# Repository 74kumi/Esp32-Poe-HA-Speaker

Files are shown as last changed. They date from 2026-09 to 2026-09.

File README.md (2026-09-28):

# ESP32 PoE Home Assistant Speaker

A PoE-powered network ceiling-speaker controller built around an **ESP32-S3**, **W5500 Ethernet**, **PCM5122 DAC**, and **TPA3116D2 amplifier**.

The long-term goal is a retrofit-friendly Home Assistant / voice-assistant speaker platform: reuse ordinary ceiling speakers, add network audio and control at the speaker, and optionally add a modular microphone-array ring hidden behind the existing grille.

## Project disclaimer

I'm not a hardware engineer — I'm an IT administrator who enjoys electronics, Home Assistant, and building things. I have a working understanding of many of the concepts involved, but this project has also been developed heavily with AI-assisted design, CAD scripting, and review.

I would genuinely welcome review or collaboration from experienced hardware engineers, especially as the project moves toward its first physical prototype.

This hardware is currently untested. It has not yet been fabricated, assembled, or electrically validated, and I cannot claim that the current design will work as intended. Please treat it as an engineering prototype, not a finished or proven product.

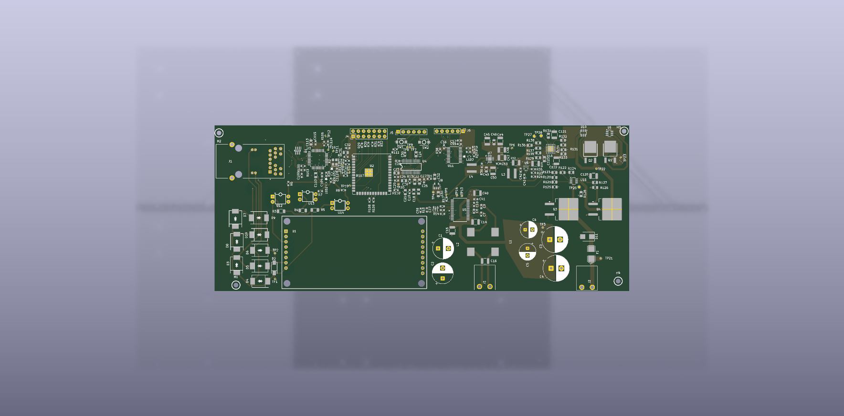
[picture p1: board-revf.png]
Final RevF manufacturing-release board preview


> **RevF manufacturing release:** this is the finalized manufacturing handoff for the RevE PCB design. The electrical CAD revision remains RevE for traceability; RevF identifies the released manufacturing package.
>
> The design has not yet been physically fabricated or electrically validated. PCBWay should confirm the final 4-layer stack-up and 100 Ω Ethernet impedance before production.

## Project status

| Area | Status |
| --- | --- |
| Main-board schematic / PCB | Rev E finalized design |
| KiCad source | Rev E source available directly in this repository |
| Saved ERC / DRC | Clean under the current saved rule profile |
| Ethernet layout | Finalized: 0.2764 mm / 0.20 mm target geometry |
| Power / protection | Finalized manufacturing package |
| Audio / amplifier | Circuit and thermal validation still required |
| Firmware | Bring-up firmware not yet complete |
| Home Assistant integration | Planned, not yet validated |
| Microphone array | Modular ring concept defined; PCB not yet designed |
| Physical prototype | Not built yet; fabrication package prepared |

A clean ERC/DRC result is a regression check, not proof that the circuit is electrically correct or fabrication-ready.

## Current hardware

The main board is intended to provide:

- ESP32-S3 controller
- wired Ethernet using W5500
- PoE-powered operation with bench-power support for development
- PCM5122 playback DAC
- TPA3116D2 speaker amplifier
- target of approximately **30 W into 4 ohms**, subject to real prototype validation
- programming / debug access
- expansion interfaces, including the reserved J4 microphone-ring connector

### Current Rev E board preview

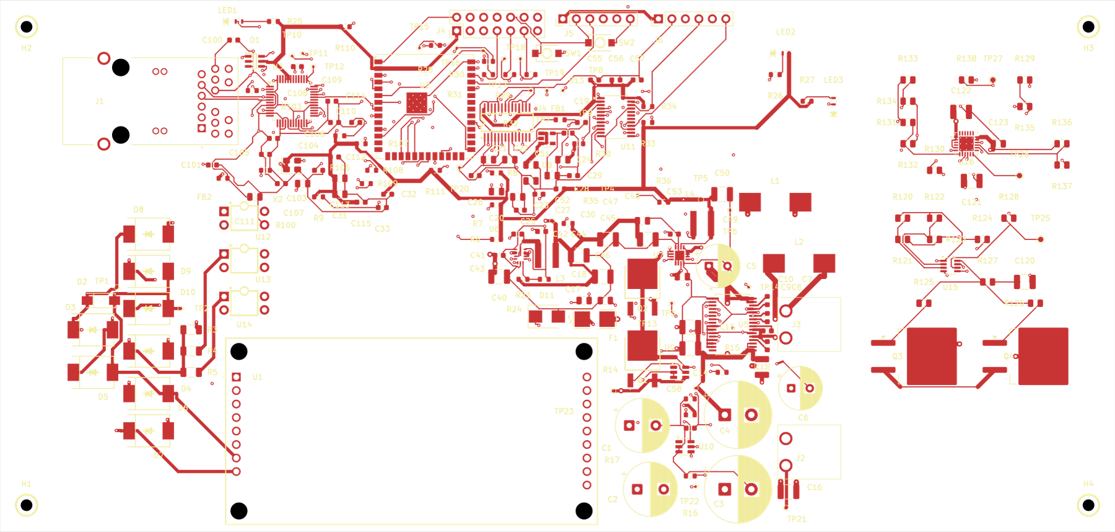
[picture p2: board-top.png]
Current Rev E board preview


The image above reflects the current Rev E board source more closely than the historical 3D render at the top of this README. The KiCad files remain the authoritative design reference.

### Open the Rev E design

The active source is tracked directly in Git:

- [Rev E KiCad project](hardware/PoE-Speaker/RevE/KiCad-RevE/PoE-Speaker-RevE.kicad_pro)
- [Rev E PCB](hardware/PoE-Speaker/RevE/KiCad-RevE/PoE-Speaker-RevE.kicad_pcb)
- [Rev E schematic](hardware/PoE-Speaker/RevE/KiCad-RevE/PoE-Speaker-RevE.kicad_sch)
- [Rev E engineering notes](hardware/PoE-Speaker/RevE/engineering/)
- [RevF manufacturing package](hardware/PoE-Speaker/RevF/Manufacturing/README-PCBWay.md)
- [RevF board preview](board-revf.png)
- [Historical design checkpoints](hardware/checkpoints/)

Open the project in **KiCad 10**. Keep the adjacent project-local footprint library, symbol library, tables, and design rules together.

## Modular microphone rings

A separate family of microphone-array rings is planned for retrofit installations. The idea is to select a ring diameter that fits behind an existing ceiling-speaker grille rather than designing a unique microphone system for every speaker model.

The first reference target is a nominal **8-inch ceiling speaker with an approximately 9-inch / 229 mm grille**. Ring Rev A is intended to target eight microphones and reserve space for visible listening / privacy status lighting behind the grille.

- [Microphone-ring concept](hardware/microphone-rings/README.md)
- [Listening / status-light plan](hardware/microphone-rings/LED-STATUS-LIGHT-PLAN.md)
- [Main-board J4 connector definition](hardware/PoE-Speaker/RevE/engineering/CONNECTOR-GUIDE.md)

Optional ring features are intended to use the existing J4 expansion interface rather than forcing repeated main-board redesigns.

## Engineering status and roadmap

The current release state is **RevF manufacturing package prepared**. PCBWay stack-up/impedance confirmation and normal prototype validation remain before production approval.

Highest-priority work includes:

1. Ethernet MDI differential-pair routing, reference continuity, termination / ESD geometry, and stackup assumptions.
2. PoE / bench input protection, startup, inrush, fault behavior, fuse coordination, and current-carrying paths.
3. PCM5122 / TPA3116D2 implementation, regulator behavior, grounding, output filtering, and thermal assumptions.
4. Footprint, courtyard, connector, heatsink, clearance, and assembly-process review.
5. Reproducible manufacturing outputs and a controlled prototype bring-up plan.

Project documents:

- [Roadmap](ROADMAP.md)
- [Engineering review guide](ENGINEERING-REVIEW.md)
- [Order / release review](ORDER-RELEASE-REVIEW.md)
- [Prototype validation plan](PROTOTYPE-VALIDATION.md)
- [Contribution guidance](CONTRIBUTING.md)
- [GitHub issues](https://github.com/74kumi/Esp32-Poe-HA-Speaker/issues)

## Repository layout

```text
.
├── docs/
│   ├── HISTORY.md
│   └── images/
│       └── early-board-render.png
├── hardware/
│   ├── PoE-Speaker/
│   │   └── RevE/
│   │       ├── KiCad-RevE/        # current editable board source
│   │       └── engineering/       # design reviews, calculations and scripts
│   ├── microphone-rings/          # future mic-array / status-light work
│   └── checkpoints/               # historical board revisions
├── ENGINEERING-REVIEW.md
├── ORDER-RELEASE-REVIEW.md
├── PROTOTYPE-VALIDATION.md
├── ROADMAP.md
└── board-top.png
```

## Contributing / reviewing

Engineering review is welcome, especially around Ethernet signal integrity, protection / fault behavior, power conversion, amplifier implementation, thermal design, footprints, and manufacturability.

When reporting a hardware finding, please include the affected revision, component / pin / net, location where practical, expected behavior, observed concern, and supporting datasheet section or calculation. Clearly distinguish confirmed defects from questions or suggested improvements.

See [CONTRIBUTING.md](CONTRIBUTING.md) for the current review priorities and main-board change policy.

This project has used AI-assisted CAD scripting and review workflows. AI output is not treated as engineering validation; independent review and physical prototype measurements are still required.

## License

Original hardware design materials are available for personal, educational, research, and other noncommercial use under the terms in [LICENSE](LICENSE).

Commercial manufacture, sale, OEM use, paid integration, or other commercial exploitation requires a separate written commercial license from the copyright holder.

Software, firmware, scripts, and third-party material may be subject to separate terms. Vendor references, library content, trademarks, and datasheets retain their respective owners' rights and notices.

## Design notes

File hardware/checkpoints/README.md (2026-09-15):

# Historical hardware checkpoints

This directory preserves earlier source snapshots for traceability while the active design continues under `hardware/PoE-Speaker/`.

These folders are **historical references**, not the canonical source to edit for new work and not manufacturing-release packages.

The imported checkpoint set includes earlier board stages such as the first-board draft, Rev C integrated draft, Rev D eFuse draft, and a frozen Rev E review snapshot.

The active Rev E source lives at:

`hardware/PoE-Speaker/RevE/`

The frozen Rev E checkpoint may initially match the active source byte-for-byte. Once active development continues, the two trees are expected to diverge; the checkpoint should remain unchanged so it can serve as a historical reference.

When starting new engineering work, use the active source and current root-level roadmap / review documents rather than these snapshots unless you are intentionally comparing revisions.

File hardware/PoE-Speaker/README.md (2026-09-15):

# Active PoE Speaker hardware source

This directory contains the **current active main-board design** for the ESP32 PoE Home Assistant Speaker project.

## Current revision

The canonical editable source is:

`RevE/KiCad-RevE/PoE-Speaker-RevE.kicad_pro`

Open it in **KiCad 10** and keep the project-local libraries, tables, design rules, and supporting files together.

The adjacent `RevE/engineering/` directory contains design-review notes, calculations, scripts, fabrication-process notes, connector documentation, and saved reports used during the Rev E engineering review.

## Source policy

- Active editable KiCad source belongs here.
- Historical board snapshots belong under `../checkpoints/`.
- Manufacturing-release outputs should be generated from a specific reviewed/tagged source revision and clearly identified as release artifacts rather than active design source.
- KiCad session/local-state files and editor backups should not be committed.

The current board remains an engineering prototype. A clean ERC/DRC result does not establish electrical performance, safety, signal integrity, thermal performance, or manufacturing readiness.

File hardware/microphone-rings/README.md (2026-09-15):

# Modular microphone-ring concept

## Purpose

The PoE speaker project is intended to support a family of microphone-array rings that can be adapted to many existing ceiling speakers without requiring a speaker-specific electronics design.

The concept is simple: remove the ceiling-speaker grille, choose the largest microphone ring that fits cleanly behind or within the grille, mount it around the speaker opening, route a small cable to the rear electronics, connect it to the main PoE speaker board, and reinstall the grille.

The microphone ring should be visually hidden once the grille is installed. The speaker itself remains the acoustic output device; the ring adds distributed microphones around the perimeter for room/voice capture.

This document describes the concept only. Ring PCB layouts, microphone selection, mounting methods, acoustic performance, firmware, and production dimensions are not yet validated.

## First reference speaker / Ring Rev A target

The first mechanical prototype will use a common **8-inch ceiling speaker with an approximately 9-inch (229 mm) overall grille diameter** as the reference test subject.

This reference is intentionally described by geometry rather than vendor/model. It provides a concrete starting point for the first ring while keeping the long-term goal of compatibility with many speaker families.

Initial Rev A assumptions:

| Parameter | Initial target / note |
| --- | --- |
| Nominal speaker size | 8 in |
| Measured overall grille diameter | ~9 in / 229 mm |
| Ring location | Behind the perforated grille, near the outer perimeter |
| Microphone orientation | Acoustic ports facing toward the room through the grille |
| Center opening | Keep the woofer/tweeter acoustic path substantially unobstructed |
| Microphone count | 8 target |
| Main-board interface | J4 |
| Cable routing | From ring toward rear electronics using an existing path where possible |

The **9-inch grille diameter is not the PCB diameter**. Before laying out the Rev A PCB, the grille must be removed and the actual usable inside diameter, frame lip, woofer surround clearance, grille-retention features, and available component depth measured. The PCB outside diameter should include installation clearance rather than attempting to fill the entire grille.

A practical first estimate is to target a microphone circle close to the largest clear diameter available behind the grille while keeping a narrow PCB annulus. Final OD/ID values should be based on direct measurements of the reference speaker, not the nominal 8-inch driver size.

## Design philosophy

The main PoE speaker board should remain common across installations. Speaker compatibility is handled mechanically by selecting a ring of the appropriate diameter.

Instead of making a different complete electronics system for every ceiling-speaker model, the project should eventually provide several ring diameters using the same electrical interface and microphone topology.

A useful installation should require as little modification to the existing speaker as practical:

1. Remove the speaker grille.
2. Measure the usable clear diameter behind the grille.
3. Select the largest ring variant that fits without interfering with the woofer, tweeter, grille attachment, mounting hardware, or speaker suspension.
4. Mount the ring to the grille/frame or to a small adapter using a reversible method where practical.
5. Route the ring cable toward the rear of the speaker. An existing opening is preferred. A new cable pass-through may be added only when doing so does not damage the driver, wiring, enclosure, fire rating, listing, or structural integrity of the speaker assembly.
6. Mount the PoE speaker electronics in an appropriate protected location behind/near the speaker.
7. Connect the microphone ring to the main board and reinstall the grille.

The result should look like an ordinary ceiling speaker from the room.

## Ring family

Ring sizes should be defined by geometry rather than by a specific speaker brand or model.

Each ring variant should eventually document at least:

| Parameter | Meaning |
| --- | --- |
| PCB outside diameter | Largest physical diameter of the ring PCB |
| Clear inside diameter | Opening available for the speaker cone/tweeter/acoustic path |
| Microphone-circle diameter | Diameter through the microphone acoustic ports |
| Microphone count | Intended number of microphones on the ring |
| Mounting envelope | Space needed for clips, adhesive mounts, screws, or an adapter |
| Maximum component height | Clearance required behind the grille |
| Cable exit | Location and direction of the ring cable/connector |
| Intended grille range | Approximate speaker/grille dimensions that can accept the ring |

Exact standard sizes are intentionally TBD. The first useful set should be chosen after measuring several common ceiling speakers rather than guessing from nominal woofer size alone.

A future naming scheme could use the microphone-circle or PCB outside diameter in millimeters so the name describes geometry rather than a vendor model.

## Electrical interface

The current Rev E main board reserves connector **J4** for the future microphone ring.

J4 exposes:

- 3.3 V power and grounds
- one shared `PDM_CLK`
- four PDM data signals: `PDM_DATA0_CONN` through `PDM_DATA3_CONN`
- `I2C_SDA` and `I2C_SCL`
- one spare ring GPIO

The project target is an eight-microphone ring. A likely implementation is to arrange compatible PDM microphones around the perimeter and use the four PDM data lanes for paired microphones, but the exact microphone parts, pairing method, clock rate, loading, cable constraints, connector implementation, and firmware capture scheme still require engineering validation.

The ring should not require a different main-board connector for each diameter. Electrically compatible ring sizes should be interchangeable.

## Mechanical goals

The microphone ring should:

- fit behind a perforated ceiling-speaker grille and remain visually unobtrusive;
- keep the center substantially open so it does not block the woofer or coaxial tweeter;
- avoid contact with the moving cone, surround, tweeter assembly, grille, or mounting dogs/clamps;
- tolerate speaker vibration without rattling;
- provide strain relief for its cable;
- support simple mounting methods such as clips, small standoffs, removable adhesive fixtures, or model-specific 3D-printed adapters;
- minimize required permanent modification to an existing speaker;
- allow multiple PCB diameters while keeping the same electrical design where practical.

A circular PCB is the default concept, but segmented or multi-piece rings may be considered if full circular PCBs become unnecessarily expensive at larger diameters.

## Acoustic goals and risks

The ring is intentionally close to a loudspeaker, which creates significant acoustic challenges. Mechanical fit alone is not sufficient.

Future prototypes need to evaluate:

- microphone self-noise and sensitivity through the installed grille;
- consistency between microphone positions;
- vibration mechanically coupled from the speaker/frame into the microphones;
- airflow and pressure effects near the woofer;
- acoustic shadowing caused by the speaker frame or grille structure;
- microphone saturation while the local speaker is playing;
- echo cancellation / speaker-reference requirements for simultaneous playback and voice capture;
- beamforming performance at different ring diameters;
- whether microphone spacing creates useful or harmful spatial aliasing over the intended voice band.

Ring diameter should therefore be treated as an acoustic parameter as well as a mechanical one.

## Installation and safety constraints

The goal is broad retrofit compatibility, not permission to modify every speaker indiscriminately.

Do not drill or modify a speaker assembly when doing so would compromise a listed backcan, fire/plenum rating, transformer enclosure, mains/high-voltage wiring, structural mounting, warranty, or other required safety feature. When an existing cable path is available, use it.

The microphone ring and main electronics also need an installation method that cannot fall into the occupied space if a grille or adhesive mount fails.

## Proposed development sequence

1. Fully measure the 8-inch / ~9-inch-grille reference speaker: usable grille ID, frame lip, clear ring area, depth, grille-retention features, obstructions, and cable-routing options.
2. Use those measurements to define Ring Rev A OD, ID, microphone-circle diameter, board width, component-height limit, mounting points, and cable exit.
3. Select and electrically validate the PDM microphone topology against J4.
4. Build Ring Rev A and prove microphone capture before producing every mechanical size.
5. Evaluate mounting approaches behind the reference grille.
6. Test microphone response with the local speaker silent and playing.
7. Evaluate beamforming / direction finding / voice capture and echo-cancellation requirements.
8. Measure several other common ceiling speakers and choose additional ring diameters that cover meaningfully different geometries.
9. Once the electrical design is stable, replicate the same circuit topology into those additional ring diameters.

## Relationship to the main board

The microphone ring is a separate future PCB from the Rev E PoE speaker main board. Development of the ring should not block first-prototype validation of Ethernet, power, DAC, and amplifier functions on the main board.

The current J4 interface is a design provision, not proof that an eight-microphone capture system is complete or validated.

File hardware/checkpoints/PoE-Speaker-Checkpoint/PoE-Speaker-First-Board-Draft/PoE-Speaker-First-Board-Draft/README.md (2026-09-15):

# PoE speaker — Revision B development

Open `PoE-Speaker-RevB.kicad_pro` in KiCad 10. This revision is **not ready for fabrication**. The original migration is preserved separately in `../KiCad-Recovered`.

## Changes implemented

- ESP32-S3-WROOM-1U-N16R8 and W5500 replace the original ESP32/RMII architecture. Four PDM data lines reserve support for eight microphones on a future separate ring. GPIO35–37 remain unused because the module uses octal PSRAM.
- J1 cable-side PoE pickup uses pins 13–16. PHY-side center taps 12 and 6 now belong to the W5500 interface. Pins 1 and 7 are unused.
- W5500 analog supply filtering, termination, reference resistor, reset delay, SPI damping and 25 MHz oscillator are included.
- C1–C6 now use physical radial capacitor footprints and specified Panasonic FR parts. L1–L4 use rated inductors and footprints constructed from manufacturer land patterns.
- TP10 and TP11 now expose SPI clock and MOSI.
- Local symbol and footprint libraries travel with the project. Thirteen editable schematic pages and 179 footprints are generated.

## Validation and limits

`reports/net-validation.json` compares the KiCad-exported schematic netlist and saved PCB pad assignments to the explicit revised model. This checks file generation and pin mapping; it does not prove that the circuit works. `reports/schematic-svg` contains KiCad-rendered sheets.

The board has a proposed 160 × 100 mm outline around the existing mounting holes. All 179 parts have been placed without expanded body-box overlaps. A local routing pass has produced actual editable copper; see `reports/first-board-draft.json` and `reports/board-drc.json` for the current counts and remaining findings. This is a **first layout draft**, not a production routing solution. Existing recovery copper was not copied because it does not implement the revised circuit.

The initial router uses 0.2 mm traces and 0.15 mm fine-pitch escapes. Those widths are **not a validated power-distribution design**. High-current paths, ground planes, Ethernet differential-pair geometry, isolation and heat flow still require dedicated routing work. Do not order this draft.

Most recovered components still use generic pin-block symbols with passive electrical pin types. ERC is therefore incomplete as a circuit check. Power-source pin modeling remains outstanding; do not suppress those errors as a substitute for reviewing the power circuit.

## Work remaining before release

1. Complete power and protection audit: PoE bridge reverse-voltage margin, Ag5800 series outputs, ORing, regulator compensation/layout, amplifier PBTL configuration and thermal limits.
2. Review remaining source component pin types, actual part numbers, voltage ratings and footprint pin mappings. Replace generic schematic graphics with conventional symbols where practical.
3. Refine placement for switching loops, isolation and audio performance. Verify mechanical clearances, mounting hardware and connector access.
4. Replace provisional power and Ethernet routes with qualified geometry; add appropriate planes/thermal vias and isolation clearances, choose a fabrication stackup and verify Ethernet impedance.
5. Resolve electrical and board checks without hiding findings. Produce fabrication and assembly outputs only after those checks pass.
6. Implement and bench-test firmware for simultaneous four-line PDM capture, DAC playback, SPI Ethernet and PoE power limiting. Speaker selection and microphone-ring geometry remain future inputs.

## Reproducibility

Run `engineering/design_revision.py`, then `engineering/build_revision.py` with KiCad's Python from the project root. Export a KiCad XML netlist to `reports/schematic-netlist.xml`, then run `engineering/validate_revision.py`. `engineering/place_draft.py` creates the placement and Specctra input; `engineering/finish_draft.py` imports the locally generated routing session. **The builder discards later placement and routing when rerun. Preserve the routed board before rebuilding.**

## Reference documents

- [ESP32-S3 module datasheet](https://www.espressif.com/sites/default/files/documentation/esp32-s3-wroom-1_wroom-1u_datasheet_en.pdf)
- [ESP32-S3 peripheral capability definitions](https://raw.githubusercontent.com/espressif/esp-idf/master/components/soc/esp32s3/include/soc/soc_caps.h)
- [W5500 datasheet](https://docs.wiznet.io/img/products/w5500/W5500_ds_v110e.pdf) and [reference circuit](https://docs.wiznet.io/img/products/w5500/w5500_sch_v110_use_mag_.pdf)
- [Bel 2250506 connector drawing](https://www.belfuse.com/media/drawings/products/magjack%20ICMs/dr-mag-2250506.pdf)
- [Bourns SRP1038A](https://www.bourns.com/docs/product-datasheets/srp1038a.pdf): 13.6 mm overall land span, 5.4 mm inner gap, 3.5 mm land height.
- [Coilcraft XAL50xx](https://www.coilcraft.com/getmedia/49bc46c8-4b2c-45b9-9b6c-2eaa235ea698/xal50xx.pdf): 3.31 mm pad-center pitch, 1.18 × 4.70 mm lands.
- [Abracon ASE oscillator](https://abracon.com/Oscillators/ASEseries.pdf)
- Panasonic [EEUFR1E102](https://industrial.panasonic.com/ww/products/pt/aluminum-cap-lead/models/EEUFR1E102), [EEUFR1V102](https://industrial.panasonic.com/ww/products/pt/aluminum-cap-lead/models/EEUFR1V102), [EEUFR1H101](https://industrial.panasonic.com/ww/products/pt/aluminum-cap-lead/models/EEUFR1H101).

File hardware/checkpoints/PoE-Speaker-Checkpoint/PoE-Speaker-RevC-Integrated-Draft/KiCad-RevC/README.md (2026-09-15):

# Revision C — integrated prototype development

Open PoE-Speaker-RevC.kicad_pro in KiCad 10. This is an editable engineering draft, not a board approved for manufacture or power-up. Revision B is preserved separately.

Implemented: bench-input LTC4365HTS8 disconnect, two PSMN4R8-100BSE pass MOSFETs, UV/OV dividers, controlled-startup candidate network, bidirectional input TVS selection, fault test point, and amplifier shutdown pulldown. The protection schematic is integrated into the project and its connections are routed. The provisional outline is expanded to 210 x 100 mm; mounting and enclosure fit are not final.

Added a partial secondary-side In1.Cu ground plane from x=140 to 279 mm, leaving the Ethernet area outside this plane. Widened 14 new power-route segments to 0.8 mm where DRC permitted. Improved reference placement and turned schematic net labels outward for readability. Source symbols remain boxed pin representations.

Verification: 194 footprints, 575 connected pins match the design model, zero unconnected items, no reported shorts or PoE isolation-rule findings. The preliminary 3 mm rule is not an insulation certification. See reports/revision-status.json and board-drc.json for exact counts. ERC retains four undriven power-input findings and many source pin types remain unreviewed.

Release blockers:

- Short-circuit current limiting, fuse coordination, and repetitive-fault heating are unresolved. The startup ramp is not a fault current limiter.
- Confirm gate-drive capability, MOSFET hot SOA, actual startup loads, amplifier-disable sequencing, and bench/PoE backfeed using the complete circuit.
- Finalize resistor/capacitor/TVS order codes, tolerances, voltage ratings, and transient envelope. Several new passive MPNs remain TBD.
- Six U15 pad-spacing findings reflect 0.15 mm footprint gaps against the 0.20 mm project constraint; qualify the fabrication process/land pattern. Do not simply suppress them.
- Resolve 57 narrow-track findings and 12 ESP32 footprint drill findings. Widths and via current capacity are not thermally qualified.
- Finish Ethernet impedance/return paths, switching-loop layout, ground/thermal copper, silkscreen, mechanical fit and remaining source circuit review.

No manufacturing Gerbers are included. The PNG is a routing preview with F.Cu, In2.Cu and B.Cu; the inner ground plane is intentionally not shown in that view.

Preservation: build_protection_revision.py regenerates the initial placement and will overwrite this layout if rerun. Copy/archive this project before regeneration. Subsequent routing, fill, width and label changes are in the saved PCB and separate engineering scripts.

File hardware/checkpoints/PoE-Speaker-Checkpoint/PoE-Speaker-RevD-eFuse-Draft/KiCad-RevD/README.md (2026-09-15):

# Revision D — shared current protection draft

Open PoE-Speaker-RevD.kicad_pro in KiCad 10. This editable development board is not approved for fabrication or power-up. Revisions B and C remain preserved.

Added TPS26630RGER after the bench/PoE ideal-diode junction, feeding all original 24V_AMP loads. The circuit targets a nominal 2.98 A current limit, latch-off behavior, controlled startup and power-good amplifier shutdown interlock. TP26 is the shutdown/reset point; TP27 exposes the fault output. See engineering/EFUSE-REVIEW.md for calculations and limitations. Eight microphones remain assigned to a future separate ring board.

The 210 x 100 mm provisional outline is unchanged from C. Retained routes were reused except the two nets split by this change. The secondary In1.Cu ground plane now extends under Ethernet while excluding the lower-left primary/module region. See reports/secondary-ground.png. The routing preview omits that plane so signal routing is visible.

Validation: all 616 connected model pins match both the schematic netlist and PCB pad nets. Specific checks confirm the eFuse supply split and amplifier interlock. Exact physical and electrical findings are below; an empty ratsnest does not establish electrical correctness. Most imported symbols still use boxed pin representations, and source electrical pin types need further review.

Release blockers: resolve remaining DRC and ERC findings; qualify high-current widths/vias and thermal copper; finish Ethernet impedance and return paths, switching loops, input transient/fuse coordination, hot-start and overload behavior, and exact passive order codes. U15 now uses the manufacturer-recommended 1.22 x 0.40 mm lands at 0.65 mm pitch. All narrow-track escapes have been repaired without relaxing rules. The 21 thermal vias are covered by a scoped 0.20 mm drill-process rule; see engineering/FABRICATION-PROCESS.md. DRC is clean under that documented profile, but assembly via treatment and final stackup require confirmation. The enclosure, mounting and final speaker are not fixed. No manufacturing release is included.

Do not rerun build_efuse_revision.py on this routed folder without first archiving it: generation recreates placement and removes later routing work.

## Saved validation counts

- revision: D shared eFuse development draft
- components: 209
- board_mm: [210, 100]
- track_segments: 2101
- vias: 264
- ground_zones: 1
- unconnected_items: 0
- drc: {}
- erc_findings: 5
- poe_isolation_findings: 0
- fabrication_ready: False

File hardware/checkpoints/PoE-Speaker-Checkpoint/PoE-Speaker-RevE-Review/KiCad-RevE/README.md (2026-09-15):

# Revision E — prototype review checkpoint

Open PoE-Speaker-RevE.kicad_pro in KiCad 10. This is the latest editable board. Earlier revisions remain preserved. NOT APPROVED FOR ORDERING OR POWER-UP.

Saved changes: C11 GVDD bypass is now local on B.Cu at (204.9,111.5), preserving the R15 PLIMIT branch; underside assembly clearance remains part of mechanical review. U7 FSW now connects to 3V3 per TI guidance; all previously missing passive/header order codes have documented candidates; C120/C121 use stable 100nF 100V C0G 1210 parts and C122 uses a 1uF 100V 1210 part. C17/C18 are a matched 2.2uF 25V pair. U5 is TPA3116D2DADR, U9/U10 are LM5050MK-2/NOPB, and Ag5800 is confirmed as the complete U1 code. Corrected 34 footprint assembly attributes and widened 51 power segments to 0.8mm where existing clearance permits.

Validation: zero DRC findings, zero unconnected items, zero ERC findings under the saved rule profile. All 616 connected model pins match schematic and PCB. U6/U7 electrical pin types are reviewed; the root sheet declares power sources after passive elements. These annotations do not prove circuit performance, and other imported pin types remain incomplete. See reports/power-source-review.json. Missing courtyard and some metadata checks remain disabled in the inherited profile; clean DRC does not substitute for physical review.

Remaining work before a prototype order:

1. Reroute the remaining narrow loaded power paths, review via current capacity and local switching loops. reports/power-routing-audit.json contains exact positions and UUIDs; separate low-current sense branches from load trunks before modifying them. The two longest 24V_AMP sections (49.385mm and 39.837mm) have now been rerouted at 1.0mm width. A new continuous 1.0mm feed from C5 to the amplifier supply bypasses the congested narrow branch using two 0.5mm drilled vias. The original branch remains in parallel. See engineering/REVE-TRUNK-ROUTING.md; the whole path is not yet current-qualified.
2. Qualify Ethernet differential routing against the explicit JLC04161H-7628 design baseline and verify continuous return paths. See engineering/ETHERNET-STACKUP.md; the calculator-derived Ethernet100 routing preset is saved, but copper still needs rerouting and fabrication confirmation.
3. Review input fuse/transient coordination, capacitor effective capacitance and regulator stability, and amplifier supply tolerance. F1 DC interrupt ratings are now sourced; source/fault and time-current coordination remain open (engineering/FUSE-RATING-REVIEW.md).
4. Fit a top heatsink to the TPA3116D2 DAD package, check the Ag5800 thermal interface, body clearances, mounting support and connector access. H3/H4 now support the extended right edge at x=275; use insulating M2 standoffs. Thirteen assembly components still need verified courtyard/body review.
5. Produce and inspect Gerber, drill, assembly BOM and placement files only after those design checks; obtain fabricator stackup/via-treatment constraints. No manufacturing files or order submission are included in this checkpoint.

After assembly: staged current-limited bring-up, rail/startup/overload measurements, firmware and audio/Ethernet tests. Those are prototype validation activities, not prerequisites that can be completed without hardware. The eight-microphone ring remains a future separate board; this board is not a completed eight-microphone capture system.

Preserve routing: do not run build_revision.py or build_efuse_revision.py over this folder. For schematic-only updates run refresh_prototype_schematic.py, then annotate_prototype_power.py, export netlist/ERC and run validate_prototype.py. Editing model metadata alone does not update the schematic.

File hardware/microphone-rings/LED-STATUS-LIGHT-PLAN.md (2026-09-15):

# Microphone-ring status / listening light plan

## Purpose

Future microphone-array rings should reserve support for visible status lighting behind the ceiling-speaker grille. The primary use is a subtle **listening indicator** so a person in the room can tell when the microphone system is active.

The lighting feature belongs to the microphone-ring assembly, not the main PoE speaker PCB. Different ring diameters should use the same control concept wherever practical.

This is a planning document. LED part selection, LED count, driver choice, brightness, diffuser behavior, current budget, and firmware behavior are not yet validated.

## Main-board design-freeze rule

The Rev E / Rev F main PoE speaker board should not be redesigned for optional ring features unless the existing expansion interface cannot safely support a required function.

For microphone-ring lighting, the existing J4 interface is the intended path. J4 already exposes:

- 3.3 V and grounds;
- `I2C_SDA` and `I2C_SCL`;
- `RING_GPIO_SPARE`;
- the PDM microphone clock/data signals required by the microphone ring.

Optional user-interface features should therefore be implemented on the ring using J4 before considering changes to the main board.

A proposed main-board change for a ring feature should identify:

1. the feature that cannot be implemented through the existing interface;
2. the electrical, safety, bandwidth, power, or reliability reason it cannot be implemented there;
3. the minimum main-board change required; and
4. how the change will be verified.

Convenience alone is not sufficient reason to reopen the main-board design.

## Intended visual states

The exact colors and behavior remain firmware/UI decisions, but the ring should be capable of communicating a small set of obvious states.

| State | Example indication | Intent |
| --- | --- | --- |
| Listening / microphones active | soft blue or white | visible privacy/status indication |
| Muted / privacy mode | red | microphones intentionally disabled |
| Boot / setup / provisioning | amber, purple, or slow pulse | temporary service state |
| Fault / attention required | red or amber pattern | diagnostic indication |
| Normal idle | off by default | avoid unnecessary room light |

The final behavior should favor clear status communication over decorative effects.

## Electrical approach

Do not assume that the ESP32 or J4 spare GPIO will directly drive the LEDs.

The preferred architecture is for the microphone ring to contain its own small LED-control stage, using either:

- an I2C LED driver;
- a small ring-local controller; or
- another low-current control method compatible with the existing J4 signals.

The main board should send state information; the ring should handle LED current and sequencing locally.

The exact implementation must be chosen only after the available **3.3 V current budget at J4** is verified. The current design documentation does not yet establish how much additional LED load J4 can safely supply.

Until that budget is known, Ring Rev A should assume modest indicator lighting rather than a high-current decorative RGB ring. Full-brightness addressable RGB operation must not be assumed safe merely because 3.3 V is present on J4.

If the available J4 power budget is insufficient, first evaluate reducing LED count/current or adding appropriate ring-local power handling before reopening the main-board design.

## Mechanical / optical goals

Status LEDs should be placed so that light is visible through the perforated speaker grille while the PCB itself remains hidden.

Design goals:

- distribute light around the ring rather than create one bright point;
- avoid direct glare when viewed from below;
- avoid light leaking into the speaker cavity in a way that is distracting;
- keep LEDs and optics clear of microphone acoustic ports;
- avoid blocking useful grille perforations in front of microphones;
- support different ring diameters without changing the main-board interface;
- allow brightness to be reduced substantially for dark rooms.

The grille itself may provide useful diffusion, but this must be tested on real speakers because grille hole size, paint, backing cloth, and spacing vary.

## Ring Rev A requirements

The first ring for the nominal 8-inch speaker / ~9-inch grille reference installation should reserve for status lighting from the beginning.

Before PCB layout is frozen, Rev A should define:

- candidate LED locations around the ring;
- routing/footprint space for the chosen driver or local controller;
- LED-control connection to J4 through I2C and/or `RING_GPIO_SPARE`;
- estimated worst-case and normal LED current;
- microphone-to-LED spacing so lighting components do not compromise acoustic-port placement;
- a firmware-safe default state where LEDs are off until intentionally enabled.

The first prototype does not need elaborate animations. Proving a uniform, low-brightness listening indication through the installed grille is sufficient.

## Validation

Prototype testing should record:

1. J4 supply voltage and current with LEDs off and at intended maximum brightness;
2. whether LED operation introduces noise into PDM microphone capture;
3. whether PWM or digital LED traffic couples into audio or microphone signals;
4. light uniformity through the installed grille;
5. visibility in normal room lighting and in a dark room;
6. temperature rise of LED/driver components;
7. whether the listening/mute indication remains understandable from typical room viewing positions.

Any LED implementation that materially degrades microphone performance should be revised even if the visual result is good.

## Relationship to the microphone-ring family

Status lighting is a shared capability of the ring family, not a reason to create electrically incompatible ring sizes. Mechanical dimensions may change with speaker/grille size, but compatible rings should retain the same J4 interface and status-control behavior wherever practical.

The long-term goal is that selecting a different ring diameter changes the mechanics, not the main PoE speaker board.

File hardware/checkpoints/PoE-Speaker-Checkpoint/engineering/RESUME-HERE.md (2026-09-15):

# Resume checkpoint

Latest: KiCad-RevE/PoE-Speaker-RevE.kicad_pro and PoE-Speaker-RevE-Review.zip. Read KiCad-RevE/README.md first. Zero DRC, zero unconnected, zero ERC; 616 connected pins validated. No missing candidate order codes, but procurement and circuit qualification remain incomplete. Revisions B/C/D preserved.

Next: inspect RX ESD/termination branches and reference continuity, then finish TX_P layer/coupling. The RX trunk now has 8.379 mm of parallel routing at the sourced 0.225806 mm width / 0.2032 mm gap and a direct PHY approach; see reports/rx-coupled-trunk.json. The coordinated TX_N fanout and replacement B.Cu analog-supply path now allow all five receive In2 segments onto F.Cu; accepted with clean DRC and connectivity. See reports/ethernet-front-corridor.json. Existing bottom termination/ESD branches remain. Reroute using the sourced Ethernet100 preset (0.225806 mm width / 0.2032 mm gap), F.Cu over In1 GND on JLC04161H-7628; see engineering/ETHERNET-STACKUP.md. The main board now has explicit dielectric/copper settings, but impedance is not qualified. RX termination R104/R105/C102 is now a compact B.Cu cluster near U3, with twelve obsolete spur items removed and a checked local ground via (reports/rx-termination-placement.json). Main pair routing remains unqualified. Prioritize this and the concrete release blockers in engineering/ORDER-RELEASE-REVIEW.md. Mounting and eight rectifier courtyards are updated. After that, review remaining amplifier ground-pin-to-plane paths using reports/amp-ground-plane-paths.json, especially pin 1 and pins 9-11. Pin 13 now has a short 0.35 mm connection to the existing C11 ground via, improving the lower ground group; the pin 1 via trial was rejected and removed. A new via at (209.88,112.453) gives pin 22 local filled-plane access; downstream return impedance and continuous current corridors remain unqualified. Twenty-one direct ground-pin track segments were widened to 0.25-0.4 mm with clean DRC; this includes tiny stubs and does not qualify complete ground returns (reports/amp-ground-pin-widths.json). C14/C15 now have accepted local 0.8/0.4 mm ground vias with 1.1 mm, 0.6 mm wide links; both contact the filled In1 GND zone (reports/c14-c15-ground-vias.json). Use reports/amplifier-ground-access.json; it is a geometry inventory, not return-loop qualification. C5/C6 plated through-hole grounds must be assessed for direct plane access rather than distance to separate vias. Six constrained load-path vias remain. Twelve load-path vias have accepted larger drills/copper pads, including the relocated eFuse output via; see reports/power-via-review.json. Via current ratings still require plating and stackup assumptions. Four remaining load-neck segments are now 0.6 mm; the 0.3 mm wide, 0.5 mm long U16 output pin escape remains to preserve adjacent-pad clearance. See reports/load-neck-width-trial.json and reports/supply-path-audit.json. Continue amplifier review using reports/amplifier-decoupling-audit.json. C11 is accepted on B.Cu at (204.9,111.5), angle 270, with a local GVDD connection and a separate ground via. The R15 PLIMIT branch is preserved. Five obsolete C11 spur items were removed; see engineering/REVE-TRUNK-ROUTING.md. Continue amplifier decoupling and output-current/ground-return qualification. C13 is now local on F.Cu at (213.5,119); C12 is on B.Cu at (207.4,104) with a short connection through the existing supply via. Account for underside assembly and enclosure clearance. All four bootstrap capacitors now have accepted local F.Cu connections. C8 required an In2.Cu output detour with two 0.5mm drilled vias and a short 0.6mm approach that still needs current/thermal qualification; see reports/bootstrap-routing-audit.json and engineering/REVE-TRUNK-ROUTING.md. The main board is clean. Use the named main board, not temporary trial files. Both audited bench load paths now have at least 0.6mm tracks throughout, with no track below 0.5mm; current/via/thermal qualification remains; see reports/supply-path-audit.json. Three more 0.6mm bench approaches are accepted, and the ESP32 3V3 feed is at least 0.6mm throughout. Then complete Ethernet stackup/routing, fuse/transient/stability and thermal/mechanical review. Do not claim manufacturing ready from zero rule-check counts. No Gerbers/order submission yet. Firmware and ring board are not completed.

Schematic update: refresh_prototype_schematic.py followed by annotate_prototype_power.py; regenerate netlist/ERC and validate_prototype.py. Model: engineering/revision-e-design.json. Most useful current scripts contain prototype in their name. Source capacitor PDFs are in engineering/sources/prototype-capacitors. Checkpoint ZIP includes source, model, scripts and reports.

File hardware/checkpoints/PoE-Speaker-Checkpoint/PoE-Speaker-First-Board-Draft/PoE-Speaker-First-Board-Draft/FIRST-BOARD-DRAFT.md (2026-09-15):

# First board draft — review copy

Open `PoE-Speaker-RevB.kicad_pro` in KiCad 10. **Not for fabrication or power-up.**

The 160 × 100 mm draft contains 179 placed footprints, 1814 track segments and 222 vias. KiCad reports 0 unconnected items. The saved schematic and PCB pad assignments match the revised electrical model.

The body-box placement check passes. This is an initial placement and routing study; it does not validate enclosure fit, circuit operation or manufacturability.

## Current checks

| KiCad finding | Count |
|---|---:|
| drill_out_of_range | 12 |
| silk_edge_clearance | 1 |
| silk_over_copper | 84 |
| silk_overlap | 81 |
| track_width | 57 |

## Before a prototype order

- Complete the PoE and bench-input protection changes described in `POWER-REVIEW.md`.
- Redesign high-current routes. Net-specific wider trunks still have narrow escapes and unqualified vias and return paths.
- Add and review ground planes, isolation boundaries and thermal copper. Check buck and amplifier switching loops.
- The explicit 3 mm primary-to-secondary copper review rule now has zero findings. This is a preliminary layout target, not an insulation certification.
- Qualify or replace the U5 pin 27 via-in-pad escape for assembly and current capacity.
- Route Ethernet pairs to the chosen stackup and impedance requirements.
- Complete pin-type/ERC review, silkscreen cleanup and footprint/manufacturing checks. The ESP32 module footprint includes 0.2 mm thermal holes against a current 0.3 mm board constraint; resolve the footprint/process choice.
- Verify all release checks, then generate fabrication outputs. No manufacturing Gerbers are included in this review package.

The microphone ring remains a separate future board. The mainboard reserves its eight-microphone interface.

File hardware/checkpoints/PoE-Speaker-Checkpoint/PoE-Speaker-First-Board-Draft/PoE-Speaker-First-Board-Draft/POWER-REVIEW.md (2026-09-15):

# Power review — 2026-09-11

Status: in progress, not a release approval.

## Layout pass after the first draft

115 power trunk segments longer than 2 mm were widened to preliminary targets of 0.6–1.5 mm according to net function. Ninety-two other attempted changes conflicted with existing copper and were reverted. Short escapes, vias and return paths remain unqualified; this does not establish the current capacity of a complete path. The final standard-clearance check retained zero unconnected items and no shorts/crossings.

An explicit 3 mm primary-to-secondary copper review rule now identifies 16 spacing findings. This target is a conservative layout assumption, not a certified creepage/clearance requirement. The optocoupler placement and routing need particular attention: some primary pins face toward the secondary circuitry, and the router passed secondary tracks near primary through-hole pads. Reorient the optocouplers and reroute their paths while preserving the electrical pin map. Also review the Ag5800 underside barrier against the manufacturer's drawing. The module's dielectric rating alone does not qualify the carrier PCB.

The active KiCad DRC report includes the stricter rule; the earlier ordinary 0.2 mm clearance result is retained separately as `reports/standard-clearance-drc.json`.

## Corrected in the design model

**PoE class detection:** R6, R7 and R8 were connected from the PC817 collectors to GND. The emitters are also grounded, so that arrangement cannot generate the intended high logic level when the optocouplers are off. Resistor pin 2 now connects to 3V3. Detection is active low. Firmware must use that polarity.

**5 V buck:** U6 is LMR33630AQRNXRQ1, RNX VQFN. Pin 3 was marked NC and left open. TI's pin-function table explicitly requires this package's NC pad to connect to SW. Pin 3 now joins BUCK5_SW with pin 12. The bootstrap loop must be kept short in layout. [TI datasheet, section 5](https://www.ti.com/lit/ds/symlink/lmr33630-q1.pdf)

## Connections checked, retained

- Ag5800: output 1 is between POE_12V_MID and GND; output 2 is between 24V_POE and POE_12V_MID. C1 and C2 each span their respective output with positive polarity toward the higher voltage. This is the intended series-output arrangement. [Silvertel datasheet, sections 4 and 5.11](https://productinfo.silvertel.com/products/POE/PD/Ag5800/Ag5800v1-4.pdf)
- LM5050-2: IN and the external MOSFET source are on each incoming supply; OUT and drain are on the shared 24V_AMP rail; OFF is grounded. This is the basic forward ORing arrangement. It is not a complete reverse-input or overvoltage protection circuit. [TI LM5050-2 datasheet](https://www.ti.com/lit/ds/symlink/lm5050-2.pdf)
- The 5 V feedback divider is 100k/24.9k. With a nominal 1 V reference, its calculated output is 5.016 V. This calculation does not include reference/resistor tolerances or load regulation.

## Unresolved release blockers

**Bench-input surge protection:** D11 is SMBJ26A. Its 26 V standoff rating must not be interpreted as a 26 V clamp. The amplifier rail is fed through an ideal-diode controller, which does not regulate overvoltage. The regulator is rated for 36 V operation and 38 V absolute maximum; the amplifier's supply limit must also be respected. Coordinate an actual overvoltage-disconnect/clamping design with the input transient specification. Do not select a lower-standoff TVS blindly: it must also tolerate the normal supply. [Vishay SMBJ data](https://www.vishay.com/docs/88392/smbj.pdf), [TI amplifier data](https://www.ti.com/lit/ds/symlink/tpa3116d2.pdf)

**PoE bridges:** D3–D10 now select B5100C, 100 V, in SMC. Thermal design and TVS coordination remain open.

**Remaining review:** detector LED current/resistor dissipation over the PoE voltage range; TVS coordination at the Ag5800 input; regulator passives and soft start; amplifier PBTL/gain/PLIMIT/startup behavior; fuse coordination and reverse bench-input protection; isolation and thermal layout. The schematic and PCB still contain other unreviewed source components.

## Isolation layout update — 2026-09-12

U12–U14 now place their primary pins to the left and secondary pins to the right. The rerouted board passes the preliminary 3 mm primary-to-secondary copper clearance rule with zero findings, zero unconnected items, and no copper shorts or ordinary clearance findings. This supersedes earlier isolation-layout findings; it does not certify insulation or resolve the outstanding protection and thermal design. U5 pin 27 uses a provisional 0.5 mm diameter / 0.3 mm drill via-in-pad escape; qualify assembly and current capacity or redesign it.

## Bridge selection update — 2026-09-12

D3–D10 changed from 60 V SS56 to Diodes Incorporated B5100C (100 V). Its 5 A rating requires the specified case/lead temperature; it is not a free-air board rating. Maximum forward drop is 0.85 V at 5 A. [Manufacturer datasheet](https://www.diodes.com/datasheet/download/B5100C.pdf).

The SMC drawing was compared with the recovered pads: 2.16 × 3.24 mm pads at 7.38 mm pitch. Terminal width up to 3.18 mm and overall span up to 8.13 mm fit those pads; solder-process tolerances still require review. Custom numbering remains pin 1 anode, pin 2 cathode. Old supplier identifiers were cleared.

This increases normal reverse-voltage headroom; it does not establish surge immunity. Confirm TVS coordination and bridge temperature for the selected PoE load before release. Next small chunk: bench-input overvoltage disconnect.

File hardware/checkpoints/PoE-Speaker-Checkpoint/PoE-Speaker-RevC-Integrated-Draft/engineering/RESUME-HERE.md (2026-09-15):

# Resume checkpoint

Latest deliverable: KiCad-RevC/PoE-Speaker-RevC.kicad_pro and PoE-Speaker-RevC-Integrated-Draft.zip. Bench protection is now integrated and routed; partial secondary plane added; references cleaned; 14 power segments widened. Read KiCad-RevC/README.md for exact blockers. Revision B preserved.

Next work: complete fault-current limiting and startup/gate-drive validation; resolve U15 pad spacing, narrow tracks, module drill constraints, remaining silk and source electrical review. Do not mistake zero unconnected items for fabrication approval. Preserve routed C before running generators.

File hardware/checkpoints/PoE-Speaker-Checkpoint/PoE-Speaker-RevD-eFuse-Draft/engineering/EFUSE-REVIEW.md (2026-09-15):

# Revision D shared supply protection

Development circuit: TPS26630RGER sits between the joined ideal-diode outputs (24V_OR) and every original 24V_AMP load. Bench reverse/overvoltage protection remains upstream. B_GATE and DRV are unused: reverse blocking is assigned to the existing upstream circuits, not to this eFuse alone.

Calculated settings: 18/6.04 = 2.98 A nominal current limit; 1.2*(1+158/10) = 20.16 V UVLO; 1.2*(1+200/10) = 25.2 V OV cutoff; 1.2*(1+174/10) = 22.08 V power-good threshold. These are nominal values, not guaranteed switching points. MODE floats for latch-off. TP26 permits shutdown/reset by grounding SHDN; its internal pullup avoids depending on downstream 3V3 to start.

The PGOOD open-drain output clamps AMP_SDZ. U11 drives it through R135 (1 kohm), with R129 (10 kohm) to ground. At a 3.3 V command, released level is about 3.0 V; a 130 ohm clamp gives about 0.38 V and less than 3.3 mA. This is a static screening calculation; validate actual IO-expander levels, startup and brownout behavior on the assembled circuit.

C121 = 100 nF gives about 500 V/s and 48 ms to 24 V. Estimated downstream capacitance is 2215.22 uF including new C123: about 1.11 A nominal capacitor charging, or 1.71 A using 20% added bulk capacitance, 90 nF ramp capacitance, 2.225 uA and gain 26. DC-bias/tolerance-qualified capacitor selections and other startup loads remain open. Thermal regulation can change the startup waveform. Approximate nominal stored energy is 0.64 J at 24 V; this is not a thermal qualification.

Source: Texas Instruments TPS2663 Rev G, pin table, electrical characteristics, sections 8.3.2 and 8.3.7, Equation 5: https://www.ti.com/lit/ds/symlink/tps2663.pdf

Remaining work: qualify transient overshoot against the amplifier's 26 V operating ceiling, current-limit tolerances, fuse coordination, input wiring inductance, sustained overload heating, return copper, hot restart, and component order codes. A nominal 3 A limit is not an instantaneous 3 A hard-short ceiling. The first PCB must not be released on this calculation alone.

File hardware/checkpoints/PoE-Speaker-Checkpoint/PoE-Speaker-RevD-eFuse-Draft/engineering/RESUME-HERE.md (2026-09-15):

# Resume checkpoint

Latest: KiCad-RevD/PoE-Speaker-RevD.kicad_pro and PoE-Speaker-RevD-eFuse-Draft.zip. Shared eFuse/current-limit circuit and amplifier interlock are integrated. See KiCad-RevD/README.md and reports/revision-status.json for actual routing and rule-check status. B and C remain preserved.

Next: DRC is clean with the scoped thermal-via rule and Ethernet ground extension. Review the five ERC power-source findings, U7 FSW selection, high-current/thermal layout, startup/transients, and 127 missing order codes (reports/procurement-audit.json). Read engineering/EFUSE-REVIEW.md. Do not regenerate over saved routing.

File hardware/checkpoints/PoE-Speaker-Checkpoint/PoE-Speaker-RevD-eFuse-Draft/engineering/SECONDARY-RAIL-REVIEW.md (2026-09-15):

# Secondary rail review checkpoint

U7 is TPS62132RGTR, the fixed 3.3 V member of the TPS6213x family. The model connects FB and DEF to GND, VOS to 3V3, AVIN/PVIN and EN to 5V, all switch pins to L4, and AGND/PGND/EP to GND. These match the intended fixed-output topology. FSW is tied to 5V; the datasheet pin-table note recommends VOUT or PG for low-frequency selection, so this connection remains a follow-up item rather than being silently accepted. L4 is 2.2 uH and C53 is 3.3 nF; verify the full output-capacitance/stability envelope and startup loading before release.

Source: TI TPS6213x Rev F, Table 5 (device comparison), pin functions and application guidance: https://www.ti.com/lit/ds/symlink/tps62130.pdf

Five ERC findings remain: undriven power-input nets BENCH_FUSED, GND, 3V3, ETH_3V3A, and 24V_OR. The source symbols for several regulators and power-path devices use passive pin types. Do not simply place power flags to make this report green: verify those stages and correct symbol types/source annotations first. ERC cannot currently establish that every imported circuit has a valid power source.

Next physical review: buck input-capacitor loops, U7 VOS sensing route, inductor/output-capacitor loop, and the amplifier's power and heat-removal paths. The extended In1.Cu ground plane gives Ethernet additional reference copper, but signal-layer transitions and differential pair impedance/length still require review.

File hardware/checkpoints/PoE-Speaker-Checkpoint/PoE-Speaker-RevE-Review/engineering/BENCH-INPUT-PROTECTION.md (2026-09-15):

# Bench-input overvoltage proposal

Status: selection and static calculation only; not yet added to the schematic or routed board.

The amplifier permits 26 V in normal operation and has a 30 V absolute maximum. The latter is not a design target. [TI amplifier datasheet](https://www.ti.com/lit/ds/symlink/tpa3116d2.pdf).

Candidate: TPS26630 with adjustable overvoltage disconnect. Its OVP threshold is 1.176–1.224 V, input leakage is ±150 nA, and specified turnoff delay can reach 14 us under the datasheet test conditions. [TI eFuse datasheet](https://www.ti.com/lit/ds/symlink/tps2663.pdf).

Proposed divider: 200 kohm from protected input sensing node to OVP, 10 kohm from OVP to ground, both 0.1%. The calculation script enumerates threshold, resistor-tolerance and leakage corners:

- Nominal trip: 25.200 V.
- Static corner range: 24.619–25.783 V.
- Remaining static margin to 26 V: only 0.217 V.
- Working supply assumption: regulated 24 V ±2%. A +5% supply can nuisance-trip.

This is a candidate, not a validated protection solution. Temperature drift, aging and dynamic overshoot are excluded. Do not approve it solely on the static calculation.

Proposed insertion: J2 -> F1 -> input transient clamp -> reverse-polarity stage -> eFuse disconnect -> existing Q2/U10 ORing -> 24V_AMP. Rename the present fused node to BENCH_FUSED; reserve 24V_BENCH_PROTECTED for the disconnect output. D11 belongs upstream of the disconnect; it must not be represented as a 26 V rail clamp. The existing downstream ORing remains necessary until backfeed behavior is independently checked.

Next bounded step: select the reverse-polarity parts, current limit, startup ramp and temperature-stable divider; check the small voltage margin and dynamic response, then create the schematic change. Include the actual downstream bulk capacitance and PoE-powered backfeed condition. No changes to the routed PCB were made in this chunk.

## Temperature review checkpoint

The initial-tolerance calculation above is superseded for selection purposes by the temperature sweep in `bench-ovp-calculation.json`. Assuming independent worst-case TCR signs and resistor temperatures from -40 to 125 C (100 C maximum departure from 25 C):

| Each resistor TCR | Minimum trip | Maximum trip | Static window |
|---|---:|---:|---|
| 10 ppm/C | 24.572 V | 25.832 V | Pass, limited margin |
| 25 ppm/C | 24.502 V | 25.906 V | Pass, limited margin |
| 50 ppm/C | 24.386 V | 26.030 V | Fail |
| 100 ppm/C | 24.155 V | 26.279 V | Fail |

Decision: do not implement this candidate yet. At 25 ppm/C the lower trip is only 22 mV above the assumed supply maximum and the upper trip is only 94 mV below 26 V. Resistor aging and other effects are not included.

The JSON also contains an illustrative ramp calculation. At 10 V/ms, 14 us permits 0.14 V of additional rise if the rail follows the input. That alone exceeds the 94 mV margin. This is a sensitivity example, not a simulated waveform or a guaranteed protection bound; the datasheet delay applies at specified comparator overdrive.

Resume by comparing a more accurate/faster disconnect or a regulated/clamped amplifier supply architecture. Establish acceptable continuous supply range and transient envelope before choosing resistor values. Keep the existing routed draft as a review artifact until the replacement protection circuit is fully specified.

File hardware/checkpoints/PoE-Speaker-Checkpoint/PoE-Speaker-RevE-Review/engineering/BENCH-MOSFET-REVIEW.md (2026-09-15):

# Bench pass-MOSFET screening

Decision: retain PSMN4R8-100BSE as the conditional draft candidate for two new opposing pass FETs. Keep Q1/Q2 in their existing ORing roles. No PCB substitution has been made.

The datasheet identifies a 100 V D2PAK device intended for hot-swap operation. Its tab is drain, pin 1 gate and pin 3 source. Figure 4 was visually inspected; a deliberately conservative 60 V / 1 A point lies below its 25 C mounting-base DC curve. [Nexperia datasheet](https://assets.nexperia.com/documents/data-sheet/PSMN4R8-100BSE.pdf).

Using voltage scaling, (175-100)/(175-25) = 0.5, moves that screening point to 30 V / 1 A at a 100 C mounting base. This is an approximation, particularly in thermally unstable regions, not a characterized hot-SOA guarantee. [Nexperia AN50006](https://assets.nexperia.com/documents/application-note/AN50006.pdf).

The calculated capacitor-only envelope, 24.48 V and 0.886 A for up to 224.4 ms, fits inside that conservative rectangle. Taking a DC point avoids using the 100 ms curve for a longer startup. Treat a single FET as bearing the entire stress; do not assume equal power sharing.

This passes a preliminary selection screen, not the completed circuit. The actual mounting-base temperature must remain below the assumed 100 C. Additional startup loads, gate-drive voltage, gate charge, current-limiting and repeated-fault heating still need checking. The published on-resistance test uses 10 V gate drive; the controller minimum enhancement is lower, so do not claim the headline resistance in this circuit.

Next bounded implementation: create an isolated protection schematic draft with the verified controller pin map, two candidate FETs, ramp network and explicit startup-disable requirement. Preserve the routed mainboard until pin mapping and fault-current handling have been reviewed. The original DMNH6012LK3 graph was also archived; it was not approved as the new linear pass device.

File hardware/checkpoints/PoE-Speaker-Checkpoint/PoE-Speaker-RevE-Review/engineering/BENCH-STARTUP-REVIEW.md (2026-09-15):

# Bench startup checkpoint

Calculated from the actual design model: 2214.22 uF directly on 24V_AMP. A screening +20% capacitance assumption gives 2657.064 uF.

A proposed 100 nF gate-ramp capacitor gives approximately 0.443 A capacitor-only inrush and 120 ms charging at 24 V nominal. Using 30 uA gate drive, -10% ramp capacitance and +20% load capacitance gives 0.886 A and 73.44 ms at 24.48 V. The opposite gate-drive/capacitance corner extends charging to about 224.4 ms. The current-source bounds are specified under the manufacturer's 12 V test conditions; these are screening estimates, not guaranteed startup limits.

Capacitor charging alone dissipates about 0.796 J in the series pass path at the screening maximum, with initial dissipation near 21.7 W in the fast-ramp case. Do not approve a low-RDS(on) switching MOSFET by current rating or avalanche energy alone. Check linear SOA at hot initial temperature over the full ramp trajectory and repetition rate, assigning the full stress to one FET unless sharing is established.

Use the manufacturer's Figure 14 ramp network so its added capacitance does not defeat fast turnoff. [LTC4365 datasheet](https://www.analog.com/media/en/technical-documentation/data-sheets/ltc4365.pdf). The network values and physical layout require validation with the selected MOSFETs.

No MOSFET is approved in this checkpoint. Remaining loads during startup, amplifier disable sequencing, output-short protection and PoE backfeed must be included. The proposed ramp controls capacitor charging; it is not a current limiter during a fault.

Next: select a linear-SOA-qualified FET pair and check these trajectories, or choose an integrated hot-swap/current-limit architecture if the discrete path becomes larger. No schematic or PCB changes were made.

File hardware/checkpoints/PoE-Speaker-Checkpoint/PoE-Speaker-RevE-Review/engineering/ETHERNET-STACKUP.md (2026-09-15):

# Ethernet physical design baseline

2026-09-14: The PCB now contains an explicit JLC04161H-7628 stackup as the design baseline. This is a reversible engineering selection, not a fabrication order or an impedance qualification. The accepted change affects stackup metadata only; tracks, zones, pads and placements are unchanged. Backup: before-explicit-stackup.kicad_pcb.

| Layer | Thickness mm | Dielectric constant |
|---|---:|---:|
| F.Cu | 0.035 | — |
| 7628 prepreg | 0.21040 | 4.4 |
| In1.Cu | 0.0152 | — |
| FR4 core | 1.065 | 4.6 |
| In2.Cu | 0.0152 | — |
| 7628 prepreg | 0.21040 | 4.4 |
| B.Cu | 0.035 | — |

Source: [JLCPCB published stackup](https://jlcpcb.com/impedance), checked 2026-09-14. The listed copper/dielectric dimensions sum to 1.5862 mm; retain the nominal 1.6 mm board specification rather than silently rescaling dielectric heights. Mask is nonuniform: 0.01524 mm above copper and 0.03048 mm above substrate/between traces, Er 3.8. KiCad's single mask thickness stores the above-copper value; it cannot represent that full cross section. The sum including two above-copper mask films is 1.61668 mm. Confirm finished thickness tolerance and copper interpretation with fabrication. No loss tangent or hole plating thickness is assumed.

F.Cu over In1 GND is the intended Ethernet transmission-line geometry. The existing B.Cu and In2 signal segments do not have an equivalent nearby GND plane and must not reuse a top-layer width calculation. No bottom GND plane has been added by this change.

Calculator result verified 2026-09-15: masked noncoplanar differential model, L1 over L2, 100 ohm target and 8 mil gap gives **8.89 mil width** on JLC04161H-7628. Exact conversions are 0.225806 mm width and 0.2032 mm edge gap. The source UI labels this standard stackup as finished thickness 1.59 mm +/-10%. The displayed impedance tolerance of 0.5% is a solver setting, not a manufacturing guarantee. Inputs/results are saved in reports/ethernet-impedance-calculator.json. Source: [fabricator calculator](https://jlcpcb.com/pcb-impedance-calculator).

The main KiCad project now assigns ETH_TX_P/N and ETH_RX_P/N to Ethernet100 with those differential routing defaults. Clearance and via defaults are retained. This changes no existing copper and does not add an enforcing width or pair-gap DRC rule; existing 0.2 mm tracks remain unqualified. Do not apply this noncoplanar result beside close same-layer ground copper without recalculating the coplanar geometry.

Next implementation: rework PHY/jack/ESD/termination placement and actual routes using the saved pair preset, preserving pin polarity. Inspect pair coupling, return corridors and jack isolation keepouts. Add enforcing rules only with the actual routing and explicit pad escape exceptions.

The new ethernet-reference-review.json samples projected ground under track centerlines. Missing samples near pads can be normal antipads; continuous samples do not prove sufficient return width or a usable reference for inner/bottom routes. It is an inspection aid only. WIZnet's [hardware guide](https://docs.wiznet.io/Design-Guide/hardware_design_guide) remains the layout reference.

## 2026-09-15: front-layer RX feasibility probe

Promoted the five existing In2 RX segments to F.Cu at the sourced width in a separate trial. DRC found eight errors, zero unconnected items. Rejected; main copper remains unchanged. Detailed UUIDs/positions are in reports/rx-front-layer-probe.json. The trial is not a coupled pair and is excluded from release archives.

Obstacles are concentrated in the Ethernet circuit: TX_N routing at the jack and toward U3, TX_P routing to R101, R101 pad 1, and ETH_3V3A feeding the transmit termination. A layer-only conversion cannot solve these crossings. Do not repeat this same probe as the next chunk.

Next: coordinate all four MDI routes and R101/R102 supply branches, rather than routing RX in isolation. Preserve jack/PHY pin polarity. Plan the jack fanout first, then main coupled corridors, followed by short ESD/termination taps. R101/R102 placement and analog-supply access must be included in the same trial. RX bottom termination and ESD paths also remain part of final qualification. Keep the main unchanged until the full proposal has clean DRC and pin mapping.

## 2026-09-15: accepted local R101 transmit termination

R101 moved to B.Cu (120.5,64.8), angle 90. Its TX_P branch now uses the existing signal via at (119.497,66.7995) and about 1.59 mm of bottom track instead of about 5.37 mm of front track. ETH_3V3A uses a new 0.6/0.3 mm via at (119.7,63.975), linked to the existing In2 supply track. Via-to-pad bounding-box guard passes at 0.25 mm. DRC zero, unconnected zero; bottom placement visually inspected. Main backup before-r101-local.kicad_pcb; design model synchronized. No footprint library change is needed for a placement-only edit.

Rejected supply via trials at (120.5,62.9) and (121.6,63.975) conflicted with existing ground/RX copper. An additional RX_N top-layer probe still crossed TX_N fanout and ETH_3V3A in three places; that change was removed. See rxn-after-r101-trial-findings.json. This accepted change clears the TX_P termination branch, but does not complete the coordinated MDI reroute. Next address TX_N/R102 and R103 supply corridor together with both pair fanouts.

## 2026-09-15: accepted local R102 termination

Moved R102 to B.Cu (116.3,64.7), angle 270. Its TX_N tap uses a new 0.6/0.3 mm via at (117.1,64.1563) on the existing front signal track and about 0.917 mm of bottom track, replacing about 6.92 mm of front branch. The supply pad connects to the existing analog-supply via (117.5,65.3196). Via-to-component-pad bounding-box guard passes at 0.25 mm. Main PHY-to-jack routes are unchanged. This removes a long termination branch but adds a signal-tap via and does not qualify impedance or pair coupling. DRC and unconnected counts zero; underside placement visually inspected. Model synchronized; backup before-r102-local.kicad_pcb.

Rejected earlier position/orientation introduced nine DRC errors. Testing removal of the four-track R103 supply path produced one disconnected analog-supply island: it is NOT redundant. Restored all four tracks. Next rerouting must provide a replacement supply connection before removing that path. TX_N jack fanout remains another crossing obstacle. No footprint library geometry changed.

## 2026-09-15: accepted Ethernet front routing corridor

Replaced the TX_N jack detour with a shorter F.Cu route at 0.225806 mm width, preserving the R102 tap. Replaced segment length 10.107 mm becomes 8.551 mm. The first proposal crossed J1 unused pad 19; revised geometry goes below that pad and passes DRC. This is not yet a matched transmit pair.

Replaced the required four-track R103 analog-supply path through the receive corridor with 0.3 mm B.Cu routing from R102 power pad (116.3,65.525) via (116.3,74.6) to a new 0.6/0.3 mm supply via at (118.725,74.6), connecting the existing front analog-supply trunk. This longer replacement restores the complete analog supply rather than deleting a required connection. Current/return-loop review remains open. Via-to-component-pad guard passes at 0.25 mm.

With both obstacles cleared, moved all five In2 receive main-route segments to F.Cu at 0.225806 mm width. Both receive nets now use F/B only; bottom ESD/termination branches and their vias remain. Top-layer visual inspection and DRC pass with zero unconnected items. No component or footprint geometry changed, so no model/library placement update is needed. Backup: before-ethernet-front-corridor.kicad_pcb.

Next: improve actual RX coupling and spacing (long parallel sections still have about 0.768 mm center spacing, not the 0.429006 mm target), address RX_P PHY escape detour and termination taps, then TX_P layer/coupling and ESD branch geometry. The former layer-only probe conflicts are resolved by this coordinated change; do not rerun the old probe/acceptance scripts on the new main. Clean DRC does not establish impedance or return continuity.

## 2026-09-15: accepted coupled RX trunk

Rebuilt RX_P jack-to-PHY approach on F.Cu, bypassing its former dip through (117.5,71.6622). The former route to that via remains only as the ESD/termination tap. RX_P and RX_N now run parallel at 0.225806 mm width / 0.2032 mm edge gap for x=110.221 through 118.6 (8.379 mm). Pad escapes, via/tap discontinuities, branch lengths and reference continuity remain unqualified. DRC and connectivity are clean. No component/model placement changed. Backup before-rx-coupled-trunk.kicad_pcb. Next inspect RX branch geometry and return reference, then complete TX_P layer and pair coupling.

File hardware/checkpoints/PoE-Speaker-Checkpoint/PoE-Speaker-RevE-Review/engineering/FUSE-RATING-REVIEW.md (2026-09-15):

# F1 rating evidence and remaining coordination work

Reviewed 2026-09-14. F1 is the imported XC 24T 3.15A250V part. Manufacturer page: https://www.xcfuse.com/smd_fuses/24T_119.html

The manufacturer lists DC breaking capacities for the 250 mA–10 A range: UL 50 A at 125 VDC and 25 A at 250 VDC. It also lists VDE 100 A at 250 VDC through 6.3 A. Thus the earlier statement that F1 has no substantiated DC rating is superseded. Do not extrapolate a higher interrupt rating at 24 V without supporting evidence.

For 3.15 A the page gives nominal melting I²t of 25.78 A²s. Published operating bands allow at least one hour at 125%, 1–120 seconds at 200%, and 10–100 ms at 1000%. The page's approval-symbol legend is inconsistent; do not infer certification status from its circle symbols.

Decision: retain F1 as a candidate. Its voltage/interrupt evidence does not by itself establish coordination with the bench input, MOSFETs, wiring or eFuse. Determine prospective short current and temperature derating, check startup and time-current behavior, and compare fault let-through with the protected hardware. A current-limited bench source may never blow a 3.15 A fuse; staged bring-up must rely on its source limit and active protection rather than expecting fast fuse operation.

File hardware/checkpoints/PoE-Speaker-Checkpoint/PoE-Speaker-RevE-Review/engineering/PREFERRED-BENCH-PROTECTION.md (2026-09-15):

# Preferred bench protection candidate

Status: calculated candidate, not implemented in the schematic or PCB.

Use LTC4365 as the next design candidate with two opposing N-channel MOSFETs for disconnect and reverse-input protection. The device's full-temperature OV threshold is 0.4925–0.5075 V and input leakage is bounded at ±10 nA. Its specified fault delay is at most 2 us at 50 mV comparator overdrive and 12 V; this is not a universal 24 V switching-time guarantee. [Manufacturer datasheet](https://www.analog.com/media/en/technical-documentation/data-sheets/ltc4365.pdf).

Proposed OV divider: 198 kohm top, 4.02 kohm bottom, 0.1% initial tolerance, 10 ppm/C or better. Exact orderable resistor and controller grades remain to be chosen. Under the conservative independent-TCR assumptions in compare_ovp_candidate.py, the trip window is 24.651–25.606 V over -40 to 125 C resistor temperatures. This leaves 171 mV above the assumed 24 V +2% supply and 394 mV below the amplifier's 26 V operating ceiling. Aging and voltage coefficient remain unmodeled.

This is a better static candidate than the earlier TPS26630 divider; it is not proof of surge protection. Preserve Q2/U10 downstream ORing until reverse-current behavior is checked. LTC4365 does not replace current limiting. Select the external FETs against startup SOA, actual bulk capacitance, available fault current, and turnoff energy. Do not treat the 3.15 A fuse as a semiconductor current limiter.

Next implementation chunk: verify the complete reference topology and package pin map, select FETs and current/inrush handling, then build a separate schematic revision. Keep the existing routed PCB intact. The remaining 235 DRC findings and other documented electrical review items are unchanged.

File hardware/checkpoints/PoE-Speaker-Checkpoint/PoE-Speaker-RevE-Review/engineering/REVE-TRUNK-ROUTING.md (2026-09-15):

# Revision E supply-trunk routing follow-up

The two longest 24V_AMP segments, originally 49.385mm and 39.837mm long at 0.2mm width, now use 1.0mm routes. The first moves to y=81.5mm to clear the EFUSE_ILIM via. The second uses local bends around the 3V3 and BUCK5_VCC vias. The minimum-clearance rule remains 0.20mm.

The amplifier's front supply connection below U5 now bends to y=117.1mm at 1.0mm width. The incoming internal diagonal is widened to 1.0mm with a 0.8mm-long, 0.3mm-wide escape at its existing endpoint. The rear upper diagonal is 1.0mm with a 1mm-long 0.3mm escape. Part of the rear capacitor supply route is now 1.0mm and part 0.6mm; the congested section around AMP_FAULTZ and AMP_PLIMIT vias remains 0.2mm and needs further review/rerouting. Do not describe these changes as complete ampacity qualification.

The 10.959mm front trace from C123 toward R136 is a power-good sensing branch and was not widened in this pass. Final via count/current sharing, copper thickness, allowable temperature rise, switching-loop geometry and loaded-path analysis remain open.

Each accepted change passed the project's unchanged DRC profile with zero violations and zero unconnected items. Model/schematic/PCB pin-net mapping also passed for all 616 connected pins. No schematic connectivity was changed. Trial files are excluded from the review ZIP; the saved project is PoE-Speaker-RevE.kicad_pro.

Scripts reroute_amp_trunk.py, reroute_buck_supply.py, reroute_amp_branches.py and reroute_amp_back_supply.py are one-time operations against the preceding board state, not a generator to rerun against the final board. Before-trunk backup is retained under KiCad-RevE/reports.

## Direct amplifier feed

A subsequent pass added a continuous 1.0mm supply path from C5 pad 1 at (203.5,100) to the existing widened amplifier feed at (207,117.1). The route uses F.Cu into (207,107), B.Cu to (207,116.5), then F.Cu into the existing feed. Its two through vias have 1.0mm copper diameter and 0.5mm drills. This bypasses the congested 0.2mm branch around AMP_FAULTZ and AMP_PLIMIT; that original branch is retained in parallel, not reported as removed or widened.

The AMP_SDZ via moved from (207.524,111.6874) to (208.05,111.6874), with its In2.Cu and B.Cu connections adjusted. No signal net assignment changed. The relocated via and new route pass the unchanged clearance rules. DRC has zero violations and zero unconnected items, and all 616 model-to-board connections pass. Current sharing, via plating/temperature rise and local decoupling loops still require review; a geometric bypass alone does not qualify amplifier output power.

The accepted implementation is add_amp_bulk_feed.py, a one-time operation against the before-amp-direct-feed backup. bypass_amp_supply_neck.py and move_amp_control_vias.py are unsuccessful exploratory trials and must not be applied to the saved project. Trial boards are excluded from the review ZIP.

## Bench supply lanes

The long In2.Cu BENCH_FUSED and 24V_BENCH_PROTECTED routes are separated into wider lanes through the less congested right-hand board area. Their long new sections are 1.0mm wide at y=105.6 and y=103.3 respectively; the original narrow routing is retained through the dense amplifier area to the left. This is a partial routing improvement, not an end-to-end current rating.

The 26.243mm protected positive supply run on B.Cu was also widened: most is now 1.0mm, with a short 0.7mm section at x=195.45 passing between a ground via and the 3V3 route. This is the positive protected supply, not a ground-return trace despite the historical script filename widen_bench_return_run.py. No ground-plane or clearance-rule relaxation was made.

Accepted one-time scripts: separate_bench_trunks.py followed by widen_bench_return_run.py. Before-bench-trunks backup is retained in reports. The final board passes DRC with zero violations and unconnected items; all 616 model connections still match. Remaining narrow necks, supply vias, copper thickness and loaded-branch current analysis still require review.

## ORing supply follow-up

Two B.Cu 24V_OR routes were rerouted around the BUCK3V3_SS and AMP_PLIMIT vias. The upper route is predominantly 1.0mm wide, with short 0.3mm endpoint sections retained for signal clearance; the lower route is 1.0mm wide. The geometric audit's total below-0.5mm length for 24V_OR fell from 50.85mm to 30.87mm. No clearance rules were changed. The accepted one-time script is widen_oring_routes.py; the preceding board is preserved as reports/before-oring-routes.kicad_pcb.

Next review should distinguish supply load branches from sensing branches using actual PCB connectivity, rather than continuing to widen all same-net segments indiscriminately. KiCad's connectivity object exposes GetConnectedTracks/GetConnectedPads/GetConnectedItems, which may help build a path-level audit. No such path/current analysis has yet been completed. Via plating, temperature rise and bottlenecks in the remaining power paths are still open.

## Source-to-load audit and 5V correction

The subsequent audit_supply_paths.py now uses KiCad's direct track/pad connectivity to trace ten actual source-to-load paths. Results are in reports/supply-path-audit.json. It maximizes the minimum track width and then minimizes a whole-segment length metric. Pads and vias are not given current ratings, and it does not model parallel current sharing, voltage drop or ground return. This supersedes the earlier note that no path-level audit exists; current/thermal analysis still remains undone.

The verified L3.2-to-U7.11 load path initially contained 35.739mm of tracks narrower than 0.5mm. Its long In2.Cu sections were rerouted around 5V_PG and BUCK3V3_SW vias and widened to 0.8mm. The final approach segments (UUIDs 044de3e7-c3b7-45a4-9740-430398edd39b, a71c8389-bc65-4b39-af65-2e91e130130f and 8406323a-3925-4c5c-ad4a-98a370fb3ed6) were widened to 0.6mm. The 613a3492-9a19-4af0-a3a0-fbece343fb45 pin connection is 0.3mm wide and 0.702mm long. The audited path now has a minimum track width of 0.3mm and only 0.702mm below 0.5mm. DRC and all 616 pin-net checks pass.

The long-route operation is widen_5v_load_path.py; final approach changes are recorded above and in the board. The preceding board is reports/before-5v-load-path.kicad_pcb. Next priority candidates from the audit: F1.2-to-Q3.2, Q4.2-to-Q2.3, eFuse input/output approaches, and L4.2-to-U2.2 (the latter still has a 17.729mm 0.2mm segment near the top edge). Distinguish unavoidable short IC pin escapes from long load-carrying bottlenecks.

## 3V3 header feed

The later reroute_3v3_header_feed.py replaces the six narrow sections on the L4.2-to-U2.2 path near J4 with a continuous 0.8mm route at y=51.7 and around the left end of the header at x=154.5. The neighboring BOOT_GPIO0 trace was moved to y=50.63 with bends retaining its original endpoints. It remains inside the unchanged copper-to-edge clearance rule. No net assignments, connector pinouts or source electrical behavior changed.

The candidate passed DRC with zero findings and zero unconnected items; pin-net validation also passes. The prior board is reports/before-3v3-header-feed.kicad_pcb. Consult the refreshed source-to-load audit for the resulting whole-path bottleneck; width improvements are still not a thermal/current rating.

## eFuse approaches

The eFuse input approach (8160d7ac-d120-490a-b50f-c89914d5ad20) is widened from 0.2mm to 0.6mm. The output route now uses short 0.3mm connections from both OUT pins into a 0.8mm route toward C123 and the existing supply via. The short pin-17 branch joins at x=254.3 to avoid the AMP_SDZ via. This preserves pin spacing clearance while widening the shared current path; package and copper current sharing are not yet thermally qualified.

The accepted output change is widen_efuse_output.py. The pre-change board is reports/before-efuse-approaches.kicad_pcb. Run checkpoint_reve.py after any accepted board edit to regenerate DRC, pin-net checks, power audits, preview, and the verified review/checkpoint archives. It refuses to package a board with DRC findings.

## Latest amplifier and bench improvements

reroute_amp_near_3v3.py replaces the narrow In2.Cu detour near the 3V3 via with a 0.8mm route through x=197.6. The U5 supply approaches a7552990-f27c-4d45-807f-a1e4426dea3a, 265774f1-129e-4ed8-a0aa-32a2c26f2972 and a858f2b0-a324-4e91-86d8-2db20ad48114 are now 0.8mm. The upper power pin bridge 8a2dc632-7769-4734-9b2d-34b75ff1148e and pin-31 approach be6888ca-9eb7-443c-b8d0-eaadce5606e2 are 0.5mm. The short B.Cu neck 44438f23-f561-457f-b997-fb3abbad93c0 is 0.4mm. These changes passed DRC without rule changes.

The F1 output approach c10ca537-3517-4ffc-a2eb-3b6b120c567d and 13.8975mm BENCH_FUSED diagonal 09e5af79-6607-4f10-9e78-aa9b6704e562 are widened to 1.0mm. A subsequent one-time screen_bench_widths.py tested fourteen remaining narrow loaded segments at 0.6mm. Three passed and were accepted: 80049751-3370-469e-a09d-af30adfec276, acc9d389-638c-40f3-aa0f-94b5fbe48b2d and f28f03ed-3f95-4cd8-8dbc-7535d3cf855b. The other eleven trials were rejected for clearance findings. Their original widths remain. Detailed results are reports/bench-width-screen.json; the pre-screen board is preserved locally.

The current F1.2-to-Q3.2 path still has 26.968mm below 0.5mm, and Q4.2-to-Q2.3 has 30.438mm. Both remain limited to 0.2mm at some locations and require rerouting. The 3V3 L4-to-U2 path is now at least 0.6mm throughout. eFuse-to-amplifier paths have only 1.0–1.5mm below 0.5mm in the selected graph paths, but their vias and thermal performance are not qualified.

## Bootstrap placement: open priority

audit_bootstrap_paths.py records both capacitor-to-IC connections for C7–C10. The combined whole-segment screening lengths are C7 58.703mm, C8 52.641mm, C9 67.963mm and C10 29.889mm. These are not exact loop lengths: shared tracks can extend beyond a junction. They nevertheless identify a substantial placement issue. TI's TPA3116D2 layout guidance calls for close local decoupling and small switching loops: https://www.ti.com/lit/ds/symlink/tpa3116d2.pdf . A clean connectivity report does not qualify these loops.

Neither place_c9_bootstrap.py nor place_c9_bootstrap_bottom.py is accepted. The top trial conflicts with SW_NEG and ground tracks. The revised bottom trial places C9 at (212.7,109.7) and reuses the SW_POS via, but its new BSNR via conflicts with the 1.0mm B.Cu SW_POS trunk at x=211.598 and the F.Cu ground link at x=212.81. It also leaves the old SW_POS capacitor spur dangling. Main C9 remains at its original location. Do not copy power-trial.kicad_pcb into the main project. Plan a coordinated local reroute of bootstrap capacitors, switched-output copper and ground connections; preserve current capacity, drill/clearance limits and the return plane.

## Accepted C9 local placement — supersedes original-location note above

The later coordinated trial place_c9_bootstrap_local.py, followed by prune_c9_old_spur.py, is accepted. C9 is now on F.Cu at (214.5,109.7), oriented 90 degrees. Two 0.3mm connections run directly from U5 pins 26/27 to its pads, with bends starting at x=213.3. The combined audited connection length is 5.766mm, down from the previous 67.963mm whole-segment metric. The original long BSNR route and five DRC-identified dangling SW_POS spur items are removed. The two older trial scripts remain rejected.

The crossing F.Cu ground link between pins 25 and 28 is replaced with 0.6mm diameter / 0.3mm drilled ground vias at (212.81,110.675) and (212.785,108.725), connected to the filled ground plane. SW_NEG retains its 1.0mm width and detours via x=216 to clear C9; this adds approximately 2.829mm to the audited C7/C8 output paths, which still need local placement work. J3's reference is moved clear of C9. No clearance or drill constraints were relaxed.

The rendered top copper was visually inspected, DRC has zero findings and zero unconnected items, and all 616 model-to-schematic-to-PCB connections pass. The pre-change board is reports/before-c9-local-placement.kicad_pcb. The model's C9 placement is synchronized. This is a layout improvement, not measured switching performance. Next: coordinated C7, C8 and C10 placement, with HF decoupling and output-loop review.

## Accepted C10 and C7 local placement

C10 is now at (214.5,106.5), oriented 270 degrees on F.Cu. Its 0.3mm connections run to U5 pins 30 and 29 with separate bend positions to maintain clearance. The combined audited connection metric fell from 29.889mm to 6.328mm. One obsolete SW_POS spur was removed. Accepted one-time scripts: place_c10_bootstrap_local.py and prune_c10_old_spur.py. The preceding board is reports/before-c10-local-placement.kicad_pcb.

C7 is now at (214.5,115.0), oriented 90 degrees on F.Cu. Its 0.3mm connections run locally to U5 pins 20 and 21. Four obsolete SW_NEG spur items were removed, including the long top-side run formerly reaching C7. The combined audited connection metric fell from 61.532mm to 5.156mm. Accepted one-time scripts: place_c7_bootstrap_local.py and prune_c7_old_spur.py. The preceding board is reports/before-c7-local-placement.kicad_pcb.

The affected references were repositioned to clear copper apertures and one another. Each candidate was rendered and visually inspected before acceptance. Both accepted boards passed DRC with zero findings and zero unconnected items; all 616 pin-net comparisons pass. C7 and C10 model placements are synchronized, and review/checkpoint archives are refreshed. Scripts operate on their respective earlier baselines and should not be reapplied blindly.

C8 remains at its original location, with a 55.470mm combined whole-segment screening metric. It needs a coordinated placement pass; avoid crowding the already placed capacitor courtyards or the J3 connector. Local HF decoupling, output-current paths, and ground-return review remain necessary after bootstrap placement. No manufacturing release is implied by these geometry checks.

## Accepted C8 local placement — completes the bootstrap placement pass

C8 is now on F.Cu at (214.5,112.2), oriented 180 degrees, between C9 and C7. Its two local connections to U5 pins 24 and 23 reduce the combined audited metric from 55.470mm to 5.751mm. The old BSPL routing and eight DRC-identified obsolete SW_NEG spur items were removed. Accepted one-time scripts are place_c8_bootstrap_local.py and prune_c8_old_spur.py, against the preceding board preserved as reports/before-c8-local-placement.kicad_pcb. The C8 model placement is synchronized.

To clear C8, SW_NEG transitions from F.Cu at (216,110) to In2.Cu and back at (216,113.45), using 1.0mm diameter / 0.5mm drilled through vias. The inner segment remains 1.0mm wide. The short lower F.Cu approach is 0.6mm to clear the C7 bootstrap connection, and the short connection near pin 23 is 0.3mm; current sharing, temperature rise and switching performance still need qualification. The B.Cu SPK_POS route retains 1.0mm width and detours left through (214.7,109.31) and (214.7,111.55) to clear the upper output via without approaching the wrong connector pad. No clearance or drill rules were relaxed.

The top copper rendering was inspected before acceptance. Final DRC reports zero findings and zero unconnected items, and all 616 pin-net checks pass. The four combined bootstrap routing metrics are C7 5.156mm, C8 5.751mm, C9 5.766mm and C10 6.328mm. These are geometric screening values, not measured loop inductance or circuit qualification. Checkpoint archives and resume notes are updated. Next: amplifier high-frequency decoupling placement, output-current and ground-return paths, then the remaining release checks.

## Accepted supply decoupler placement: C13 and C12

C13 moved from (196,91) to (213.5,119), oriented 270 degrees on F.Cu. A 0.8mm connection joins the lower amplifier supply near pin 17. Its ground pad connects to a 0.8mm diameter / 0.4mm drilled ground via at (213.5,121.9). The old crossing ground trace was replaced by local returns at (209.225,119.1) for C11 and (216.3,118.4) for the downstream ground branch, using 0.6mm / 0.3mm vias. Two obsolete supply-spur items were removed. Accepted scripts: place_c13_decoupling.py and prune_c13_old_spur.py. Backup: reports/before-c13-decoupling.kicad_pcb.

C12 moved from (200,107.5) to (207.4,104), oriented 90 degrees on B.Cu. It connects through the existing supply via at (207,107), with a 0.8mm backside connection and a 0.6mm local front connection to the upper supply pins. Its ground return uses a 0.8mm / 0.4mm ground via at (207.4,101). The capacitor pads are clear of the open via holes; the trial's new via in the supply pad was rejected. The AMP_SDZ signal remains on B.Cu, detouring around C12 through x=209.25 without crossing the inner power lanes. One obsolete supply spur was removed. Accepted scripts: place_c12_decoupling.py and prune_c12_old_spur.py. Backup: reports/before-c12-decoupling.kicad_pcb.

Both placements were rendered and visually inspected and passed DRC with zero findings/unconnected items. All 616 pin-net comparisons pass. Model placement and side are synchronized. C12 introduces an underside component at this location; assembly planning and enclosure standoff clearance must account for it. C14/C15 and overall supply/ground loops still require review; no capacitance-under-bias, thermal or EMC qualification is implied. TI guidance used: https://www.ti.com/lit/ds/symlink/tpa3116d2.pdf , sections 8.2.2.4 and 10.1. The purpose is to shorten decoupling connections to supply and ground, not merely clear DRC.

## Output-pin width follow-up

The actual output-current paths are now recorded by audit_output_paths.py in reports/output-path-audit.json and regenerated by checkpoint_reve.py. Three short amplifier pin connections were widened from 0.3554mm to 0.5mm: 6a066147-0a58-4241-b33e-d64c5af9ea57 (pin 21), 114bc68d-c06b-49f8-92b9-769f02e570c5 (pin 23), and ff07bc79-1b99-440c-af24-ed57d7520758 (pin 29). Their lengths are 1.405mm, 1.405mm and 1.208mm. Backup: reports/before-output-pin-widths.kicad_pcb.

All four selected amplifier-to-inductor paths now have minimum track widths of at least 0.5mm; the pin-27 path has a 1.0mm minimum. Both inductor-to-speaker-connector paths have a 1.0mm minimum. No selected path includes a track below 0.5mm. This excludes pads/vias from the width metric and does not establish ampacity, current sharing, temperature rise or output-loop inductance. Other narrower tracks on these nets include bootstrap branches; they should not be widened indiscriminately.

DRC remains at zero findings/unconnected items, all 616 pin-net comparisons pass, and checkpoint archives are verified. Remaining priorities include amplifier local returns and internal GVDD decoupling, the still-narrow bench supply trunks, and stackup/current/thermal qualification.

## Extended bench supply lanes

extend_bench_fused_lane.py replaces the long 0.2mm section and its eastern bend with a 1.0mm In2.Cu lane at y=105.6 from x=199.073 to 215.5. A short 0.2mm entry remains from (199.073,104.835). Backup: reports/before-fused-lane-extension.kicad_pcb.

extend_bench_protected_lane.py replaces the neighboring long 0.2mm route with a 1.0mm In2.Cu lane at y=102.4 from x=197.2 to 215.5, joining the existing lane at y=103.3. The narrow entry bends through (197.2,104.04) to clear the nearby 3V3 via. Backup: reports/before-protected-lane-extension.kicad_pcb.

widen_protected_shutdown_neck.py replaces the 6.8231mm-long 0.2mm B.Cu segment near the bench controller with a 0.6mm route through x=251.2, maintaining clearance from BENCH_SHDN at (252.115,100.975). Backup: reports/before-protected-shutdown-neck.kicad_pcb.

The audited F1.2-to-Q3.2 path now has 10.224mm below 0.5mm, down from 26.968mm. Q4.2-to-Q2.3 now has 6.649mm below 0.5mm, down from 30.438mm. Both still contain 0.2mm sections and are not current-qualified. No clearance constraints were changed. Final DRC is zero findings/unconnected items, all 616 pin-net checks pass, and checkpoint archives are verified. Continue with the remaining short necks identified by supply-path-audit.json and then current/via/return-path qualification.

## Bench entry bottlenecks removed

widen_fused_entry.py replaces the remaining narrow fused entry and obsolete stub with a 0.6mm In2.Cu route through (189.932,107.2), (197.473,107.2) and (199.073,105.6), retaining the original western endpoint (189.756,107.024). The y=107.2 lane clears the protected-supply via that blocked the initial trial. Backup: reports/before-fused-entry.kicad_pcb.

Four protected-supply entry segments are widened to 0.6mm: 331895c1-e12e-4f85-8351-170377cc3197, 73ad2d41-2e02-485d-971e-8b832a88669b, 5ca90b07-e6b7-401f-b20a-8837c8e69503 and 060da957-5bed-452d-b66b-8ee326c8651e. Backup: reports/before-protected-entry-widths.kicad_pcb.

The saved F1.2-to-Q3.2 and Q4.2-to-Q2.3 graph paths now each have minimum track width 0.6mm and zero whole-segment length below 0.5mm. This supersedes the preceding narrow-entry counts. Other same-net sensing branches remain narrow intentionally; the audit does not establish current capacity, via plating requirements or thermal performance. DRC is zero findings/unconnected items and all 616 pin-net comparisons pass. Next: current and return-path qualification, outstanding local decoupling, Ethernet and release checks. Connector roles and exact J4/J5/J6 pin numbers are recorded in engineering/CONNECTOR-GUIDE.md.

## C11 investigation — trials NOT accepted

audit_amplifier_decoupling.py now records six supply-side bypass/PLIMIT paths in reports/amplifier-decoupling-audit.json and is included in checkpoint validation. It uses the existing widest-path, whole-segment screening metric, not an exact loop-length calculation. The saved U5.7-to-C11.1 path reports 18.339mm and two vias; U5.7-to-R15.1 reports 13.743mm and two vias. R15 feeds AMP_PLIMIT, not AMP_GAIN. An early commentary description of it as a gain-setting resistor was incorrect.

No C11 relocation has been accepted. The saved C11 remains at (210,120) on F.Cu. place_c11_gvdd.py and prune_c11_old_spur.py are experimental and must not be applied to the main project or used as a release candidate without completing checks. The current power-trial board has conflicts and is excluded from review archives.

The investigation found several constraints: the F.Cu AMP_SDZ vertical at x=202.3527 blocks a direct route into the space vacated by C12; the inner layer has crossing audio/control routes, and the back layer is crowded with FAULTZ, GAIN and PLIMIT. Removing all GVDD tracks also disconnects R15, so preserve its branch. The latest trial at (203.6,120.5) conflicts with the PLIMIT via at (203.822,119.832) and has label issues. Other nearby positions conflict with the 24V_AMP route at y=117.1 or x=202.3809. Do not repeat blind coordinate trials; first map the local copper and plan a coordinated placement/routing change that preserves R15 and avoids open holes in solder pads. Main-board geometry remains at the last verified bench-entry checkpoint.

## Accepted C11 local GVDD bypass — 2026-09-14

Mapped the actual bottom-layer corridor before placement. C11 moved from top (210,120), 180 degrees, to bottom (204.9,111.5), 270 degrees. Its GVDD pad connects locally to the existing GVDD via at (205.583,110.37); ground bends left around the MUTE via, then reaches a new 0.5 mm diameter / 0.3 mm drill ground via at (205.2,114.1). Retained the full R15 PLIMIT branch. Removed five DRC-identified obsolete C11 spur items. Trial DRC: zero findings and zero unconnected items. Bottom copper/silkscreen render inspected. Main pre-change backup: before-c11-local-gvdd.kicad_pcb. This supersedes earlier rejected C11 trials. Current/return-plane and assembly qualification remain pending; no fabrication release.

## Accepted remaining load-neck widening — 2026-09-14

Four audited load-path segments widened to 0.6 mm: 24V_OR 4ad3da69 and 5075d3e5; 24V_AMP 44438f23; 5V 613a3492 (full UUIDs and original widths in reports/load-neck-width-trial.json). Trial has zero DRC findings and zero unconnected items. The 0.5 mm-long U16 output escape de68fccd remains 0.3 mm: widening to 0.6 mm reduced clearance to AMP_SDZ pin 16 to 0.075 mm, so that change was reverted. No component or netlist changes. These widths do not establish via ampacity, temperature rise, or return-path quality. Backup: before-load-neck-widths.kicad_pcb.

## Accepted power-via enlargement — 2026-09-14

Reviewed 18 audited load-path vias with 0.3 mm drills. Eleven now use larger copper/drill geometry (1.0/0.5 mm or 0.8/0.4 mm); seven retain original geometry because of neighboring copper. Full per-via positions, UUIDs and before/after dimensions: reports/power-via-review.json. Proposed drills were screened against all component pad bounding boxes with 0.35 mm margin to avoid moving holes into solder pads. Final filled-board DRC zero, unconnected zero. Original board preserved in before-load-via-enlargement.kicad_pcb. This is a geometry improvement, not a current rating: plating thickness, thermal behavior and ground-return review remain pending.

## Accepted eFuse output via relocation — 2026-09-14

Via b983fee9 moved from (256.4755,78.2346) to (256.4755,78.1546), enlarged from 0.6/0.3 mm copper/drill to 0.8/0.4 mm. Preserved the original long In2 route to clear EFUSE_FAULT_N; added a 0.08 mm long, 0.6 mm wide connecting segment. F.Cu endpoint follows the shifted via. Checked new hole against all pad bounding boxes with 0.30 mm center margin. Larger displacements approached C123 and were rejected. Final DRC zero and unconnected zero. This brings the preceding power-via review to twelve improvements and six original constrained vias. Backup: before-efuse-via-relocation.kicad_pcb. No via ampacity claim; plating and thermal assumptions remain unresolved.

## Ground-access review checkpoint — 2026-09-14

Added audit_amplifier_ground.py to the checkpoint workflow. Inventory follows ground tracks to vias and explicitly identifies plated through-hole pads; it does not model zone current or return inductance. C11/C12/C13 have nearby track-connected ground vias. C14/C15 merit local ground-access review; nearest reachable vias have straight-line separations around 3.98/5.97 mm, which are screening distances, not routed loop lengths. C5/C6 through-hole pads can access the ground plane directly, so separate-via distance is not evidence of a defect. Only one saved GND zone is present, on In1.Cu. Next inspect C14/C15 and U5 ground-plane continuity before changing routing. No PCB change in this chunk.

## Accepted C14/C15 local ground vias — 2026-09-14

Added 0.8 mm copper / 0.4 mm drill GND vias at (197.425,115.5) and (197.425,111.5), each with a 1.1 mm long, 0.6 mm wide F.Cu link from its capacitor ground pad. Hole-to-pad guard checked. Initial x=197.325 conflicted with the bottom 3V3 trunk and was rejected; x=197.425 passes. Both via centers hit the saved filled In1.Cu GND zone. Final DRC zero, unconnected zero. Existing ground routes retained. See reports/c14-c15-ground-vias.json. Backup before-c14-c15-ground-vias.kicad_pcb. Ground return distribution and amplifier pin/plane access remain for review.

## Accepted amplifier ground-pin track widths — 2026-09-14

Widened 21 directly connected U5 GND segments from 0.2 mm: seventeen to 0.4 mm, three to 0.35 mm, one to 0.25 mm. This count includes tiny imported pin stubs; it does not represent 21 independent return paths. Four full-width candidates conflicted with MUTE/SW_POS/SDZ/GAIN vias and were reduced to preserve clearance. Zero final DRC and unconnected findings. No route or via relocation. Full UUIDs/dimensions in reports/amp-ground-pin-widths.json. Backup before-amp-ground-pin-widths.kicad_pcb. Remaining: ground pin-to-plane access and return continuity, including downstream 0.2 mm tracks.

## Accepted U5 pin 22 ground-plane access — 2026-09-14

Added a 0.6 mm copper / 0.3 mm drill GND via at (209.88,112.453) on the existing ground track. Via center contacts filled In1.Cu GND; pad-hole clearance screened with a 0.25 mm center margin. First trial at (210.822,112.625) conflicted with AMP_SW_POS on B.Cu and was rejected. Accepted position has zero DRC and unconnected findings. No old ground routes removed. Backup before-pin22-ground-via.kicad_pcb. Added audit_amp_ground_plane.py to locate shortest whole-segment copper paths from all ten ground pins to filled-plane-contact vias or plated pads; this does not qualify return impedance or uninterrupted current corridors.

## Accepted lower amplifier ground-group link — 2026-09-14

Added 0.35 mm F.Cu ground tracks from U5 pin 13 (204.19635,113.925) through (205.025,113.925) to the existing C11 GND via at (205.2,114.1). Confirmed that via contacts filled In1.Cu ground. Original ground routes retained. Trial via for pin 1 at (205.203,106.125) conflicted with AMP_MUTE on B.Cu and BENCH_FUSED on In2.Cu and was removed before acceptance. Final DRC zero and unconnected zero. Backup before-pin13-ground-link.kicad_pcb. Pin 1 remains unchanged; next inspect a different local ground access point for pin 1 and pins 9-11.

## Accepted extension mounting support — 2026-09-14

Moved existing right mounting holes H3/H4 from x=225 to x=275 at y=55/145. The mounting centers are now 5 mm from the extended right board edge, matching left-side edge offsets. Retained M2 footprints; use insulating standoffs. No other component pad bounding boxes within 2.5 mm of these centers. DRC zero and no unconnected items. Placement model synchronized; schematic connections unchanged. Backup before-extension-mounts.kicad_pcb. Enclosure, heatsink and module support remain separate mechanical checks.

## Accepted B5100C mechanical courtyards — 2026-09-14

Added 10.1 x 6.8 mm F.CrtYd rectangles to D3-D10 and their local library copies. Basis: saved B5100C package drawing, maximum body width 6.22 mm and overall lead span 8.13 mm; existing pads reach +/-4.77 mm in X. Courtyard allows at least 0.25 mm beyond pad/body extents, rounded outward. No copper or pad changes. Zero final DRC/overlap findings. Board and original library copies backed up. Other imported components without courtyards remain in reports/courtyard-coverage.json.

## Accepted Ethernet receive termination cluster — 2026-09-14

Moved R104/R105/C102 to B.Cu near U3, coordinates in reports/rx-termination-placement.json. New short B.Cu links use existing RX signal vias. Rebuilt the RX termination common node and added a 0.6/0.3 mm ground via at (121.5,74.875), confirmed in filled In1 GND and outside component pads. Removed twelve DRC-identified obsolete RX spur items, including one obsolete signal via. Final DRC zero, unconnected zero; bottom render visually inspected. Original main saved as before-rx-termination-cluster.kicad_pcb. This reduces excess termination routing; main pair coupling, impedance, layer transitions and skew remain open. Trial uses a copy of the main project/rules. Trial files must stay out of release archives.

Post-change Ethernet inventory: RX_P total copper 41.116 to 28.831 mm; RX_N 40.564 to 26.903 mm, including branches. Main PHY-to-jack screening paths unchanged. This is a termination-branch improvement, not completion of pair routing.

## 2026-09-15: sourced Ethernet routing preset

Verified JLCPCB calculator output for JLC04161H-7628, masked noncoplanar L1/L2, 100 ohm, 8 mil gap: 8.89 mil width. Added Ethernet100 class with exact converted width 0.225806 mm and gap 0.2032 mm, assigned to the four MDI nets. Trial DRC zero/unconnected zero. Existing copper unchanged; this prepares actual rerouting and is not impedance qualification. Preserved before-ethernet-pair-preset.kicad_pro. The calculator tolerance setting is not a production guarantee.
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

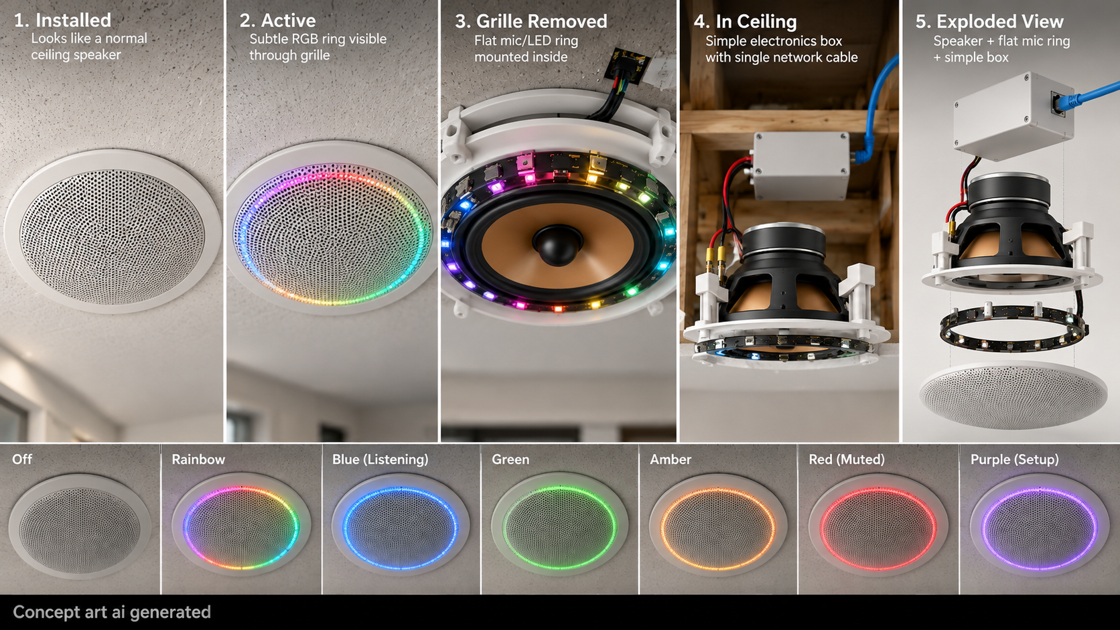
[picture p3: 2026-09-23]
docs/images/ESPCeilingSpeakerConcept.png

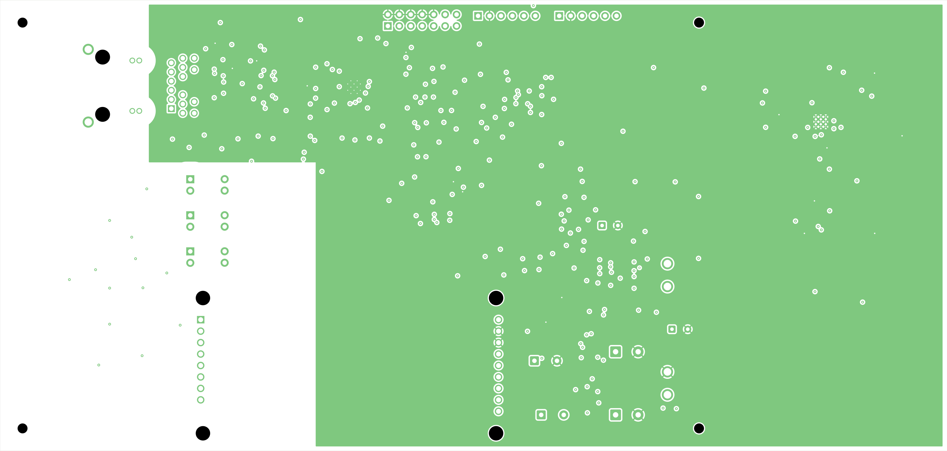
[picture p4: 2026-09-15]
hardware/checkpoints/PoE-Speaker-Checkpoint/PoE-Speaker-RevD-eFuse-Draft/KiCad-RevD/reports/secondary-ground.png

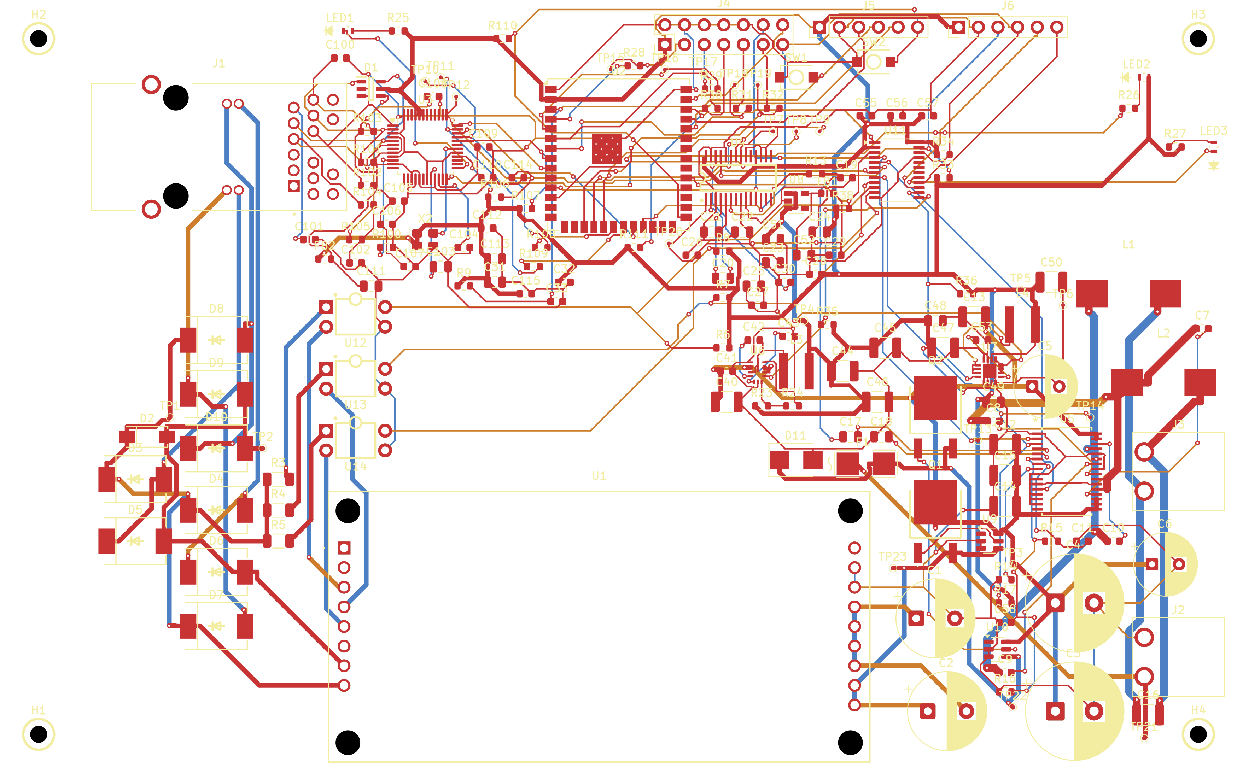
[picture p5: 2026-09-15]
hardware/checkpoints/PoE-Speaker-Checkpoint/PoE-Speaker-First-Board-Draft/PoE-Speaker-First-Board-Draft/reports/first-board-draft.png

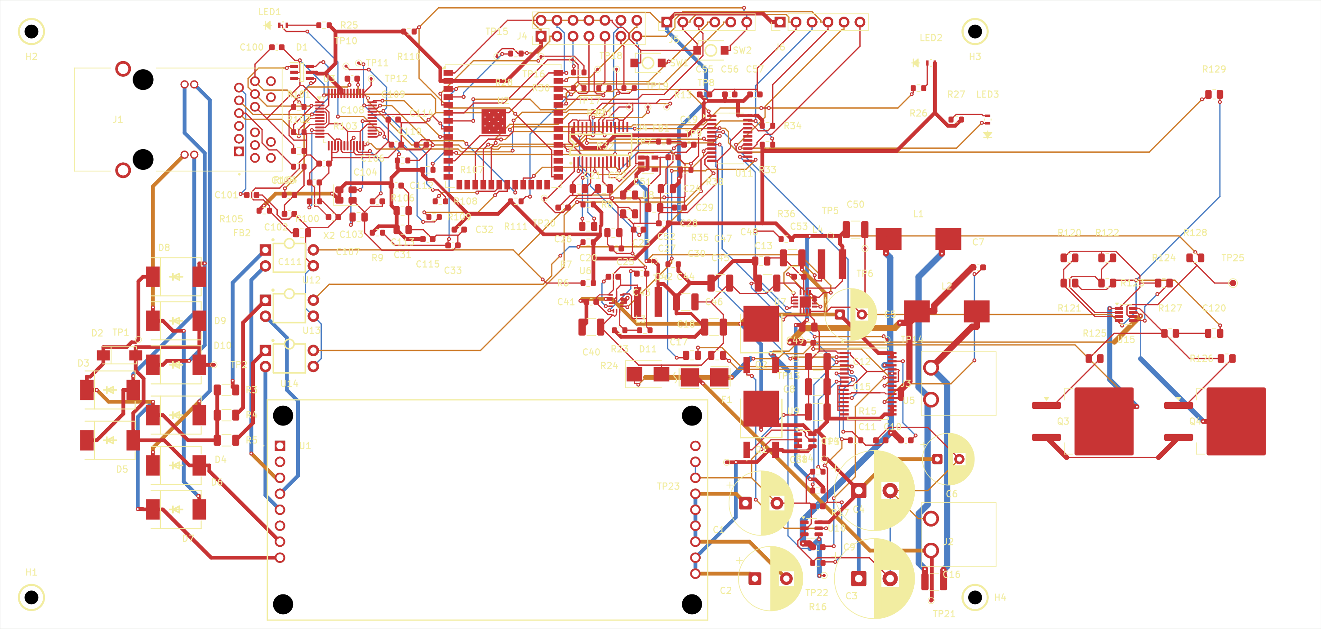
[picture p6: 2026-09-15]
hardware/checkpoints/PoE-Speaker-Checkpoint/PoE-Speaker-RevC-Integrated-Draft/KiCad-RevC/reports/revision-c-board.png

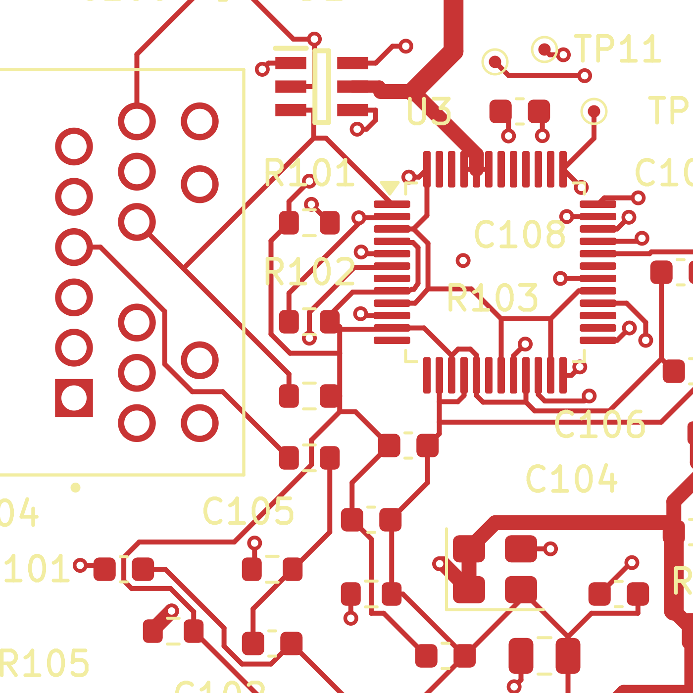
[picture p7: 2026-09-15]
hardware/checkpoints/PoE-Speaker-Checkpoint/PoE-Speaker-RevE-Review/KiCad-RevE/reports/ethernet-detail.png

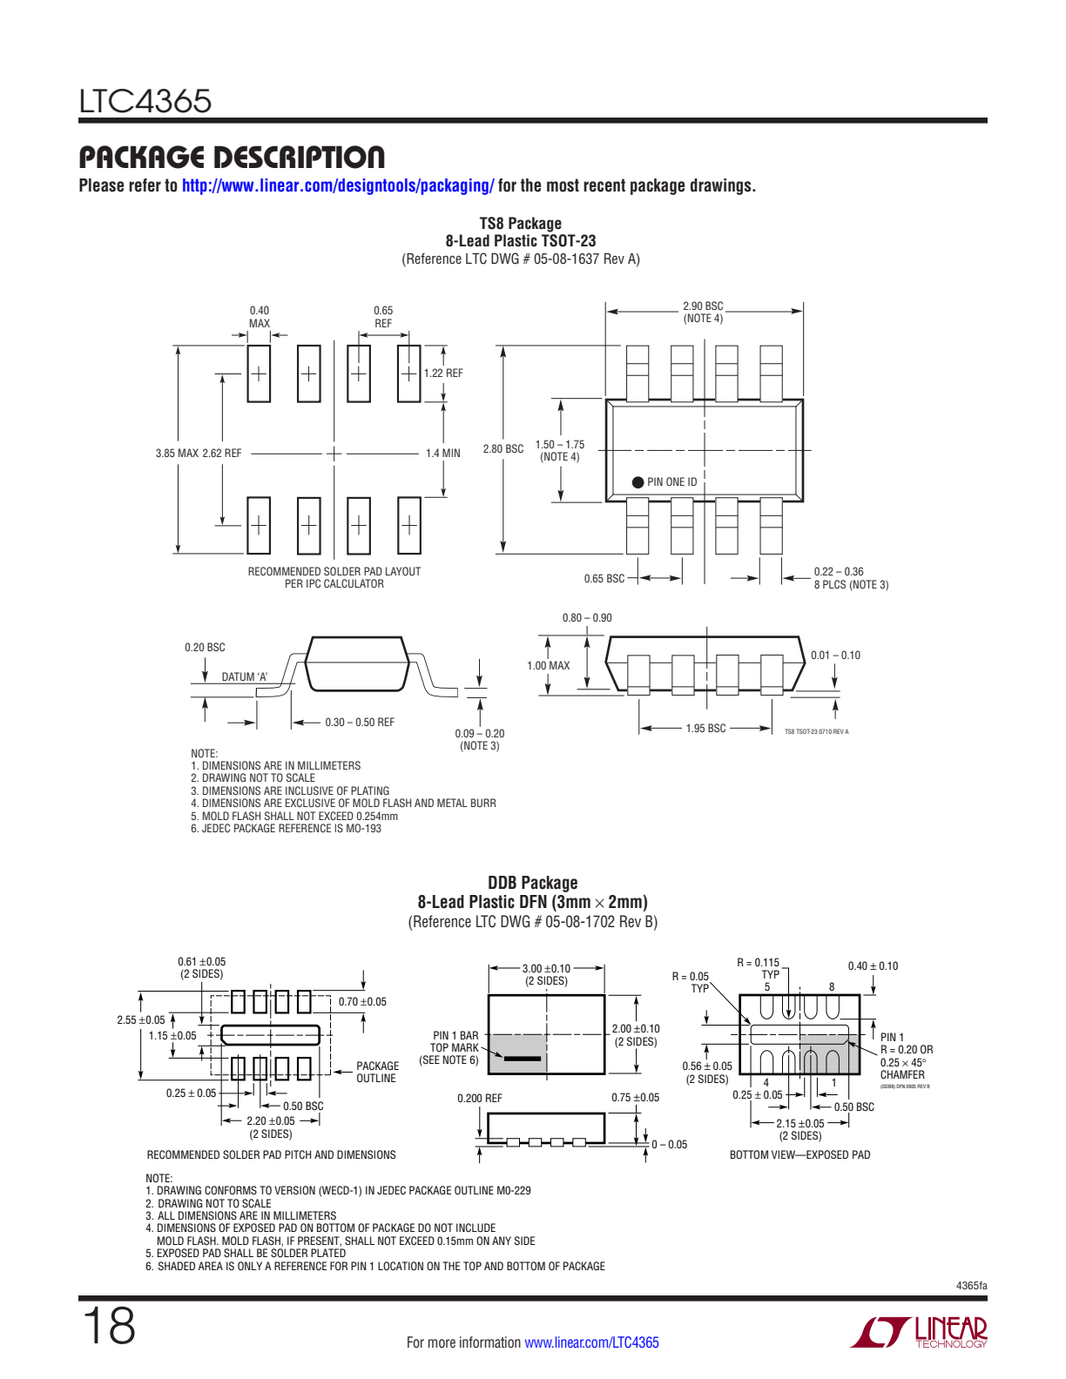
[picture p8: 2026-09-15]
hardware/checkpoints/PoE-Speaker-Checkpoint/PoE-Speaker-RevD-eFuse-Draft/KiCad-RevD/reports/ltc-package.png

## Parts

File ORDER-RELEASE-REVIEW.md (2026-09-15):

# Prototype order release review

**Updated:** 2026-09-14  
**Status:** **HOLD — not ready to order.**

The current board is [`hardware/PoE-Speaker/RevE/KiCad-RevE/PoE-Speaker-RevE.kicad_pcb`](hardware/PoE-Speaker/RevE/KiCad-RevE/PoE-Speaker-RevE.kicad_pcb). No manufacturing package is approved by this document.

## Release priorities

| Area | Evidence / current state | Work required before order |
| --- | --- | --- |
| **Ethernet layout** | Saved routing reviews show TX and RX still include layer changes, branch taps, and signal vias. RX main-route work has improved the front-layer corridor and shortened / localized termination branches, but the current metrics are geometry screens rather than exact differential-pair skew or SI validation. | Rework PHY, termination, ESD, and jack routing as intentional differential pairs. The current Ethernet100 starting geometry is 0.225806 mm width / 0.2032 mm gap on F.Cu over In1 GND. Prefer no signal vias. Verify reference continuity, isolation keepouts, and actual fabrication stackup. |
| **Physical stackup** | JLC04161H-7628 is saved as the current planning baseline. See [ETHERNET-STACKUP.md](hardware/PoE-Speaker/RevE/engineering/ETHERNET-STACKUP.md). | Use the baseline for planning calculations, then confirm finished copper, dielectric thickness, plating, and impedance geometry with the selected fabricator before ordering. |
| **Mechanical coverage** | Eight B5100C courtyards have been added and checked. Thirteen non-feature footprints still lack verified courtyard graphics in the saved review. | Add / verify remaining body and assembly envelopes. Inspect underside components, connector access, PoE-module support, and amplifier heatsink clearance. |
| **Mounting** | H3 / H4 moved to `(275,55)` / `(275,145)`, 5 mm from the extended edge. Existing left holes are at `(75,55)` / `(75,145)`. | Use insulating M2 standoffs for the prototype. Enclosure fit remains unconfirmed. |
| **Power paths / ground** | Recent track, via, and decoupling improvements pass the saved DRC. Remaining constrained vias and amplifier-ground paths are documented. | Calculate current capability using actual copper / plating assumptions. Review regulator input / output loops and remaining amplifier ground access. Geometry audits do not provide a current rating. |
| **Fuse / protection** | F1's manufacturer publishes DC interrupt ratings. [EFUSE-REVIEW.md](hardware/PoE-Speaker/RevE/engineering/EFUSE-REVIEW.md) contains nominal settings and startup estimates. | Check source fault-current bounds, fuse timing / let-through, protection tolerances, and transient behavior. The 3.15 A fuse is not an instantaneous current clamp. |
| **Assembly process** | U2 / U16 currently use thermal vias in solderable pads. | Specify filled / capped via-in-pad treatment and stencil / process requirements, or revise the land treatment. Confirm BOM / placement orientation and component supply. |
| **Electrical consistency** | Saved DRC / ERC are zero under the current profile, and 616 model / schematic / PCB connected pins match. | Preserve these checks after changes and complete circuit / footprint review beyond serialization. |
| **Manufacturing outputs** | No order-ready fabrication package has been generated. | After design checks, export and inspect Gerber, drill, BOM, and placement files from the exact reviewed source revision. Include fabrication notes and source hash. |

## Scope of the first prototype

This release is for the **network speaker main board**. Microphone-ring development remains a separate parallel track and should not block first-prototype validation of Ethernet, power, DAC, and amplifier functions.

Hardware measurements, firmware validation, and full-power thermal / audio testing happen after assembly; they cannot be completed from CAD alone. Bench bring-up should begin with a current-limited isolated supply and staged rail checks.

See the [prototype validation plan](PROTOTYPE-VALIDATION.md) for the intended bring-up sequence.

## Source guidance

Key external references used by the existing review work include:

- WIZnet hardware design guide — 100 ohm differential routing, short matched MDI paths, no signal-layer changes, and placement / reference guidance.
- W5500 reference schematic.
- JLCPCB documented 4-layer stackups; JLC04161H-7628 is currently used only as a planning baseline.
- F1 manufacturer DC interrupt / fuse data; see [FUSE-RATING-REVIEW.md](hardware/PoE-Speaker/RevE/engineering/FUSE-RATING-REVIEW.md).

The existing engineering notes preserve the original source URLs and detailed calculations where applicable.

## Next implementation sequence

1. Ethernet placement / differential-pair routing / reference continuity.
2. Remaining mechanical envelopes and assembly constraints.
3. Power / protection calculations and fault-case review.
4. Circuit / footprint review for DAC, amplifier, regulators, and connectors.
5. Generate and inspect a reproducible fabrication package from a frozen source revision.

Do not treat another isolated clean DRC result as a release decision. The order gate remains **HOLD** until the engineering blockers are resolved or explicitly accepted.

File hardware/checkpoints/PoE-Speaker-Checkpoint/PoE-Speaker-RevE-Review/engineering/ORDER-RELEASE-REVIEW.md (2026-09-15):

# Prototype order release review

Updated 2026-09-14. **HOLD: not ready to order.** The latest board remains KiCad-RevE/PoE-Speaker-RevE.kicad_pcb. No manufacturing ZIP is approved by this document.

## Release priorities

| Area | Evidence / current state | Work required before order |
|---|---|---|
| Ethernet layout | ethernet-routing-review.json and ethernet-path-review.json: TX_P uses F/B/In2, TX_N uses F/B, and RX_P/RX_N now use F/B; seven signal vias remain including branch taps. Five receive main-route segments have moved from In2 to F.Cu after coordinated TX_N and analog-supply rerouting. R101/R102 termination branches are now local; see ethernet-front-corridor.json. RX termination R104/R105/C102 is now a local bottom-side cluster; twelve obsolete branch items were removed, reducing total RX-net copper from 81.680 mm to 55.734 mm. These totals include branches, not just pair lengths. Current PHY-to-jack screening paths are regenerated in ethernet-path-review.json; TX_N main route was shortened by about 1.557 mm. These are whole-segment metrics, not exact skew. | Rework PHY, termination, ESD and jack routing as differential pairs. The sourced Ethernet100 preset now supplies 100 ohm starting geometry: 0.225806 mm width / 0.2032 mm gap on F.Cu over In1 GND. Implement and inspect pair routing; these defaults do not constrain existing copper. Prefer no signal vias. Check reference continuity and jack isolation keepouts. |
| Physical stackup | Explicit JLC04161H-7628 copper/dielectric baseline is now saved in the PCB; see ETHERNET-STACKUP.md. | Use this baseline for impedance/current calculations. Confirm the stackup, finished copper, plating and impedance geometry with fabrication before order; the saved baseline is not an order approval. |
| Mechanical coverage | Eight B5100C courtyards added and checked. Thirteen non-feature footprints still lack courtyard graphics; see courtyard-coverage.json. | Add verified body/assembly envelopes for the remaining components; inspect underside parts, connector access, Ag5800 support and amplifier top heatsink. |
| Mounting | H3/H4 moved to (275,55)/(275,145), 5 mm from extended edge. Existing left holes at (75,55)/(75,145). | Use insulating M2 standoffs for the prototype. Enclosure fit remains unconfirmed. |
| Power paths / ground | Recent track/via/decoupling improvements pass saved DRC. Remaining constrained vias and amplifier ground paths are documented. | Calculate with actual copper/plating assumptions; review regulator input/output loops and remaining amplifier ground access. Geometric path audits do not provide a current rating. |
| Fuse and protection | F1 manufacturer now confirmed to publish DC interrupt ratings. EFUSE-REVIEW.md contains nominal settings and startup estimates. | Check source fault-current bounds, fuse timing/let-through, protection tolerances and transients. The 3.15 A fuse is not an instantaneous current clamp. |
| Assembly process | U2/U16 have thermal vias in solderable pads. | Specify filled/capped via-in-pad treatment and stencil/process requirements or revise the land treatment. Confirm BOM/placement orientation and component supply. |
| Electrical consistency | Saved DRC/ERC zero and 616 model/schematic/PCB connected pins match. | Preserve these checks after changes; finish circuit/footprint review beyond serialization. |
| Manufacturing outputs | Not generated for ordering. | After design checks, export and inspect Gerber/drill/BOM/placement files from the exact checked board; include fab notes and source hash. |

## Scope of first prototype

This is the network speaker main board. Eight-microphone capture/ring development remains separate, as requested. Hardware measurements, firmware validation and full-power thermal/audio testing happen after assembly; they are not tests that can be completed without prototype hardware. Bench bring-up should begin with a current-limited isolated supply and staged rail checks. A clean CAD report alone does not establish functional performance.

## Sources and review interpretation

- WIZnet hardware design guide: https://docs.wiznet.io/Design-Guide/hardware_design_guide — 100 ohm differential routing, short matched MDI paths, no signal layer changes, and placement/reference guidance. Current Ethernet layer changes depart from this guidance and require rework or substantiated qualification.
- W5500 reference schematic: https://docs.wiznet.io/assets/files/w5500_sch_v110_use_trans_-18b3297138bdf20fafd0f95e4c19358d.pdf
- JLCPCB documented stackups: https://jlcpcb.com/impedance — candidate 1.6 mm JLC04161H-7628 lists 0.035 mm outer copper, 0.21040 mm outer dielectrics, 0.0152 mm inner copper and 1.065 mm core. These numbers are planning inputs until a fabrication process is selected; solder mask and fabrication tolerances also affect impedance.
- F1 manufacturer: https://www.xcfuse.com/smd_fuses/24T_119.html — details in FUSE-RATING-REVIEW.md.

Next implementation: Ethernet placement/routing and stackup, then remaining mechanical envelopes and power/protection calculations. Do not spend the next chunk treating another isolated clean DRC result as a release decision.

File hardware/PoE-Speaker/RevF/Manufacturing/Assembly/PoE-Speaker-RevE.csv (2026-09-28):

Reference | Qty | Value | DNP | Exclude from BOM | Exclude from Board | Footprint | Datasheet | LCSC Part Number | Manufacturer Part Number | Package or Case Code
C1 | 1 | 1000uF |  |  |  | SpeakerRevB:C1_RevB |  |  | EEUFR1E102
C2 | 1 | 1000uF |  |  |  | SpeakerRevB:C2_RevB |  |  | EEUFR1E102
C3 | 1 | 1000uF |  |  |  | SpeakerRevB:C3_RevB |  |  | EEUFR1V102
C4 | 1 | 1000uF |  |  |  | SpeakerRevB:C4_RevB |  |  | EEUFR1V102
C5 | 1 | 100uF |  |  |  | SpeakerRevB:C5_RevB |  |  | EEUFR1H101
C6 | 1 | 100uF |  |  |  | SpeakerRevB:C6_RevB |  |  | EEUFR1H101
C7 | 1 | 220nF |  |  |  | SpeakerRevB:C7_RevB | https://search.kemet.com/component-documentation/download/specsheet/C0603C224K5RACTU |  | C0603C224K5RACTU
C8 | 1 | 220nF |  |  |  | SpeakerRevB:C8_RevB | https://search.kemet.com/component-documentation/download/specsheet/C0603C224K5RACTU |  | C0603C224K5RACTU
C9 | 1 | 220nF |  |  |  | SpeakerRevB:C9_RevB | https://search.kemet.com/component-documentation/download/specsheet/C0603C224K5RACTU |  | C0603C224K5RACTU
C10 | 1 | 220nF |  |  |  | SpeakerRevB:C10_RevB | https://search.kemet.com/component-documentation/download/specsheet/C0603C224K5RACTU |  | C0603C224K5RACTU
C11 | 1 | 1uF |  |  |  | SpeakerRevB:C11_RevB | https://search.kemet.com/component-documentation/download/specsheet/C0603C105K4RACTU |  | C0603C105K4RACTU
C12 | 1 | 1uF |  |  |  | SpeakerRevB:C12_RevB | https://search.kemet.com/component-documentation/download/specsheet/C1210C105K1RACTU |  | C1210C105K1RACTU
C13 | 1 | 1uF |  |  |  | SpeakerRevB:C13_RevB | https://search.kemet.com/component-documentation/download/specsheet/C1210C105K1RACTU |  | C1210C105K1RACTU
C14 | 1 | 1uF |  |  |  | SpeakerRevB:C14_RevB | https://search.kemet.com/component-documentation/download/specsheet/C1210C105K1RACTU |  | C1210C105K1RACTU
C15 | 1 | 1uF |  |  |  | SpeakerRevB:C15_RevB | https://search.kemet.com/component-documentation/download/specsheet/C1210C105K1RACTU |  | C1210C105K1RACTU
C16 | 1 | 1uF |  |  |  | SpeakerRevB:C16_RevB | https://search.kemet.com/component-documentation/download/specsheet/C1210C105K1RACTU |  | C1210C105K1RACTU
C17 | 1 | 2.2uF |  |  |  | SpeakerRevB:C17_RevB | https://search.kemet.com/component-documentation/download/specsheet/C0805C225K3RACTU |  | C0805C225K3RACTU
C18 | 1 | 2.2uF |  |  |  | SpeakerRevB:C18_RevB | https://search.kemet.com/component-documentation/download/specsheet/C0805C225K3RACTU |  | C0805C225K3RACTU
C19 | 1 | 2.2nF |  |  |  | SpeakerRevB:C19_RevB | https://search.kemet.com/component-documentation/download/specsheet/C0603C222J5GACTU |  | C0603C222J5GACTU
C20 | 1 | 2.2uF |  |  |  | SpeakerRevB:C20_RevB | https://search.kemet.com/component-documentation/download/specsheet/C0805C225K3RACTU |  | C0805C225K3RACTU
C21 | 1 | 2.2uF |  |  |  | SpeakerRevB:C21_RevB | https://search.kemet.com/component-documentation/download/specsheet/C0805C225K3RACTU |  | C0805C225K3RACTU
C22 | 1 | 10uF |  |  |  | SpeakerRevB:C22_RevB | https://www.murata.com/en-global/products/productdetail?partno=GRM21BR61C106KE15L |  | GRM21BR61C106KE15L
C23 | 1 | 10uF |  |  |  | SpeakerRevB:C23_RevB | https://www.murata.com/en-global/products/productdetail?partno=GRM21BR61C106KE15L |  | GRM21BR61C106KE15L
C24 | 1 | 10uF |  |  |  | SpeakerRevB:C24_RevB | https://www.murata.com/en-global/products/productdetail?partno=GRM21BR61C106KE15L |  | GRM21BR61C106KE15L
C25 | 1 | 10uF |  |  |  | SpeakerRevB:C25_RevB | https://www.murata.com/en-global/products/productdetail?partno=GRM21BR61C106KE15L |  | GRM21BR61C106KE15L
C26 | 1 | 100nF |  |  |  | SpeakerRevB:C26_RevB | https://search.kemet.com/component-documentation/download/specsheet/C0603C104K5RACTU |  | C0603C104K5RACTU
C27 | 1 | 100nF |  |  |  | SpeakerRevB:C27_RevB | https://search.kemet.com/component-documentation/download/specsheet/C0603C104K5RACTU |  | C0603C104K5RACTU
C28 | 1 | 100nF |  |  |  | SpeakerRevB:C28_RevB | https://search.kemet.com/component-documentation/download/specsheet/C0603C104K5RACTU |  | C0603C104K5RACTU
C29 | 1 | 100nF |  |  |  | SpeakerRevB:C29_RevB | https://search.kemet.com/component-documentation/download/specsheet/C0603C104K5RACTU |  | C0603C104K5RACTU
C30 | 1 | 100nF |  |  |  | SpeakerRevB:C30_RevB | https://search.kemet.com/component-documentation/download/specsheet/C0603C104K5RACTU |  | C0603C104K5RACTU
C31 | 1 | 22uF |  |  |  | SpeakerRevB:C31_RevB | https://www.murata.com/en-global/products/productdetail?partno=GRM21BR61C226ME44L |  | GRM21BR61C226ME44L
C32 | 1 | 100nF |  |  |  | SpeakerRevB:C32_RevB | https://search.kemet.com/component-documentation/download/specsheet/C0603C104K5RACTU |  | C0603C104K5RACTU
C33 | 1 | 100nF |  |  |  | SpeakerRevB:C33_RevB | https://search.kemet.com/component-documentation/download/specsheet/C0603C104K5RACTU |  | C0603C104K5RACTU
C40 | 1 | 10uF |  |  |  | SpeakerRevB:C40_RevB | https://search.kemet.com/component-documentation/download/specsheet/C1210C106K5RACTU |  | C1210C106K5RACTU
C41 | 1 | 220nF |  |  |  | SpeakerRevB:C41_RevB | https://search.kemet.com/component-documentation/download/specsheet/C0603C224K5RACTU |  | C0603C224K5RACTU
C42 | 1 | 100nF |  |  |  | SpeakerRevB:C42_RevB | https://search.kemet.com/component-documentation/download/specsheet/C0603C104K5RACTU |  | C0603C104K5RACTU
C43 | 1 | 1uF |  |  |  | SpeakerRevB:C43_RevB | https://search.kemet.com/component-documentation/download/specsheet/C0603C105K4RACTU |  | C0603C105K4RACTU
C44 | 1 | 22uF |  |  |  | SpeakerRevB:C44_RevB | https://search.kemet.com/component-documentation/download/specsheet/C1210C226K3RACTU |  | C1210C226K3RACTU
C45 | 1 | 22uF |  |  |  | SpeakerRevB:C45_RevB | https://search.kemet.com/component-documentation/download/specsheet/C1210C226K3RACTU |  | C1210C226K3RACTU
C46 | 1 | 22uF |  |  |  | SpeakerRevB:C46_RevB | https://search.kemet.com/component-documentation/download/specsheet/C1210C226K3RACTU |  | C1210C226K3RACTU
C47 | 1 | 22uF |  |  |  | SpeakerRevB:C47_RevB | https://search.kemet.com/component-documentation/download/specsheet/C1210C226K3RACTU |  | C1210C226K3RACTU
C48 | 1 | 10uF |  |  |  | SpeakerRevB:C48_RevB | https://www.murata.com/en-global/products/productdetail?partno=GRM21BR61C106KE15L |  | GRM21BR61C106KE15L
C49 | 1 | 22uF |  |  |  | SpeakerRevB:C49_RevB | https://www.murata.com/en-global/products/productdetail?partno=GRM21BR61C226ME44L |  | GRM21BR61C226ME44L
C50 | 1 | 47uF |  |  |  | SpeakerRevB:C50_RevB | https://www.murata.com/en-global/products/productdetail?partno=GRM32ER61C476KE15L |  | GRM32ER61C476KE15L
C51 | 1 | 4.7uF |  |  |  | SpeakerRevB:C51_RevB | https://search.kemet.com/component-documentation/download/specsheet/C0805C475K4RACTU |  | C0805C475K4RACTU
C52 | 1 | 4.7uF |  |  |  | SpeakerRevB:C52_RevB | https://search.kemet.com/component-documentation/download/specsheet/C0805C475K4RACTU |  | C0805C475K4RACTU
C53 | 1 | 3.3nF |  |  |  | SpeakerRevB:C53_RevB | https://search.kemet.com/component-documentation/download/specsheet/C0603C332J5GACTU |  | C0603C332J5GACTU
C55 | 1 | 100nF |  |  |  | SpeakerRevB:C55_RevB | https://search.kemet.com/component-documentation/download/specsheet/C0603C104K5RACTU |  | C0603C104K5RACTU
C56 | 1 | 100nF |  |  |  | SpeakerRevB:C56_RevB | https://search.kemet.com/component-documentation/download/specsheet/C0603C104K5RACTU |  | C0603C104K5RACTU
C57 | 1 | 100nF |  |  |  | SpeakerRevB:C57_RevB | https://search.kemet.com/component-documentation/download/specsheet/C0603C104K5RACTU |  | C0603C104K5RACTU
C58 | 1 | 1uF |  |  |  | SpeakerRevB:C58_RevB | https://search.kemet.com/component-documentation/download/specsheet/C0603C105K4RACTU |  | C0603C105K4RACTU
C100 | 1 | 22nF |  |  |  | SpeakerRevB:C100_RevB | https://search.kemet.com/component-documentation/download/specsheet/C0603C223K5RACTU |  | C0603C223K5RACTU
C101 | 1 | 6.8nF |  |  |  | SpeakerRevB:C101_RevB | https://search.kemet.com/component-documentation/download/specsheet/C0603C682J5GACTU |  | C0603C682J5GACTU
C102 | 1 | 10nF |  |  |  | SpeakerRevB:C102_RevB | https://search.kemet.com/component-documentation/download/specsheet/C0603C103K5RACTU |  | C0603C103K5RACTU
C103 | 1 | 4.7uF |  |  |  | SpeakerRevB:C103_RevB | https://search.kemet.com/component-documentation/download/specsheet/C0805C475K4RACTU |  | C0805C475K4RACTU
C104 | 1 | 10nF |  |  |  | SpeakerRevB:C104_RevB | https://search.kemet.com/component-documentation/download/specsheet/C0603C103K5RACTU |  | C0603C103K5RACTU
C105 | 1 | 100nF |  |  |  | SpeakerRevB:C105_RevB | https://search.kemet.com/component-documentation/download/specsheet/C0603C104K5RACTU |  | C0603C104K5RACTU
C106 | 1 | 100nF |  |  |  | SpeakerRevB:C106_RevB | https://search.kemet.com/component-documentation/download/specsheet/C0603C104K5RACTU |  | C0603C104K5RACTU
C107 | 1 | 100nF |  |  |  | SpeakerRevB:C107_RevB | https://search.kemet.com/component-documentation/download/specsheet/C0603C104K5RACTU |  | C0603C104K5RACTU
C108 | 1 | 100nF |  |  |  | SpeakerRevB:C108_RevB | https://search.kemet.com/component-documentation/download/specsheet/C0603C104K5RACTU |  | C0603C104K5RACTU
C109 | 1 | 100nF |  |  |  | SpeakerRevB:C109_RevB | https://search.kemet.com/component-documentation/download/specsheet/C0603C104K5RACTU |  | C0603C104K5RACTU
C110 | 1 | 100nF |  |  |  | SpeakerRevB:C110_RevB | https://search.kemet.com/component-documentation/download/specsheet/C0603C104K5RACTU |  | C0603C104K5RACTU
C111 | 1 | 10uF |  |  |  | SpeakerRevB:C111_RevB | https://www.murata.com/en-global/products/productdetail?partno=GRM21BR61C106KE15L |  | GRM21BR61C106KE15L
C112 | 1 | 100nF |  |  |  | SpeakerRevB:C112_RevB | https://search.kemet.com/component-documentation/download/specsheet/C0603C104K5RACTU |  | C0603C104K5RACTU
C113 | 1 | 10uF |  |  |  | SpeakerRevB:C113_RevB | https://www.murata.com/en-global/products/productdetail?partno=GRM21BR61C106KE15L |  | GRM21BR61C106KE15L
C114 | 1 | 1uF |  |  |  | SpeakerRevB:C114_RevB | https://search.kemet.com/component-documentation/download/specsheet/C0603C105K4RACTU |  | C0603C105K4RACTU
C115 | 1 | 100nF |  |  |  | SpeakerRevB:C115_RevB | https://search.kemet.com/component-documentation/download/specsheet/C0603C104K5RACTU |  | C0603C104K5RACTU
C120,C121 | 2 | 100nF |  |  |  | SpeakerRevB:C_1210_3225Metric | https://search.kemet.com/component-documentation/download/specsheet/C1210C104J1GACTU |  | C1210C104J1GACTU
C122 | 1 | 1uF |  |  |  | SpeakerRevB:C_1210_3225Metric | https://search.kemet.com/component-documentation/download/specsheet/C1210C105K1RACTU |  | C1210C105K1RACTU
C123 | 1 | 1uF |  |  |  | SpeakerRevB:C123_RevB | https://search.kemet.com/component-documentation/download/specsheet/C0805C105K5RACTU |  | C0805C105K5RACTU
D1 | 1 | PRTR5V0U4D,125 |  |  |  | SpeakerRevB:D1_RevB |  |  | PRTR5V0U4D,125 | TO
D2 | 1 | SMAJ58A-TR |  |  |  | SpeakerRevB:D2_RevB |  | C132936 | SMAJ58A-TR | SMA_L4.4-W2.8-LS5.4-RD
D3 | 1 | B5100C |  |  |  | SpeakerRevB:D3_RevB |  |  | B5100C | SMC (DO-214AB)
D4 | 1 | B5100C |  |  |  | SpeakerRevB:D4_RevB |  |  | B5100C | SMC (DO-214AB)
D5 | 1 | B5100C |  |  |  | SpeakerRevB:D5_RevB |  |  | B5100C | SMC (DO-214AB)
D6 | 1 | B5100C |  |  |  | SpeakerRevB:D6_RevB |  |  | B5100C | SMC (DO-214AB)
D7 | 1 | B5100C |  |  |  | SpeakerRevB:D7_RevB |  |  | B5100C | SMC (DO-214AB)
D8 | 1 | B5100C |  |  |  | SpeakerRevB:D8_RevB |  |  | B5100C | SMC (DO-214AB)
D9 | 1 | B5100C |  |  |  | SpeakerRevB:D9_RevB |  |  | B5100C | SMC (DO-214AB)
D10 | 1 | B5100C |  |  |  | SpeakerRevB:D10_RevB |  |  | B5100C | SMC (DO-214AB)
D11 | 1 | SMBJ26CA |  |  |  | SpeakerRevB:D11_RevB |  |  | SMBJ26CA
F1 | 1 | 24T 3.15A250V |  |  |  | SpeakerRevB:F1_RevB |  | C2905508 | 24T 3.15A250V | FUSE-SMD_L6.1-W2.6
FB1 | 1 | 600ohm@100MHz |  |  |  | SpeakerRevB:FB1_RevB | https://www.murata.com/en-us/products/productdata/8796738650142/ENFA0003.pdf |  | BLM18AG601SN1D
FB2 | 1 | 120R@100MHz |  |  |  | SpeakerRevB:FB2_RevB |  |  | BLM18PG121SN1D
H1 | 1 | MountingHole |  |  |  | SpeakerRevB:H1_RevB |  |  | MountingHole
H2 | 1 | MountingHole |  |  |  | SpeakerRevB:H2_RevB |  |  | MountingHole
H3 | 1 | MountingHole |  |  |  | SpeakerRevB:H3_RevB |  |  | MountingHole
H4 | 1 | MountingHole |  |  |  | SpeakerRevB:H4_RevB |  |  | MountingHole
J1 | 1 | 2250506-1 |  |  |  | SpeakerRevB:J1_RevB |  |  | 2250506-1
J2 | 1 | MX2EDGR-5.08-02P-GN01-Cu-A |  |  |  | SpeakerRevB:J2_RevB |  | C5187973 | MX2EDGR-5.08-02P-GN01-Cu-A
J3 | 1 | MX2EDGR-5.08-02P-GN01-Cu-A |  |  |  | SpeakerRevB:J3_RevB |  | C5187973 | MX2EDGR-5.08-02P-GN01-Cu-A
J4 | 1 | Pin Header 02x07 2.54mm Vertical |  |  |  | SpeakerRevB:J4_RevB | https://www.samtec.com/products/TSW-107-07-G-D |  | TSW-107-07-G-D
J5 | 1 | Pin Header 01x06 2.54mm Vertical |  |  |  | SpeakerRevB:J5_RevB | https://www.samtec.com/products/TSW-106-07-G-S |  | TSW-106-07-G-S
J6 | 1 | Pin Header 01x06 2.54mm Vertical |  |  |  | SpeakerRevB:J6_RevB | https://www.samtec.com/products/TSW-106-07-G-S |  | TSW-106-07-G-S
L1 | 1 | 10uH |  |  |  | SpeakerRevB:L1_RevB |  |  | SRP1038A-100M
L2 | 1 | 10uH |  |  |  | SpeakerRevB:L2_RevB |  |  | SRP1038A-100M
L3 | 1 | 8.2uH |  |  |  | SpeakerRevB:L3_RevB |  |  | XAL5050-822MEC
L4 | 1 | 2.2uH |  |  |  | SpeakerRevB:L4_RevB |  |  | XAL5030-222MEC
LED1 | 1 | SML-D13FWT86C |  |  |  | SpeakerRevB:LED1_RevB |  |  | SML-D13FWT86C
LED2 | 1 | SML-D13FWT86C |  |  |  | SpeakerRevB:LED2_RevB |  |  | SML-D13FWT86C
LED3 | 1 | SML-D13FWT86C |  |  |  | SpeakerRevB:LED3_RevB |  |  | SML-D13FWT86C
Q1 | 1 | DMNH6012LK3-13 |  |  |  | SpeakerRevB:Q1_RevB |  |  | DMNH6012LK3-13
Q2 | 1 | DMNH6012LK3-13 |  |  |  | SpeakerRevB:Q2_RevB |  |  | DMNH6012LK3-13
Q3 | 1 | PSMN4R8-100BSE |  |  |  | SpeakerRevB:Q3_RevB |  |  | PSMN4R8-100BSE
Q4 | 1 | PSMN4R8-100BSE |  |  |  | SpeakerRevB:Q4_RevB |  |  | PSMN4R8-100BSE
R3 | 1 | 27kΩ |  |  |  | SpeakerRevB:R3_RevB | https://www.vishay.com/docs/28758/tnpw_e3.pdf |  | TNPW120627K0FHEA
R4 | 1 | 27kΩ |  |  |  | SpeakerRevB:R4_RevB | https://www.vishay.com/docs/28758/tnpw_e3.pdf |  | TNPW120627K0FHEA
R5 | 1 | 27kΩ |  |  |  | SpeakerRevB:R5_RevB | https://www.vishay.com/docs/28758/tnpw_e3.pdf |  | TNPW120627K0FHEA
R6 | 1 | 10kΩ |  |  |  | SpeakerRevB:R6_RevB | https://www.vishay.com/docs/28758/tnpw_e3.pdf |  | TNPW060310K0FHEA
R7 | 1 | 10kΩ |  |  |  | SpeakerRevB:R7_RevB | https://www.vishay.com/docs/28758/tnpw_e3.pdf |  | TNPW060310K0FHEA
R8 | 1 | 10kΩ |  |  |  | SpeakerRevB:R8_RevB | https://www.vishay.com/docs/28758/tnpw_e3.pdf |  | TNPW060310K0FHEA
R9 | 1 | 10kΩ |  |  |  | SpeakerRevB:R9_RevB | https://www.vishay.com/docs/28758/tnpw_e3.pdf |  | TNPW060310K0FHEA
R13 | 1 | 470Ω |  |  |  | SpeakerRevB:R13_RevB | https://www.vishay.com/docs/28758/tnpw_e3.pdf |  | TNPW0603470RFHEA
R14 | 1 | 5.6kΩ |  |  |  | SpeakerRevB:R14_RevB | https://www.vishay.com/docs/28758/tnpw_e3.pdf |  | TNPW06035K60FHEA
R15 | 1 | 82kΩ |  |  |  | SpeakerRevB:R15_RevB | https://www.vishay.com/docs/28758/tnpw_e3.pdf |  | TNPW060382K0FHEA
R16 | 1 | 51kΩ |  |  |  | SpeakerRevB:R16_RevB | https://www.vishay.com/docs/28758/tnpw_e3.pdf |  | TNPW060351K0FHEA
R17 | 1 | 10kΩ |  |  |  | SpeakerRevB:R17_RevB | https://www.vishay.com/docs/28758/tnpw_e3.pdf |  | TNPW060310K0FHEA
R23 | 1 | 100kΩ |  |  |  | SpeakerRevB:R23_RevB | https://www.vishay.com/docs/28758/tnpw_e3.pdf |  | TNPW0603100KFHEA
R24 | 1 | 24.9kΩ |  |  |  | SpeakerRevB:R24_RevB | https://www.vishay.com/docs/28758/tnpw_e3.pdf |  | TNPW060324K9FHEA
R25 | 1 | 1kΩ |  |  |  | SpeakerRevB:R25_RevB | https://www.vishay.com/docs/28758/tnpw_e3.pdf |  | TNPW06031K00FHEA
R26 | 1 | 1kΩ |  |  |  | SpeakerRevB:R26_RevB | https://www.vishay.com/docs/28758/tnpw_e3.pdf |  | TNPW06031K00FHEA
R27 | 1 | 1kΩ |  |  |  | SpeakerRevB:R27_RevB | https://www.vishay.com/docs/28758/tnpw_e3.pdf |  | TNPW06031K00FHEA
R28 | 1 | 33Ω |  |  |  | SpeakerRevB:R28_RevB | https://www.vishay.com/docs/28758/tnpw_e3.pdf |  | TNPW060333R0FHEA
R29 | 1 | 33Ω |  |  |  | SpeakerRevB:R29_RevB | https://www.vishay.com/docs/28758/tnpw_e3.pdf |  | TNPW060333R0FHEA
R30 | 1 | 33Ω |  |  |  | SpeakerRevB:R30_RevB | https://www.vishay.com/docs/28758/tnpw_e3.pdf |  | TNPW060333R0FHEA
R31 | 1 | 33Ω |  |  |  | SpeakerRevB:R31_RevB | https://www.vishay.com/docs/28758/tnpw_e3.pdf |  | TNPW060333R0FHEA
R32 | 1 | 33Ω |  |  |  | SpeakerRevB:R32_RevB | https://www.vishay.com/docs/28758/tnpw_e3.pdf |  | TNPW060333R0FHEA
R33 | 1 | 4.7kΩ |  |  |  | SpeakerRevB:R33_RevB | https://www.vishay.com/docs/28758/tnpw_e3.pdf |  | TNPW06034K70FHEA
R34 | 1 | 4.7kΩ |  |  |  | SpeakerRevB:R34_RevB | https://www.vishay.com/docs/28758/tnpw_e3.pdf |  | TNPW06034K70FHEA
R35 | 1 | 100kΩ |  |  |  | SpeakerRevB:R35_RevB | https://www.vishay.com/docs/28758/tnpw_e3.pdf |  | TNPW0603100KFHEA
R36 | 1 | 100kΩ |  |  |  | SpeakerRevB:R36_RevB | https://www.vishay.com/docs/28758/tnpw_e3.pdf |  | TNPW0603100KFHEA
R38 | 1 | 10kΩ |  |  |  | SpeakerRevB:R38_RevB | https://www.vishay.com/docs/28758/tnpw_e3.pdf |  | TNPW060310K0FHEA
R100 | 1 | 12.4k |  |  |  | SpeakerRevB:R100_RevB | https://www.vishay.com/docs/28758/tnpw_e3.pdf |  | TNPW060312K4FHEA
R101 | 1 | 49.9 |  |  |  | SpeakerRevB:R101_RevB | https://www.vishay.com/docs/28758/tnpw_e3.pdf |  | TNPW060349R9FHEA
R102 | 1 | 49.9 |  |  |  | SpeakerRevB:R102_RevB | https://www.vishay.com/docs/28758/tnpw_e3.pdf |  | TNPW060349R9FHEA
R103 | 1 | 10 |  |  |  | SpeakerRevB:R103_RevB | https://www.vishay.com/docs/28758/tnpw_e3.pdf |  | TNPW060310R0FHEA
R104 | 1 | 49.9 |  |  |  | SpeakerRevB:R104_RevB | https://www.vishay.com/docs/28758/tnpw_e3.pdf |  | TNPW060349R9FHEA
R105 | 1 | 49.9 |  |  |  | SpeakerRevB:R105_RevB | https://www.vishay.com/docs/28758/tnpw_e3.pdf |  | TNPW060349R9FHEA
R106 | 1 | 10k |  |  |  | SpeakerRevB:R106_RevB | https://www.vishay.com/docs/28758/tnpw_e3.pdf |  | TNPW060310K0FHEA
R107 | 1 | 10k |  |  |  | SpeakerRevB:R107_RevB | https://www.vishay.com/docs/28758/tnpw_e3.pdf |  | TNPW060310K0FHEA
R108 | 1 | 33 |  |  |  | SpeakerRevB:R108_RevB | https://www.vishay.com/docs/28758/tnpw_e3.pdf |  | TNPW060333R0FHEA
R109 | 1 | 33 |  |  |  | SpeakerRevB:R109_RevB | https://www.vishay.com/docs/28758/tnpw_e3.pdf |  | TNPW060333R0FHEA
R110 | 1 | 10k |  |  |  | SpeakerRevB:R110_RevB | https://www.vishay.com/docs/28758/tnpw_e3.pdf |  | TNPW060310K0FHEA
R111 | 1 | 10k |  |  |  | SpeakerRevB:R111_RevB | https://www.vishay.com/docs/28758/tnpw_e3.pdf |  | TNPW060310K0FHEA
R120 | 1 | 198k |  |  |  | SpeakerRevB:R120_RevB | https://www.vishay.com/docs/28758/tnpw_e3.pdf |  | TNPW0805198KBYEA
R121 | 1 | 4.02k |  |  |  | SpeakerRevB:R121_RevB | https://www.vishay.com/docs/28758/tnpw_e3.pdf |  | TNPW08054K02BYEA
R122 | 1 | 392k |  |  |  | SpeakerRevB:R122_RevB | https://www.vishay.com/docs/28758/tnpw_e3.pdf |  | TNPW0805392KFHEA
R123 | 1 | 10k |  |  |  | SpeakerRevB:R123_RevB | https://www.vishay.com/docs/28758/tnpw_e3.pdf |  | TNPW080510K0FHEA
R124 | 1 | 100k |  |  |  | SpeakerRevB:R124_RevB | https://www.vishay.com/docs/28758/tnpw_e3.pdf |  | TNPW0805100KFHEA
R125 | 1 | 10 |  |  |  | SpeakerRevB:R125_RevB | https://www.vishay.com/docs/28758/tnpw_e3.pdf |  | TNPW080510R0FHEA
R126 | 1 | 10 |  |  |  | SpeakerRevB:R126_RevB | https://www.vishay.com/docs/28758/tnpw_e3.pdf |  | TNPW080510R0FHEA
R127 | 1 | 5.1k |  |  |  | SpeakerRevB:R127_RevB | https://www.vishay.com/docs/28758/tnpw_e3.pdf |  | TNPW08055K10FHEA
R128 | 1 | 10k |  |  |  | SpeakerRevB:R128_RevB | https://www.vishay.com/docs/28758/tnpw_e3.pdf |  | TNPW080510K0FHEA
R129 | 1 | 10k |  |  |  | SpeakerRevB:R129_RevB | https://www.vishay.com/docs/28758/tnpw_e3.pdf |  | TNPW080510K0FHEA
R130 | 1 | 6.04k |  |  |  | SpeakerRevB:R130_RevB | https://www.vishay.com/docs/28758/tnpw_e3.pdf |  | TNPW08056K04FHEA
R131 | 1 | 200k |  |  |  | SpeakerRevB:R131_RevB | https://www.vishay.com/docs/28758/tnpw_e3.pdf |  | TNPW0805200KBYEA
R132 | 1 | 10k |  |  |  | SpeakerRevB:R132_RevB | https://www.vishay.com/docs/28758/tnpw_e3.pdf |  | TNPW080510K0BYEA
R133 | 1 | 158k |  |  |  | SpeakerRevB:R133_RevB | https://www.vishay.com/docs/28758/tnpw_e3.pdf |  | TNPW0805158KFHEA
R134 | 1 | 10k |  |  |  | SpeakerRevB:R134_RevB | https://www.vishay.com/docs/28758/tnpw_e3.pdf |  | TNPW080510K0FHEA
R135 | 1 | 1k |  |  |  | SpeakerRevB:R135_RevB | https://www.vishay.com/docs/28758/tnpw_e3.pdf |  | TNPW08051K00FHEA
R136 | 1 | 174k |  |  |  | SpeakerRevB:R136_RevB | https://www.vishay.com/docs/28758/tnpw_e3.pdf |  | TNPW0805174KFHEA
R137 | 1 | 10k |  |  |  | SpeakerRevB:R137_RevB | https://www.vishay.com/docs/28758/tnpw_e3.pdf |  | TNPW080510K0FHEA
R138 | 1 | 10k |  |  |  | SpeakerRevB:R138_RevB | https://www.vishay.com/docs/28758/tnpw_e3.pdf |  | TNPW080510K0FHEA
SW1 | 1 | TS-1088-AR02016 |  |  |  | SpeakerRevB:SW1_RevB |  | C720477 | TS-1088-AR02016 | SW-SMD_L3.9-W3.0-P4.45
SW2 | 1 | TS-1088-AR02016 |  |  |  | SpeakerRevB:SW2_RevB |  | C720477 | TS-1088-AR02016 | SW-SMD_L3.9-W3.0-P4.45
TP1 | 1 | Generic Testpoint |  |  |  | SpeakerRevB:TP1_RevB
TP2 | 1 | Generic Testpoint |  |  |  | SpeakerRevB:TP2_RevB
TP3 | 1 | Generic Testpoint |  |  |  | SpeakerRevB:TP3_RevB
TP4 | 1 | Generic Testpoint |  |  |  | SpeakerRevB:TP4_RevB
TP5 | 1 | Generic Testpoint |  |  |  | SpeakerRevB:TP5_RevB
TP6 | 1 | Generic Testpoint |  |  |  | SpeakerRevB:TP6_RevB
TP7 | 1 | Generic Testpoint |  |  |  | SpeakerRevB:TP7_RevB
TP8 | 1 | Generic Testpoint |  |  |  | SpeakerRevB:TP8_RevB
TP9 | 1 | Generic Testpoint |  |  |  | SpeakerRevB:TP9_RevB
TP10 | 1 | Generic Testpoint |  |  |  | SpeakerRevB:TP10_RevB
TP11 | 1 | Generic Testpoint |  |  |  | SpeakerRevB:TP11_RevB
TP12 | 1 | Generic Testpoint |  |  |  | SpeakerRevB:TP12_RevB
TP13 | 1 | Generic Testpoint |  |  |  | SpeakerRevB:TP13_RevB
TP14 | 1 | Generic Testpoint |  |  |  | SpeakerRevB:TP14_RevB
TP15 | 1 | Generic Testpoint |  |  |  | SpeakerRevB:TP15_RevB
TP16 | 1 | Generic Testpoint |  |  |  | SpeakerRevB:TP16_RevB
TP17 | 1 | Generic Testpoint |  |  |  | SpeakerRevB:TP17_RevB
TP18 | 1 | Generic Testpoint |  |  |  | SpeakerRevB:TP18_RevB
TP19 | 1 | Generic Testpoint |  |  |  | SpeakerRevB:TP19_RevB
TP20 | 1 | Generic Testpoint |  |  |  | SpeakerRevB:TP20_RevB
TP21 | 1 | Generic Testpoint |  |  |  | SpeakerRevB:TP21_RevB
TP22 | 1 | Generic Testpoint |  |  |  | SpeakerRevB:TP22_RevB
TP23 | 1 | Generic Testpoint |  |  |  | SpeakerRevB:TP23_RevB
TP25 | 1 | BENCH_FAULT_N |  |  |  | SpeakerRevB:TP25_RevB |  |  | BENCH_FAULT_N
TP26 | 1 | EFUSE_SHDN |  |  |  | SpeakerRevB:TP26_RevB |  |  | TBD
TP27 | 1 | EFUSE_FAULT_N |  |  |  | SpeakerRevB:TP27_RevB |  |  | TBD
U1 | 1 | Ag5800 |  |  |  | SpeakerRevB:U1_RevB | https://www.silvertel.com/images/datasheets/Ag5800-datasheet-%20IEEE802_3bt-Power-over-Ethernet-4-pair-PD.pdf |  | Ag5800 | Module
U2 | 1 | ESP32-S3-WROOM-1U-N16R8 |  |  |  | SpeakerRevB:U2_RevB |  |  | ESP32-S3-WROOM-1U-N16R8
U3 | 1 | W5500 |  |  |  | SpeakerRevB:U3_RevB |  |  | W5500
U4 | 1 | PCM5122PWR |  |  |  | SpeakerRevB:U4_RevB |  | C962071 | PCM5122PWR | TSSOP-28_L9.8-W6.6-P0.65-BL
U5 | 1 | TPA3116D2 |  |  |  | SpeakerRevB:U5_RevB | https://www.ti.com/lit/ds/symlink/tpa3116d2.pdf |  | TPA3116D2DADR
U6 | 1 | LMR33630AQRNXRQ1 |  |  |  | SpeakerRevB:U6_RevB |  |  | LMR33630AQRNXRQ1 | VQFN-HR (RNX) | 12, RNX0012B, 3 x 2 x 0.85 mm
U7 | 1 | TPS62132RGTR |  |  |  | SpeakerRevB:U7_RevB |  |  | TPS62132RGTR | 16-VQFN (3x3)
U8 | 1 | RT9013-33GB |  |  |  | SpeakerRevB:U8_RevB |  |  | RT9013-33GB
U9 | 1 | LM5050-2 |  |  |  | SpeakerRevB:U9_RevB | https://www.ti.com/lit/gpn/LM5050-2 |  | LM5050MK-2/NOPB | TSOT-23-6
U10 | 1 | LM5050-2 |  |  |  | SpeakerRevB:U10_RevB | https://www.ti.com/lit/gpn/LM5050-2 |  | LM5050MK-2/NOPB | TSOT-23-6
U11 | 1 | PCAL6416APW |  |  |  | SpeakerRevB:U11_RevB |  |  | PCAL6416APW | TSSOP-24_4.4x7.8mm_P0.65mm
U12 | 1 | PC817X2NSZ9F |  |  |  | SpeakerRevB:U12_RevB |  | C390734 | PC817X2NSZ9F | DIP-4_L6.4-W4.6-P2.54-LS7.6-BL
U13 | 1 | PC817X2NSZ9F |  |  |  | SpeakerRevB:U13_RevB |  | C390734 | PC817X2NSZ9F | DIP-4_L6.4-W4.6-P2.54-LS7.6-BL
U14 | 1 | PC817X2NSZ9F |  |  |  | SpeakerRevB:U14_RevB |  | C390734 | PC817X2NSZ9F | DIP-4_L6.4-W4.6-P2.54-LS7.6-BL
U15 | 1 | LTC4365HTS8#TRPBF |  |  |  | SpeakerRevB:U15_RevB |  |  | LTC4365HTS8#TRPBF
U16 | 1 | TPS26630RGER |  |  |  | SpeakerRevB:U16_RevB |  |  | TPS26630RGER
X2 | 1 | 25MHz |  |  |  | SpeakerRevB:X2_RevB |  |  | ASE-25.000MHZ-LC-T

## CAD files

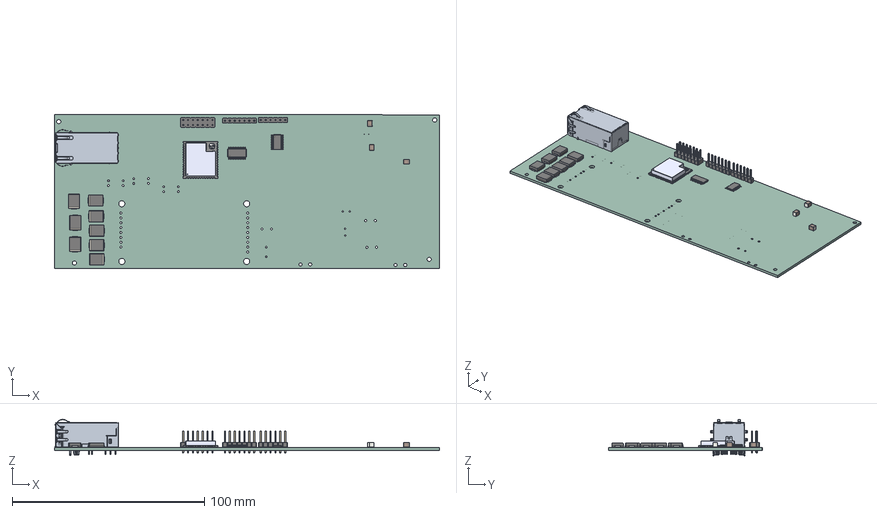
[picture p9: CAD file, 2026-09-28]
hardware/PoE-Speaker/RevF/Manufacturing/Mechanical/PoE-Speaker-RevE-assembly.step
200.4 x 80.1 x 18.9 mm
ESP32-S3-WROOM-1U-N16R8
D_SMC x 8
PinHeader_1x06_P254mm_Vertical x 2
PinHeader_2x07_P254mm_Vertical
TSSOP-24_4.4x7.8mm_P0.65mm
2250506-1_PART1
2250506-1_PART2
2250506-1_PART3
2250506-1_PART4
TSSOP-28_4.4x9.7mm_P0.65mm
PinHeader_1x07_P254mm_Vertical
C_1210_3225Metric x 3
PoE-Speaker-RevE_PCB

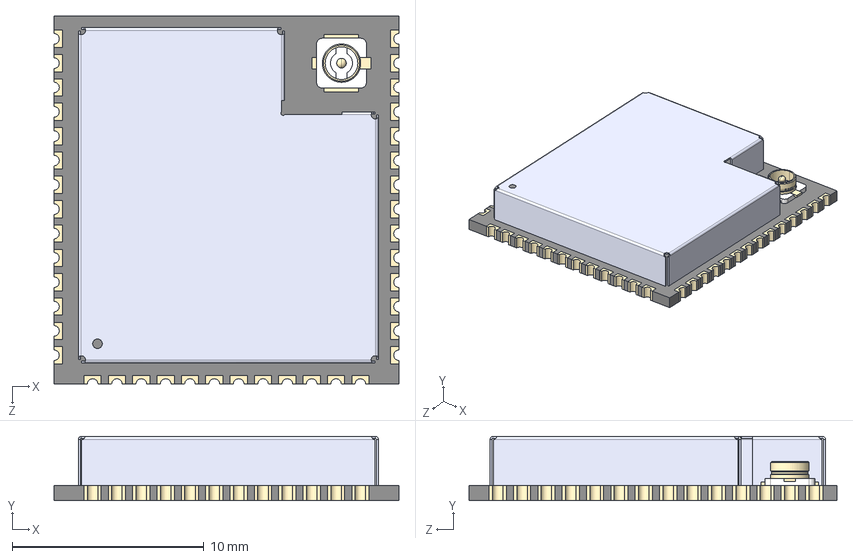
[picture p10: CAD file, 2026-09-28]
hardware/PoE-Speaker/RevF/Manufacturing/Mechanical/ESP32-S3-WROOM-1U-N16R8--3DModel-STEP-56544.STEP
18.0 x 3.35 x 19.2 mm

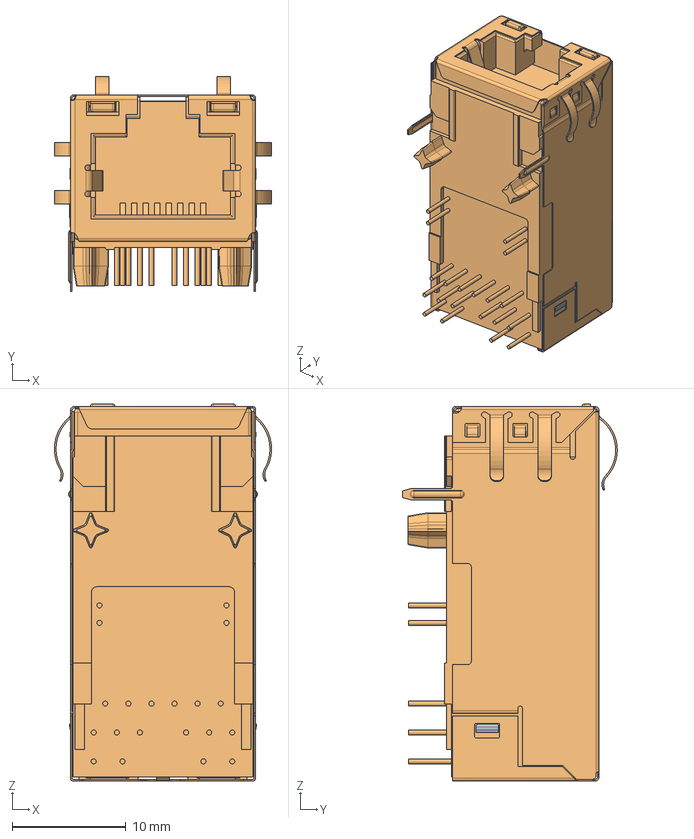
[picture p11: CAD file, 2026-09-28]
hardware/PoE-Speaker/RevF/Manufacturing/Mechanical/2250506-1.stp
19.1 x 18.9 x 33.2 mm
2250506-1_PART1
2250506-1_PART2
2250506-1_PART3
2250506-1_PART4

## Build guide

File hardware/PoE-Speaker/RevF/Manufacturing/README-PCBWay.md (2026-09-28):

# PoE-Speaker RevE — PCBWay Manufacturing Package

Use this package for PCB fabrication and PCBA assembly. It intentionally excludes historical KiCad checkpoints and development files.

## Fabrication
- Upload every file in `Gerbers/` to PCBWay.
- The package contains four copper layers, solder mask, paste, silkscreen, Edge.Cuts, the Gerber job file, and separate PTH/NPTH drill files.

## Assembly
- Use `Assembly/PoE-Speaker-RevE.csv` as the BOM.
- Use `Assembly/PoE-Speaker-RevE-all.pos` as the pick-and-place/CPL file.
- TP25, TP26, and TP27 are bare SMD test-point pads and are not placement components.

## Mechanical/build
- `Mechanical/PoE-Speaker-RevE-assembly.step` is the final assembly STEP reference.
- U5, TPA3116D2DADR, requires an external top-side heatsink. See the PDF in `Notes/`.

## Validation
- Fresh KiCad PCB DRC: 0 violations, 0 unconnected pads, 0 footprint errors.
- Fresh KiCad ERC: 0 errors, 0 warnings.
- Board: 4 layers, approximately 200.40 x 80.07 mm, 1.58468 mm nominal CAD thickness.
- Ethernet final geometry: 0.2764 mm width / 0.20 mm pair gap.

See `MANIFEST.json` for file sizes and SHA-256 hashes.

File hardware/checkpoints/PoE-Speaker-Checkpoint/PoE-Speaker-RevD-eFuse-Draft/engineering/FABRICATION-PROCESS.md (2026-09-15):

# Provisional fabrication process — not a production release

Reviewed 2026-09-12. The layout retains a 0.20 mm track/clearance default and 0.30 mm ordinary drill minimum. A scoped rule permits the existing grounded thermal vias in U2 and U16: 12 and 9 holes respectively, 0.20 mm drill, with 0.60 mm and 0.50 mm copper diameters. No hole geometry was changed and no DRC category was disabled.

JLCPCB is a capability reference, not a selected supplier or an order. Its rigid-board capability table lists 0.20 mm as a preferred minimum via drill. These thermal vias must be identified to CAM as vias rather than component insertion holes. Source: https://jlcpcb.com/capabilities/pcb-capabilities

Procurement must specify and confirm the treatment of exposed-pad vias, preferably filled and copper capped where they intersect solderable lands, plus stencil apertures, finish, stackup and copper weights. Simple open holes may wick solder and compromise the thermal joint. The present drill rule does not approve the assembly process, solder volume or thermal performance. Do not release fabrication until those requirements are included in the quote and accepted.

The U16 land pattern includes a 2.7 mm exposed pad and nine thermal vias; TI's RGE0024H drawing shows a typical 0.20 mm thermal drill. U2 thermal lands remain as supplied in the KiCad module footprint. Component sources:

- https://www.ti.com/lit/ds/symlink/tps2663.pdf
- https://www.espressif.com/sites/default/files/documentation/esp32-s3-wroom-1_wroom-1u_datasheet_en.pdf

Remaining release work includes power/ground thermal copper, switching loops, Ethernet return paths and impedance, fault/startup review, exact order codes, five schematic ERC findings, and mechanical fit. A clean DRC with this profile is a geometry milestone only.

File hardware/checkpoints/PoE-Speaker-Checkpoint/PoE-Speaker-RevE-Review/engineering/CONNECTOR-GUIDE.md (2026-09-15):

# J4, J5 and J6 connector guide

Pin numbers are KiCad pad numbers, not left-to-right positions in a rotated board view. Locate pad 1 before wiring.

## J4 — Future microphone-ring interface

PDM x4, clock, I2C, spare GPIO, 3.3 V and grounds

| Pin | Signal |
| --- | --- |
| 1 | 3V3 |
| 2 | GND |
| 3 | PDM_CLK |
| 4 | GND |
| 5 | PDM_DATA0_CONN |
| 6 | GND |
| 7 | PDM_DATA1_CONN |
| 8 | GND |
| 9 | PDM_DATA2_CONN |
| 10 | GND |
| 11 | PDM_DATA3_CONN |
| 12 | I2C_SDA |
| 13 | I2C_SCL |
| 14 | RING_GPIO_SPARE |

## J5 — ESP32 serial programming and debug

UART0 TX/RX, BOOT, EN, GND, 3V3

| Pin | Signal |
| --- | --- |
| 1 | 3V3 |
| 2 | GND |
| 3 | UART0_TX |
| 4 | ESP_EN |
| 5 | UART0_RX |
| 6 | BOOT_GPIO0 |

## J6 — I2C and GPIO expansion

3V3, GND, SDA, SCL and two PCAL GPIO

| Pin | Signal |
| --- | --- |
| 1 | 3V3 |
| 2 | GND |
| 3 | I2C_SDA |
| 4 | I2C_SCL |
| 5 | EXP_GPIO0 |
| 6 | EXP_GPIO1 |

J4 is reserved for the future ring. Its header and signal names do not establish a completed eight-microphone capture system. Ring capture hardware, interface and firmware remain to be designed.

J5 carries 3.3 V logic-level UART signals. It is not a USB connector. J6 exposes two GPIO-expander signals alongside the shared I2C bus.

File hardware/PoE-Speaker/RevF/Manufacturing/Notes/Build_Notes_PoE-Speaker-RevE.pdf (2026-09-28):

PoE-Speaker-RevE | Manufacturing Release

# PoE Speaker Rev E

## Final Manufacturing & Build Notes

Document | Manufacturing / Assembly Notes
Design | PoE-Speaker-RevE
PCB CAD | KiCad
Release | Final Manufacturing Package
PCB Type | 4-Layer Controlled-Impedance PCB
Fabrication Tar- get | JLCPCB / Compatible PCB Manufacturer

### 1. PCB Fabrication

The PCB shall be manufactured using the final fabrication data contained in this release package.

- Layer count: 4 layers
- Final controlled-impedance stack-up: JLC04161H-7628A
- Ethernet controlled impedance: 100 Ω differential
- Ethernet differential trace width: 0.2764 mm
- Ethernet differential pair spacing: 0.20 mm
- Outer copper: 1 oz
- Inner copper: 0.5 oz

The Gerber and drill files supplied in this package shall be used as the definitive PCB fabrication outputs.

### 2. Controlled-Impedance Stack-Up

The final PCB stack-up is based on the JLCPCB JLC04161H-7628A controlled-impedance construction.

Layer / Material | Type | Thickness
F.Cu | Copper | 0.0350 mm
FR4 7628 | Prepreg | 0.2180 mm
FR4 1080 | Prepreg | 0.0764 mm
In1.Cu | Copper | 0.0152 mm
FR4 | Core | 0.8650 mm
In2.Cu | Copper | 0.0152 mm
FR4 1080 | Prepreg | 0.0764 mm
FR4 7628 | Prepreg | 0.2180 mm
B.Cu | Copper | 0.0350 mm
Final Manufacturing Package | Page 1 of 4

CONTROLLED-IMPEDANCE REQUIREMENT
The Ethernet differential pairs are designed for a nominal 100 Ω differential impedance. The final routing geometry is:
- Trace width: 0.2764 mm
- Pair spacing: 0.20 mm
- Signal layer: L1 / F.Cu
- Reference layer: L2 / In1.Cu

This geometry is associated with the JLC04161H-7628A stack-up specified above.

### 3. Assembly Data

Use the assembly data included in this final manufacturing package for component sourcing and placement.

- Use the supplied Bill of Materials (BOM) for component identification and sourcing.
- Manufacturer part numbers contained in the BOM shall be used where specified.
- Use the supplied CPL / Pick-and-Place file for automated component placement.
- Component reference designators and orientations shall follow the final KiCad PCB project.
- The supplied STEP model may be used for mechanical integration and assembly reference.

### 4. Amplifier Thermal Requirement

The audio power amplifier requires appropriate thermal management in the final assembly.

Reference | U5
Device | TPA3116D2DADR
Thermal | Require-
ment | External top-side heatsink required in final assembly

The final mechanical assembly shall provide suitable heatsink mounting and adequate thermal clearance around the amplifier.

### 5. Design Verification

The final PCB design was checked after completion of the routing and controlled-impedance stack-up configuration.

- Final PCB Design Rules Check (DRC) performed.
- Final DRC result: 0 violations.
- Final DRC result: 0 unconnected items.
- Final schematic Electrical Rules Check (ERC) performed before release.

Fresh DRC/ERC verification results are included with the final manufacturing package.

### 6. Power Routing

The final power distribution routing was reviewed before release.

High-current 24 V paths were routed using widened traces and/or large copper areas where required.

The reviewed power distribution includes:

- 24V_POE
- 24V_BENCH_PROTECTED
- 24V_OR
- 24V_AMP
- 3.3 V distribution

Narrow high-current sections in the main amplifier supply path were reviewed during final PCB cleanup.

### 7. Ethernet Routing

The Ethernet interface routing was reviewed and updated before the manufacturing release.

The Ethernet TX and RX differential pairs use the controlled geometry specified in this document.

Both conductors of each differential pair shall maintain consistent routing geometry wherever practical.

The final controlled geometry is:

Parameter | Final Value
Differential impedance | 100 Ω
Trace width | 0.2764 mm
Pair spacing | 0.20 mm
Signal layer | F.Cu / L1
Reference layer | In1.Cu / L2

### 8. Manufacturing Package Contents

The final manufacturing release package contains the following deliverables:

- Final KiCad project and source files
- Gerber fabrication files
- PTH drill file
- NPTH drill file
- Gerber job file
- Bill of Materials (BOM)
- CPL / Pick-and-Place file
- STEP mechanical model
- Final DRC verification result
- Final ERC verification result
- Manufacturing and build notes

### 9. Production Release

IMPORTANT — SOURCE OF TRUTH

The KiCad project and manufacturing outputs contained in this final release package constitute the definitive manufacturing version of the PoE-Speaker-RevE PCB.
Earlier project ZIP files, Gerbers, drill files, BOM files, CPL files, STEP exports, or other manufacturing outputs shall not be used for production.
Project: PoE-Speaker-RevE | Release: Final Manufacturing Package

END OF MANUFACTURING / BUILD NOTES

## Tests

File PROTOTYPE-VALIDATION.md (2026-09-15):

# Prototype Validation Plan

This document defines the minimum validation sequence for the first fabricated prototype. Record actual measurements, equipment used, board revision, source commit/hash and ambient conditions. Do not replace measurements with expected values after the board exists.

## 1. Before power

- Confirm board revision and source commit/hash.
- Inspect orientation and polarity of connectors, diodes, electrolytics, ICs and polarized passives.
- Inspect for solder bridges, opens, tombstoning and questionable via-in-pad joints.
- Verify heatsink and mechanical clearances.
- Measure resistance from each primary rail to ground and record the result.
- Confirm current-limit and emergency power-removal method before energizing.

## 2. Current-limited bench bring-up

Begin with an isolated, current-limited bench supply rather than PoE.

Record:
- Input voltage and current at startup.
- 3.3 V rail.
- Other regulated rails and amplifier supply rails.
- ESP32 boot behavior and serial output.
- Regulator, amplifier and protection-device temperatures after initial idle operation.

Stop immediately for unexpected current draw, unstable rails, smoke, odor or rapid thermal rise.

## 3. Digital subsystem

Verify:
- ESP32 reliable boot/reset behavior.
- Serial diagnostic output.
- W5500 SPI communication.
- Ethernet PHY/link indication.
- DHCP and static-IP operation if supported by the test firmware.
- Sustained network traffic without unexplained packet loss or link renegotiation.

Record test duration, traffic method and any error counters available.

## 4. Audio path

Start with low output power.

Verify:
- DAC initialization.
- Controlled test-tone generation.
- Amplifier mute and enable behavior.
- Correct channel/output polarity.
- Idle current and idle noise.
- Output waveform into a known dummy load before attaching a speaker.

Characterize, as practical:
- Output power into 4 ohms.
- Supply current versus output level.
- Clipping threshold.
- Frequency response.
- Noise and distortion using available equipment.

The 30 W into 4 ohms target is not considered validated until measured.

## 5. Thermal test

Record ambient temperature and temperatures at key components at approximately:
- idle;
- moderate output;
- near intended sustained output;
- 1 minute;
- 5 minutes;
- 15 minutes;
- 30 minutes where safe.

Priority components include the amplifier, regulators, PoE/power conversion components, protection devices, high-current connectors and any visibly stressed copper/via regions.

## 6. PoE test

Only after bench-power bring-up succeeds:
- Verify expected PoE classification/negotiation behavior where applicable.
- Verify startup without repeated negotiation/reset cycles.
- Compare operating rails and temperatures with bench-power operation.
- Exercise Ethernet and audio simultaneously from PoE.
- Record switch/PSE telemetry if available.

## 7. Protection and fault behavior

Perform only tests that can be conducted safely with appropriate current limiting and sacrificial protection.

Review or test as practical:
- input overcurrent behavior;
- eFuse/protection shutdown and recovery;
- short-circuit response on accessible protected rails;
- amplifier fault/mute behavior;
- brownout / power interruption recovery;
- repeated startup behavior.

Do not intentionally exceed component absolute maximum ratings merely to prove a theoretical failure mode.

## 8. Pass / fail handling

Every unexpected result becomes a GitHub issue with:
- board revision and source hash;
- test step;
- expected result;
- observed result;
- measurement and test equipment;
- photos/screenshots/logs when useful;
- suspected cause, clearly labeled as hypothesis if unproven.

Prototype validation is complete only when all required tests have recorded results and unresolved failures are either corrected or explicitly accepted with rationale.

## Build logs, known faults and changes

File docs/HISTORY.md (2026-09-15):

# Project history

## Earlier board render

The image below is an **earlier development render** of the PoE speaker main board. It is preserved for project history and should **not** be treated as the current Rev E layout, placement, routing, mechanical state, or fabrication reference.

Earlier development board render

For the current editable design, use the active KiCad source under [`hardware/PoE-Speaker/RevE/`](../hardware/PoE-Speaker/RevE/).

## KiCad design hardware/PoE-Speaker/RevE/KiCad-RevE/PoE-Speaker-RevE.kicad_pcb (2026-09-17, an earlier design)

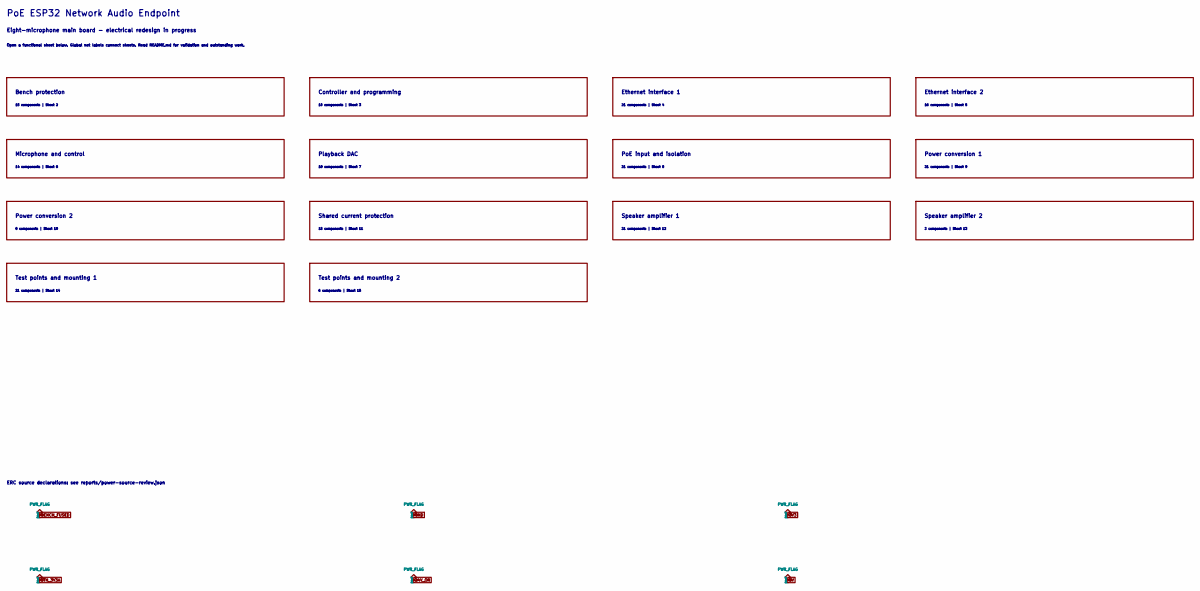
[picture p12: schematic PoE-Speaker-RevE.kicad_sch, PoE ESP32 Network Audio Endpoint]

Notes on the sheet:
PoE ESP32 Network Audio Endpoint
Eight-microphone main board - electrical redesign in progress
Open a functional sheet below. Global net labels connect sheets. Read README.md for validation and outstanding work.
Bench protection
15 components | Sheet 2
Controller and programming
10 components | Sheet 3
Ethernet interface 1
21 components | Sheet 4
Ethernet interface 2
16 components | Sheet 5
Microphone and control
14 components | Sheet 6
Playback DAC
18 components | Sheet 7
PoE input and isolation
21 components | Sheet 8
Power conversion 1
21 components | Sheet 9
Power conversion 2
8 components | Sheet 10
Shared current protection
15 components | Sheet 11
Speaker amplifier 1
21 components | Sheet 12
Speaker amplifier 2
2 components | Sheet 13
Test points and mounting 1
21 components | Sheet 14
Test points and mounting 2
6 components | Sheet 15
ERC source declarations: see reports/power-source-review.json

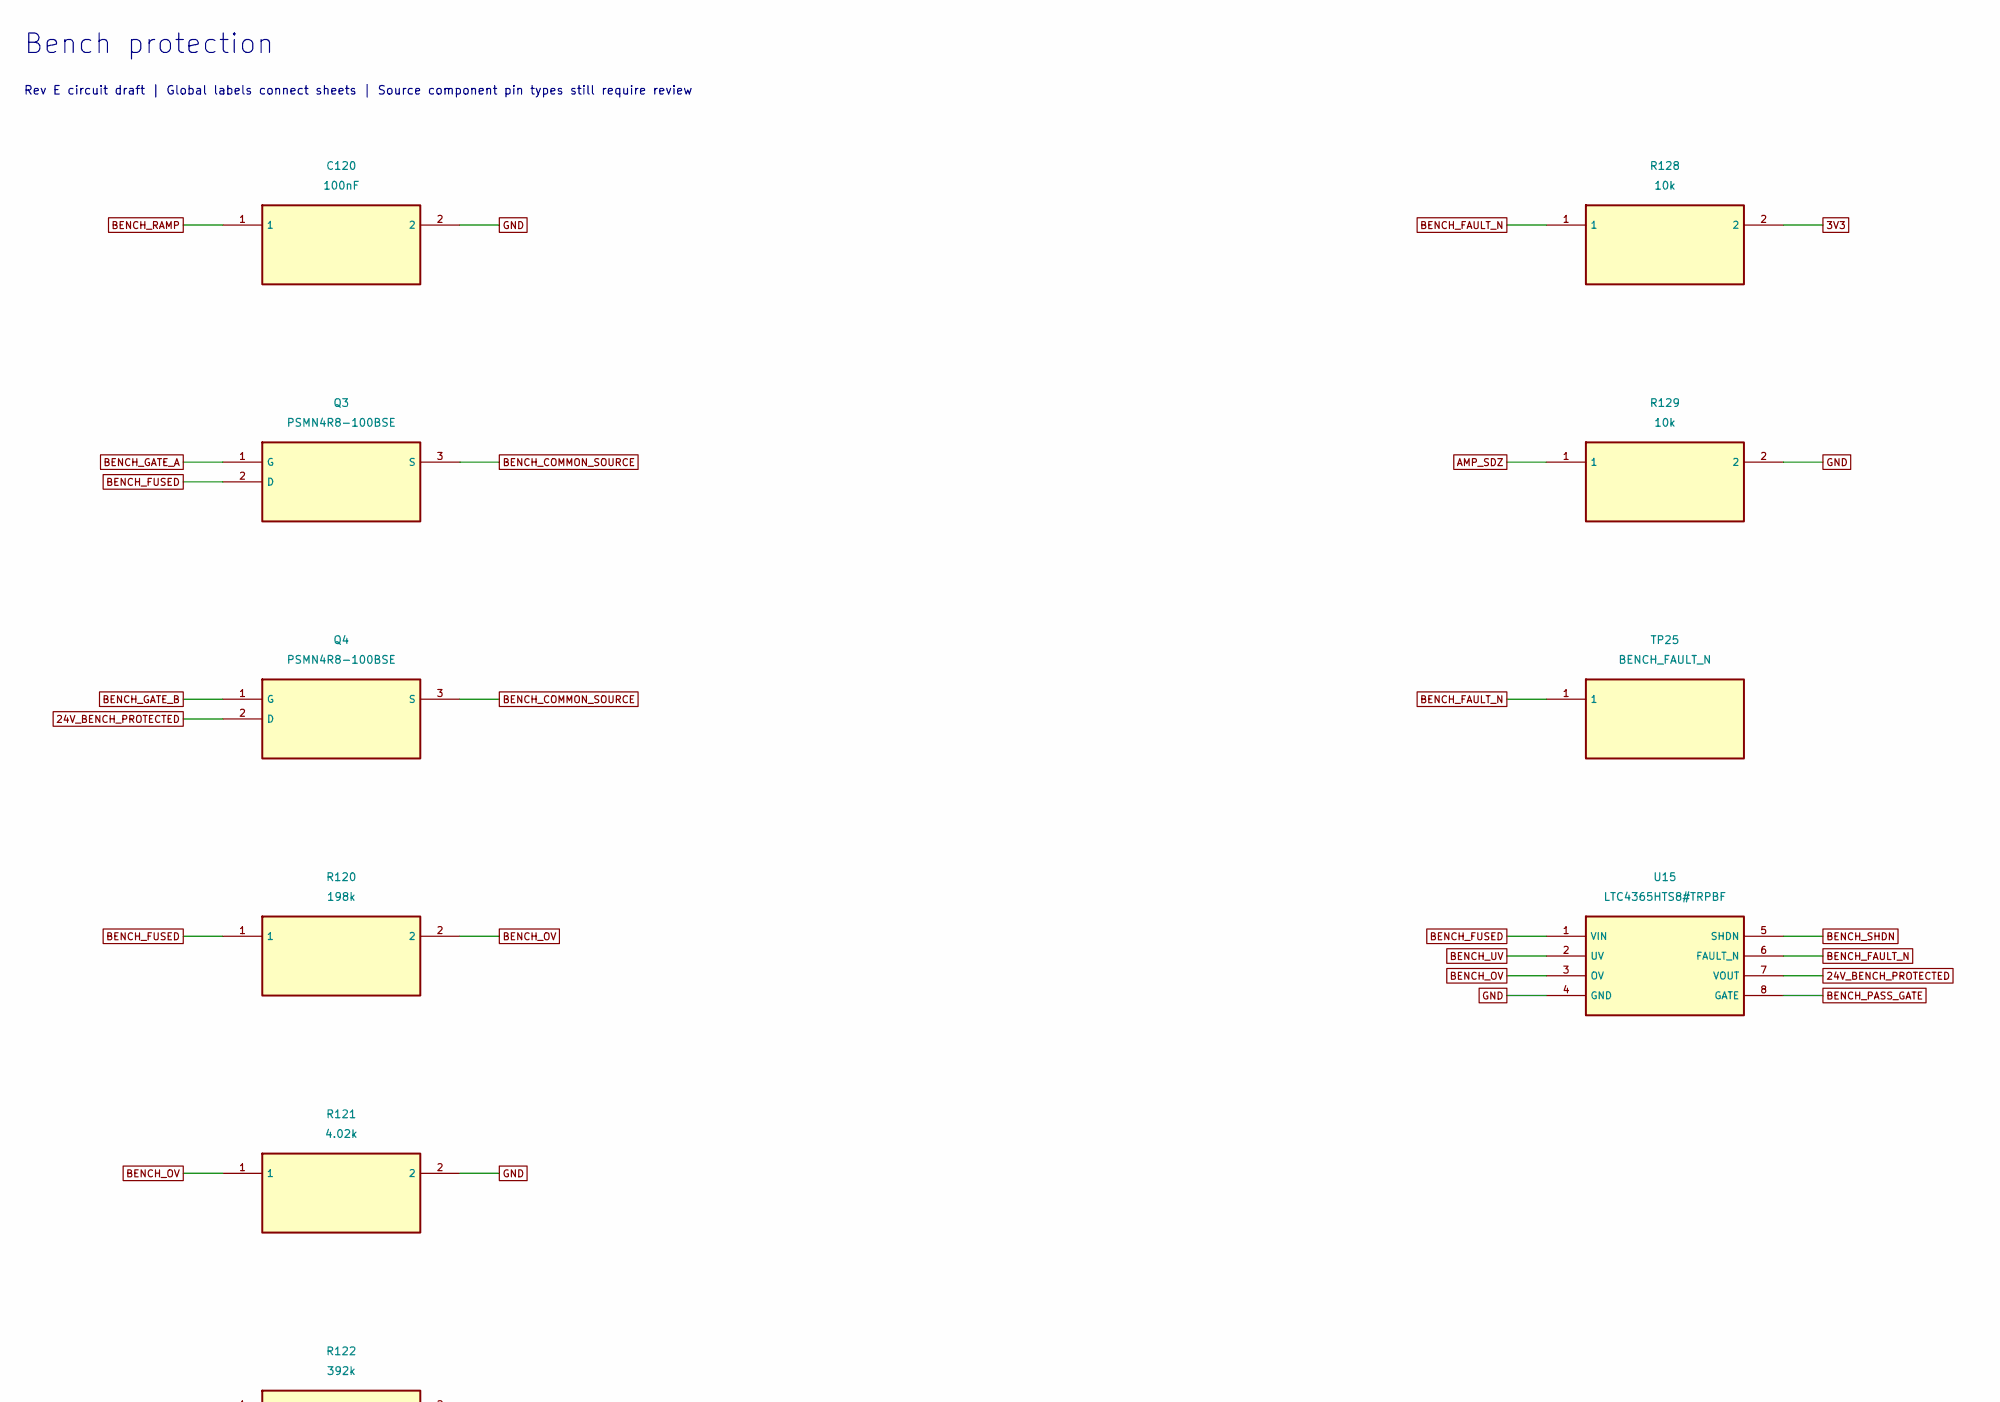
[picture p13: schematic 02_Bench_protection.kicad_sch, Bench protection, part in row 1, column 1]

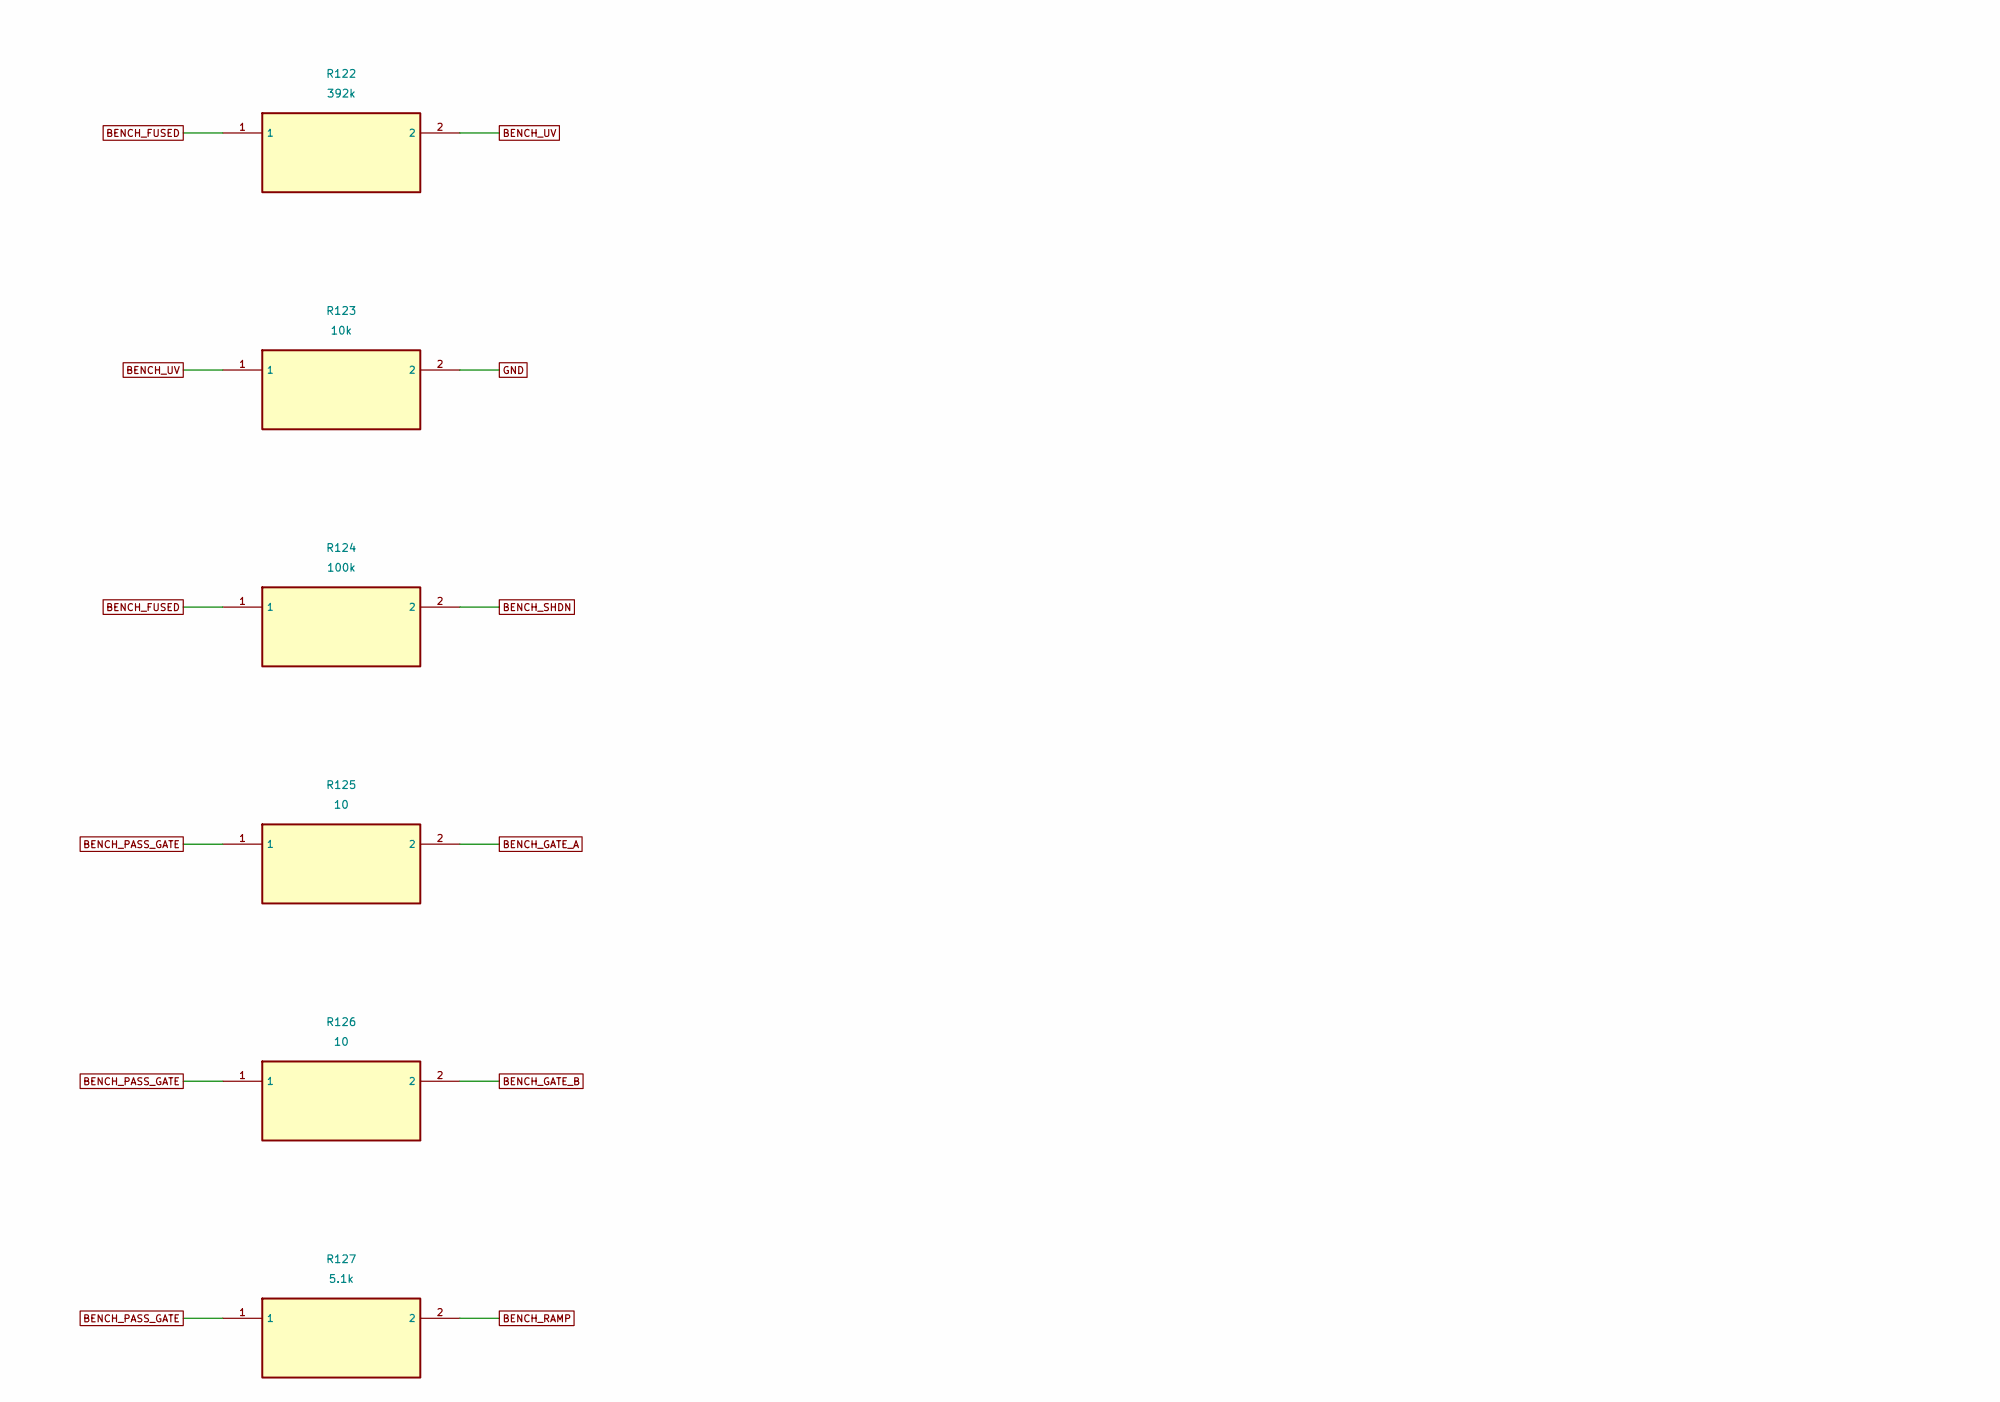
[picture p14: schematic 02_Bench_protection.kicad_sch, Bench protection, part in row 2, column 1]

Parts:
C120: 100nF; C_1210_3225Metric; Voltage rating 100 V; Tolerance 5%; Manufacturer Part Number C1210C104J1GACTU
Q3: PSMN4R8-100BSE; Q3_RevB; Manufacturer Part Number PSMN4R8-100BSE
Q4: PSMN4R8-100BSE; Q4_RevB; Manufacturer Part Number PSMN4R8-100BSE
R120: 198k; R120_RevB; Tolerance 0.1%; Power rating 0.125 W conservative; Manufacturer Part Number TNPW0805198KBYEA
R121: 4.02k; R121_RevB; Tolerance 0.1%; Power rating 0.125 W conservative; Manufacturer Part Number TNPW08054K02BYEA
R122: 392k; R122_RevB; Tolerance 1%; Power rating 0.125 W conservative; Manufacturer Part Number TNPW0805392KFHEA
R123: 10k; R123_RevB; Tolerance 1%; Power rating 0.125 W conservative; Manufacturer Part Number TNPW080510K0FHEA
R124: 100k; R124_RevB; Tolerance 1%; Power rating 0.125 W conservative; Manufacturer Part Number TNPW0805100KFHEA
R125: 10; R125_RevB; Tolerance 1%; Power rating 0.125 W conservative; Manufacturer Part Number TNPW080510R0FHEA
R126: 10; R126_RevB; Tolerance 1%; Power rating 0.125 W conservative; Manufacturer Part Number TNPW080510R0FHEA
R127: 5.1k; R127_RevB; Tolerance 1%; Power rating 0.125 W conservative; Manufacturer Part Number TNPW08055K10FHEA
R128: 10k; R128_RevB; Tolerance 1%; Power rating 0.125 W conservative; Manufacturer Part Number TNPW080510K0FHEA
R129: 10k; R129_RevB; Tolerance 1%; Power rating 0.125 W conservative; Manufacturer Part Number TNPW080510K0FHEA
TP25: BENCH_FAULT_N; TP25_RevB; Manufacturer Part Number BENCH_FAULT_N
U15: LTC4365HTS8#TRPBF; U15_RevB; Manufacturer Part Number LTC4365HTS8#TRPBF

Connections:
3V3: R128.2; also elsewhere on the board
24V_BENCH_PROTECTED: Q4.2 (D), U15.7 (VOUT); also elsewhere on the board
AMP_SDZ: R129.1; also elsewhere on the board
BENCH_COMMON_SOURCE: Q3.3 (S), Q4.3 (S)
BENCH_FAULT_N: R128.1, TP25.1, U15.6 (FAULT_N)
BENCH_FUSED: Q3.2 (D), R120.1, R122.1, R124.1, U15.1 (VIN); also elsewhere on the board
BENCH_GATE_A: Q3.1 (G), R125.2
BENCH_GATE_B: Q4.1 (G), R126.2
BENCH_OV: R120.2, R121.1, U15.3 (OV)
BENCH_PASS_GATE: R125.1, R126.1, R127.1, U15.8 (GATE)
BENCH_RAMP: C120.1, R127.2
BENCH_SHDN: R124.2, U15.5 (SHDN)
BENCH_UV: R122.2, R123.1, U15.2 (UV)
GND: C120.2, R121.2, R123.2, R129.2, U15.4 (GND); also elsewhere on the board

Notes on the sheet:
Bench protection
Rev E circuit draft | Global labels connect sheets | Source component pin types still require review

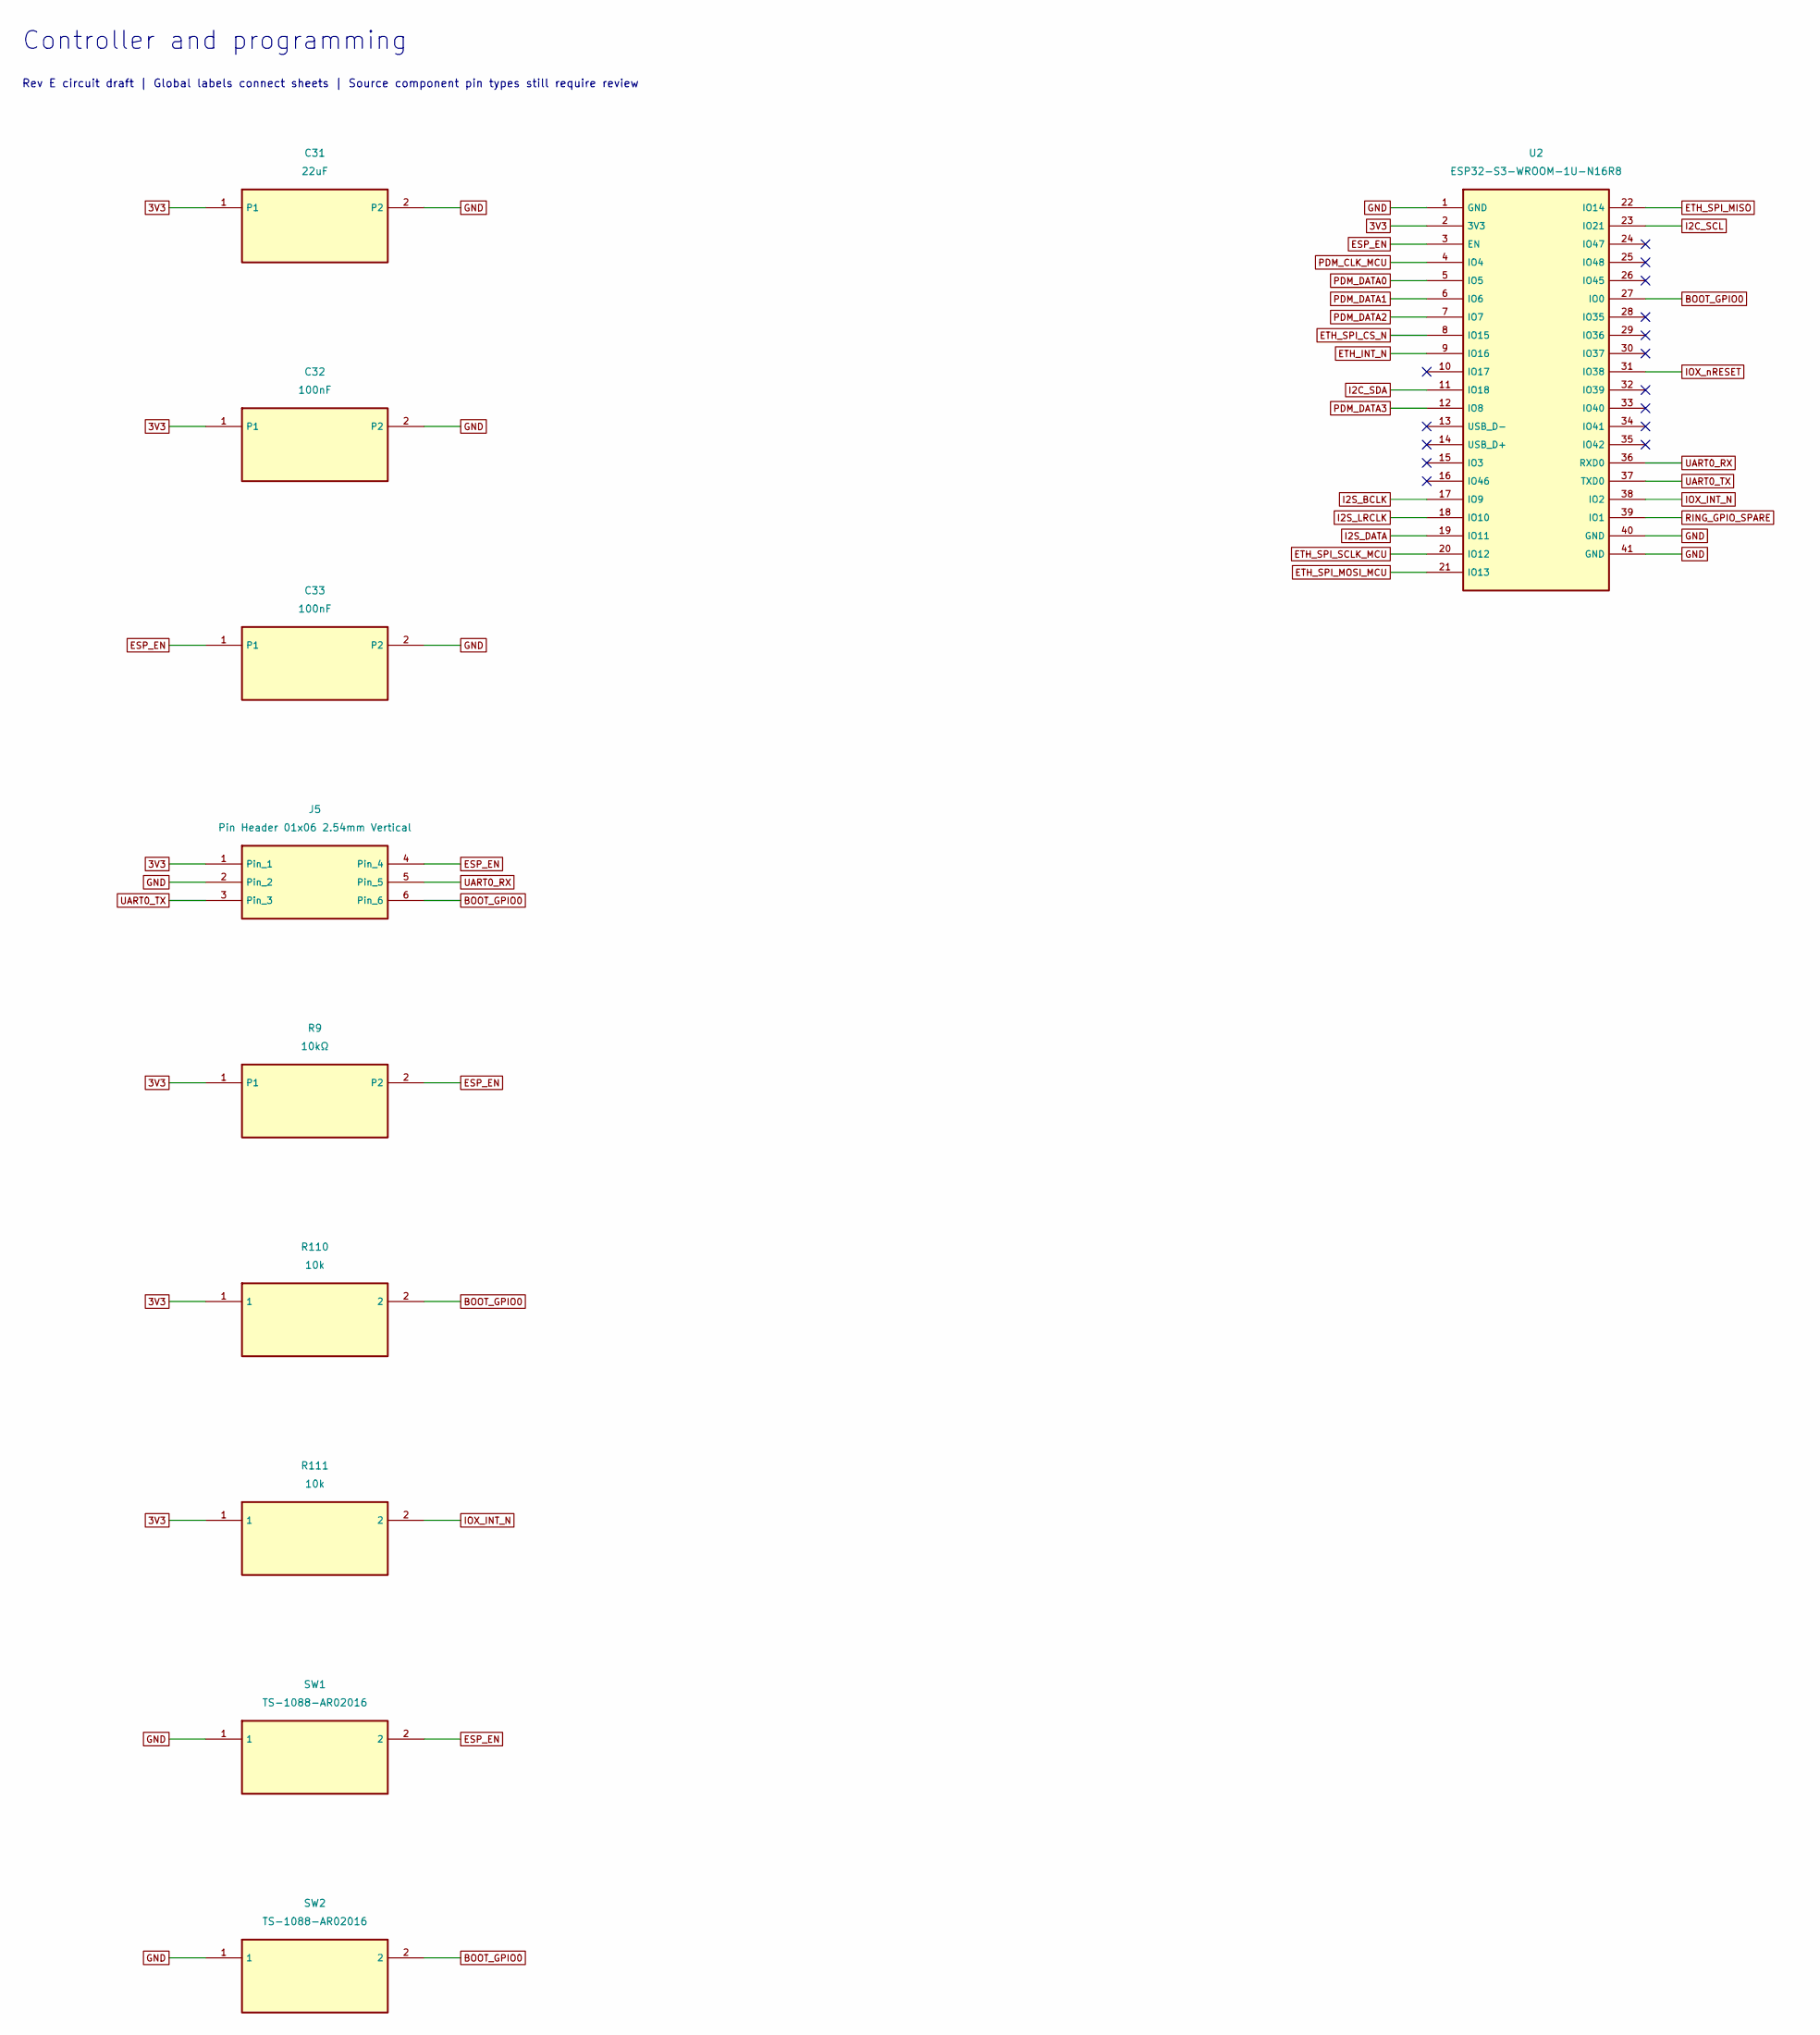
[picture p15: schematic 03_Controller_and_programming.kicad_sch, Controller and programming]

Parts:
C31: 22uF; C31_RevB; Voltage Rating 16 V; Tolerance 20%; Manufacturer Part Number GRM21BR61C226ME44L
C32: 100nF; C32_RevB; Voltage Rating 50 V; Tolerance 10%; Manufacturer Part Number C0603C104K5RACTU
C33: 100nF; C33_RevB; Voltage Rating 50 V; Tolerance 10%; Manufacturer Part Number C0603C104K5RACTU
J5: Pin Header 01x06 2.54mm Vertical; J5_RevB; Part Type Connector
R9: 10kΩ; R9_RevB; Tolerance 1%; Power rating 0.10 W conservative; Part Type Resistor
R110: 10k; R110_RevB; Tolerance 1%; Power rating 0.10 W conservative; Manufacturer Part Number TNPW060310K0FHEA
R111: 10k; R111_RevB; Tolerance 1%; Power rating 0.10 W conservative; Manufacturer Part Number TNPW060310K0FHEA
SW1: TS-1088-AR02016; SW1_RevB; Manufacturer Part Number TS-1088-AR02016; JLCPCB Part Class Extended Part
SW2: TS-1088-AR02016; SW2_RevB; Manufacturer Part Number TS-1088-AR02016; JLCPCB Part Class Extended Part
U2: ESP32-S3-WROOM-1U-N16R8; U2_RevB; Manufacturer Part Number ESP32-S3-WROOM-1U-N16R8

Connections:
3V3: C31.1, C32.1, J5.1, R9.1, R110.1, R111.1, U2.2 (3V3); also elsewhere on the board
BOOT_GPIO0: J5.6, R110.2, SW2.2, U2.27 (IO0)
ESP_EN: C33.1, J5.4, R9.2, SW1.2, U2.3 (EN)
ETH_INT_N: U2.9 (IO16); also elsewhere on the board
ETH_SPI_CS_N: U2.8 (IO15); also elsewhere on the board
ETH_SPI_MISO: U2.22 (IO14); also elsewhere on the board
ETH_SPI_MOSI_MCU: U2.21 (IO13); also elsewhere on the board
ETH_SPI_SCLK_MCU: U2.20 (IO12); also elsewhere on the board
GND: C31.2, C32.2, C33.2, J5.2, SW1.1, SW2.1, U2.1 (GND), U2.40 (GND), U2.41 (GND); also elsewhere on the board
I2C_SCL: U2.23 (IO21); also elsewhere on the board
I2C_SDA: U2.11 (IO18); also elsewhere on the board
I2S_BCLK: U2.17 (IO9); also elsewhere on the board
I2S_DATA: U2.19 (IO11); also elsewhere on the board
I2S_LRCLK: U2.18 (IO10); also elsewhere on the board
IOX_INT_N: R111.2, U2.38 (IO2); also elsewhere on the board
IOX_nRESET: U2.31 (IO38); also elsewhere on the board
PDM_CLK_MCU: U2.4 (IO4); also elsewhere on the board
PDM_DATA0: U2.5 (IO5); also elsewhere on the board
PDM_DATA1: U2.6 (IO6); also elsewhere on the board
PDM_DATA2: U2.7 (IO7); also elsewhere on the board
PDM_DATA3: U2.12 (IO8); also elsewhere on the board
RING_GPIO_SPARE: U2.39 (IO1); also elsewhere on the board
UART0_RX: J5.5, U2.36 (RXD0)
UART0_TX: J5.3, U2.37 (TXD0)

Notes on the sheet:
Controller and programming
Rev E circuit draft | Global labels connect sheets | Source component pin types still require review

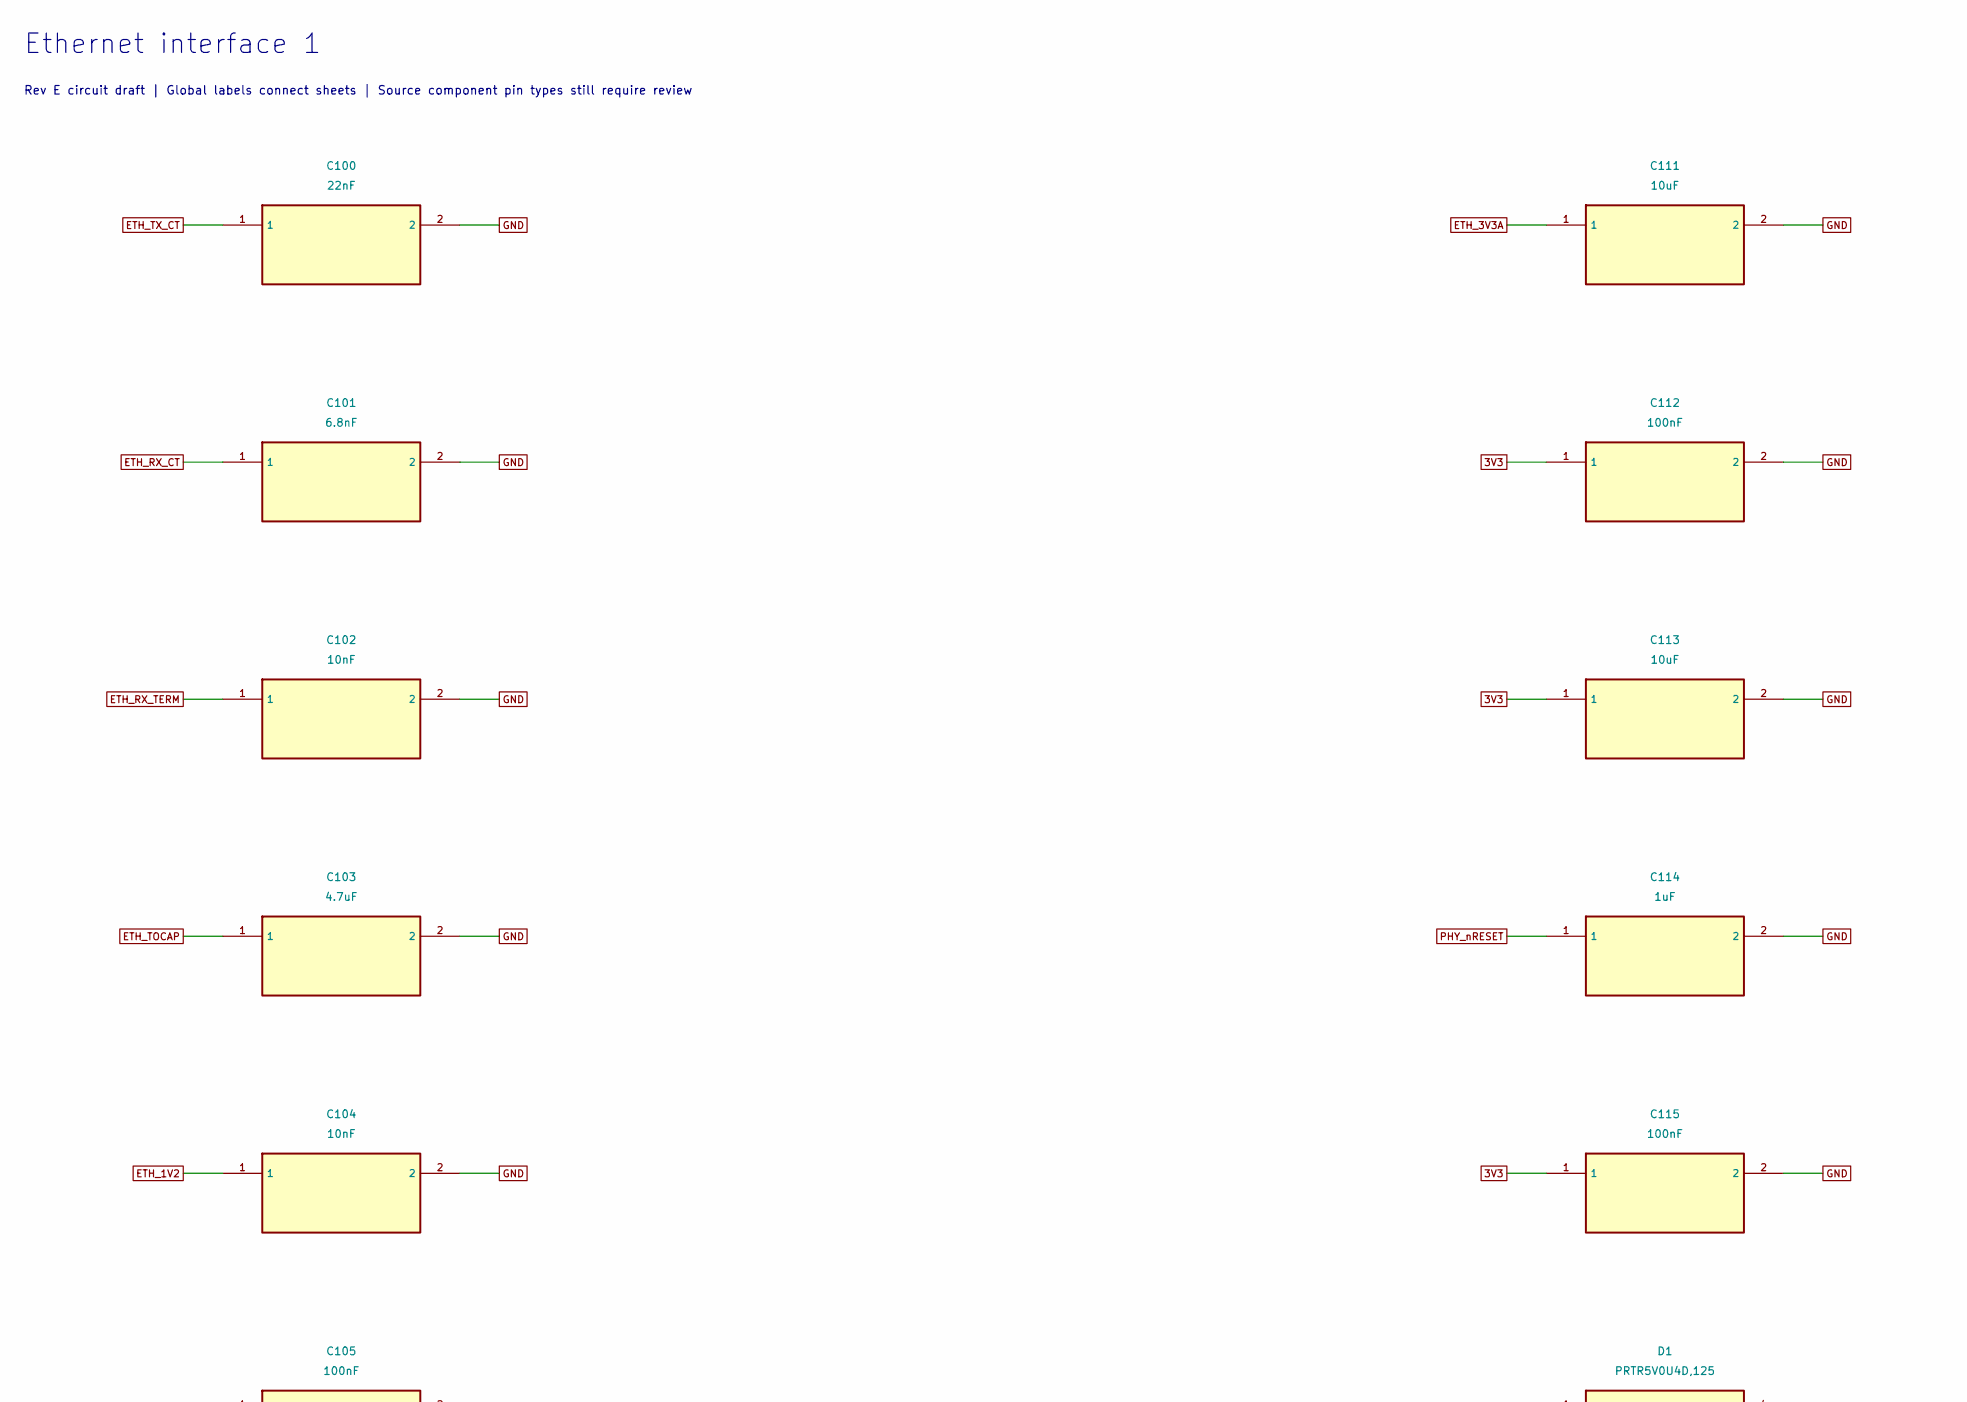
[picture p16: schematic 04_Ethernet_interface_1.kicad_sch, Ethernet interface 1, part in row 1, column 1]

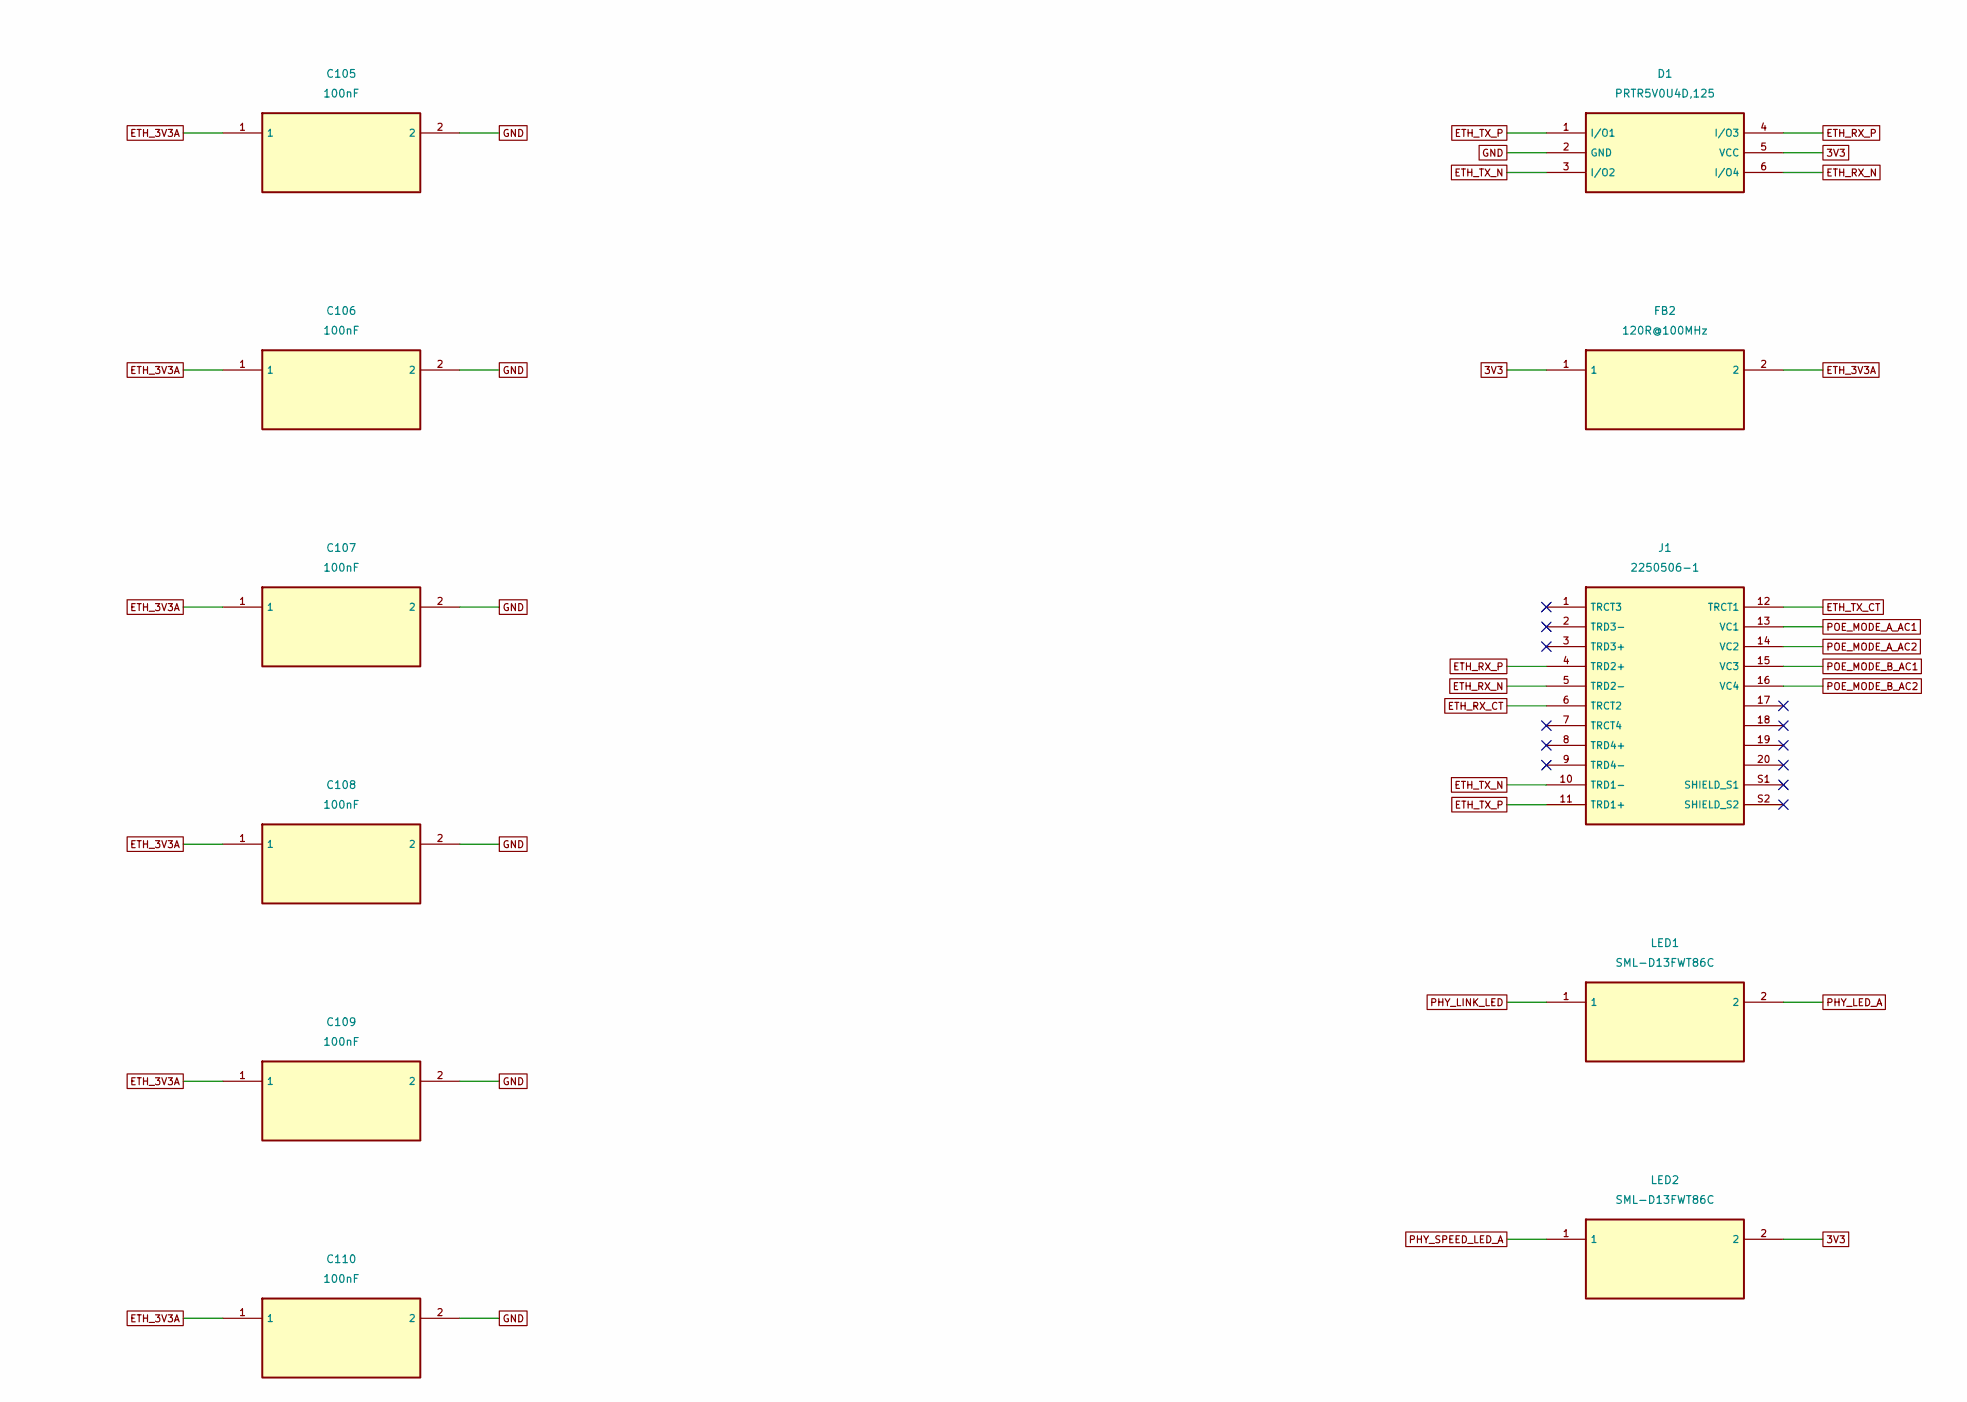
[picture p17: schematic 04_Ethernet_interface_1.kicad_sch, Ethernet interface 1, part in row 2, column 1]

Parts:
C100: 22nF; C100_RevB; Voltage Rating 50 V; Tolerance 10%; Manufacturer Part Number C0603C223K5RACTU
C101: 6.8nF; C101_RevB; Voltage Rating 50 V; Tolerance 5%; Manufacturer Part Number C0603C682J5GACTU
C102: 10nF; C102_RevB; Voltage Rating 50 V; Tolerance 10%; Manufacturer Part Number C0603C103K5RACTU
C103: 4.7uF; C103_RevB; Voltage Rating 16 V; Tolerance 10%; Manufacturer Part Number C0805C475K4RACTU
C104: 10nF; C104_RevB; Voltage Rating 50 V; Tolerance 10%; Manufacturer Part Number C0603C103K5RACTU
C105: 100nF; C105_RevB; Voltage Rating 50 V; Tolerance 10%; Manufacturer Part Number C0603C104K5RACTU
C106: 100nF; C106_RevB; Voltage Rating 50 V; Tolerance 10%; Manufacturer Part Number C0603C104K5RACTU
C107: 100nF; C107_RevB; Voltage Rating 50 V; Tolerance 10%; Manufacturer Part Number C0603C104K5RACTU
C108: 100nF; C108_RevB; Voltage Rating 50 V; Tolerance 10%; Manufacturer Part Number C0603C104K5RACTU
C109: 100nF; C109_RevB; Voltage Rating 50 V; Tolerance 10%; Manufacturer Part Number C0603C104K5RACTU
C110: 100nF; C110_RevB; Voltage Rating 50 V; Tolerance 10%; Manufacturer Part Number C0603C104K5RACTU
C111: 10uF; C111_RevB; Voltage Rating 16 V; Tolerance 10%; Manufacturer Part Number GRM21BR61C106KE15L
C112: 100nF; C112_RevB; Voltage Rating 50 V; Tolerance 10%; Manufacturer Part Number C0603C104K5RACTU
C113: 10uF; C113_RevB; Voltage Rating 16 V; Tolerance 10%; Manufacturer Part Number GRM21BR61C106KE15L
C114: 1uF; C114_RevB; Voltage Rating 16 V; Tolerance 10%; Manufacturer Part Number C0603C105K4RACTU
C115: 100nF; C115_RevB; Voltage Rating 50 V; Tolerance 10%; Manufacturer Part Number C0603C104K5RACTU
D1: PRTR5V0U4D,125; D1_RevB; Manufacturer Part Number PRTR5V0U4D,125
FB2: 120R@100MHz; FB2_RevB; Manufacturer Part Number BLM18PG121SN1D
J1: 2250506-1; J1_RevB; Manufacturer Part Number 2250506-1
LED1: SML-D13FWT86C; LED1_RevB; Manufacturer Part Number SML-D13FWT86C
LED2: SML-D13FWT86C; LED2_RevB; Manufacturer Part Number SML-D13FWT86C

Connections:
3V3: C112.1, C113.1, C115.1, D1.5 (VCC), FB2.1, LED2.2; also elsewhere on the board
ETH_1V2: C104.1; also elsewhere on the board
ETH_3V3A: C105.1, C106.1, C107.1, C108.1, C109.1, C110.1, C111.1, FB2.2; also elsewhere on the board
ETH_RX_CT: C101.1, J1.6 (TRCT2)
ETH_RX_N: D1.6 (I/O4), J1.5 (TRD2-); also elsewhere on the board
ETH_RX_P: D1.4 (I/O3), J1.4 (TRD2+); also elsewhere on the board
ETH_RX_TERM: C102.1; also elsewhere on the board
ETH_TOCAP: C103.1; also elsewhere on the board
ETH_TX_CT: C100.1, J1.12 (TRCT1); also elsewhere on the board
ETH_TX_N: D1.3 (I/O2), J1.10 (TRD1-); also elsewhere on the board
ETH_TX_P: D1.1 (I/O1), J1.11 (TRD1+); also elsewhere on the board
GND: C100.2, C101.2, C102.2, C103.2, C104.2, C105.2, C106.2, C107.2, C108.2, C109.2, C110.2, C111.2, C112.2, C113.2, C114.2, C115.2, D1.2 (GND); also elsewhere on the board
PHY_LED_A: LED1.2; also elsewhere on the board
PHY_LINK_LED: LED1.1; also elsewhere on the board
PHY_SPEED_LED_A: LED2.1; also elsewhere on the board
PHY_nRESET: C114.1; also elsewhere on the board
POE_MODE_A_AC1: J1.13 (VC1); also elsewhere on the board
POE_MODE_A_AC2: J1.14 (VC2); also elsewhere on the board
POE_MODE_B_AC1: J1.15 (VC3); also elsewhere on the board
POE_MODE_B_AC2: J1.16 (VC4); also elsewhere on the board

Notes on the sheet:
Ethernet interface 1
Rev E circuit draft | Global labels connect sheets | Source component pin types still require review

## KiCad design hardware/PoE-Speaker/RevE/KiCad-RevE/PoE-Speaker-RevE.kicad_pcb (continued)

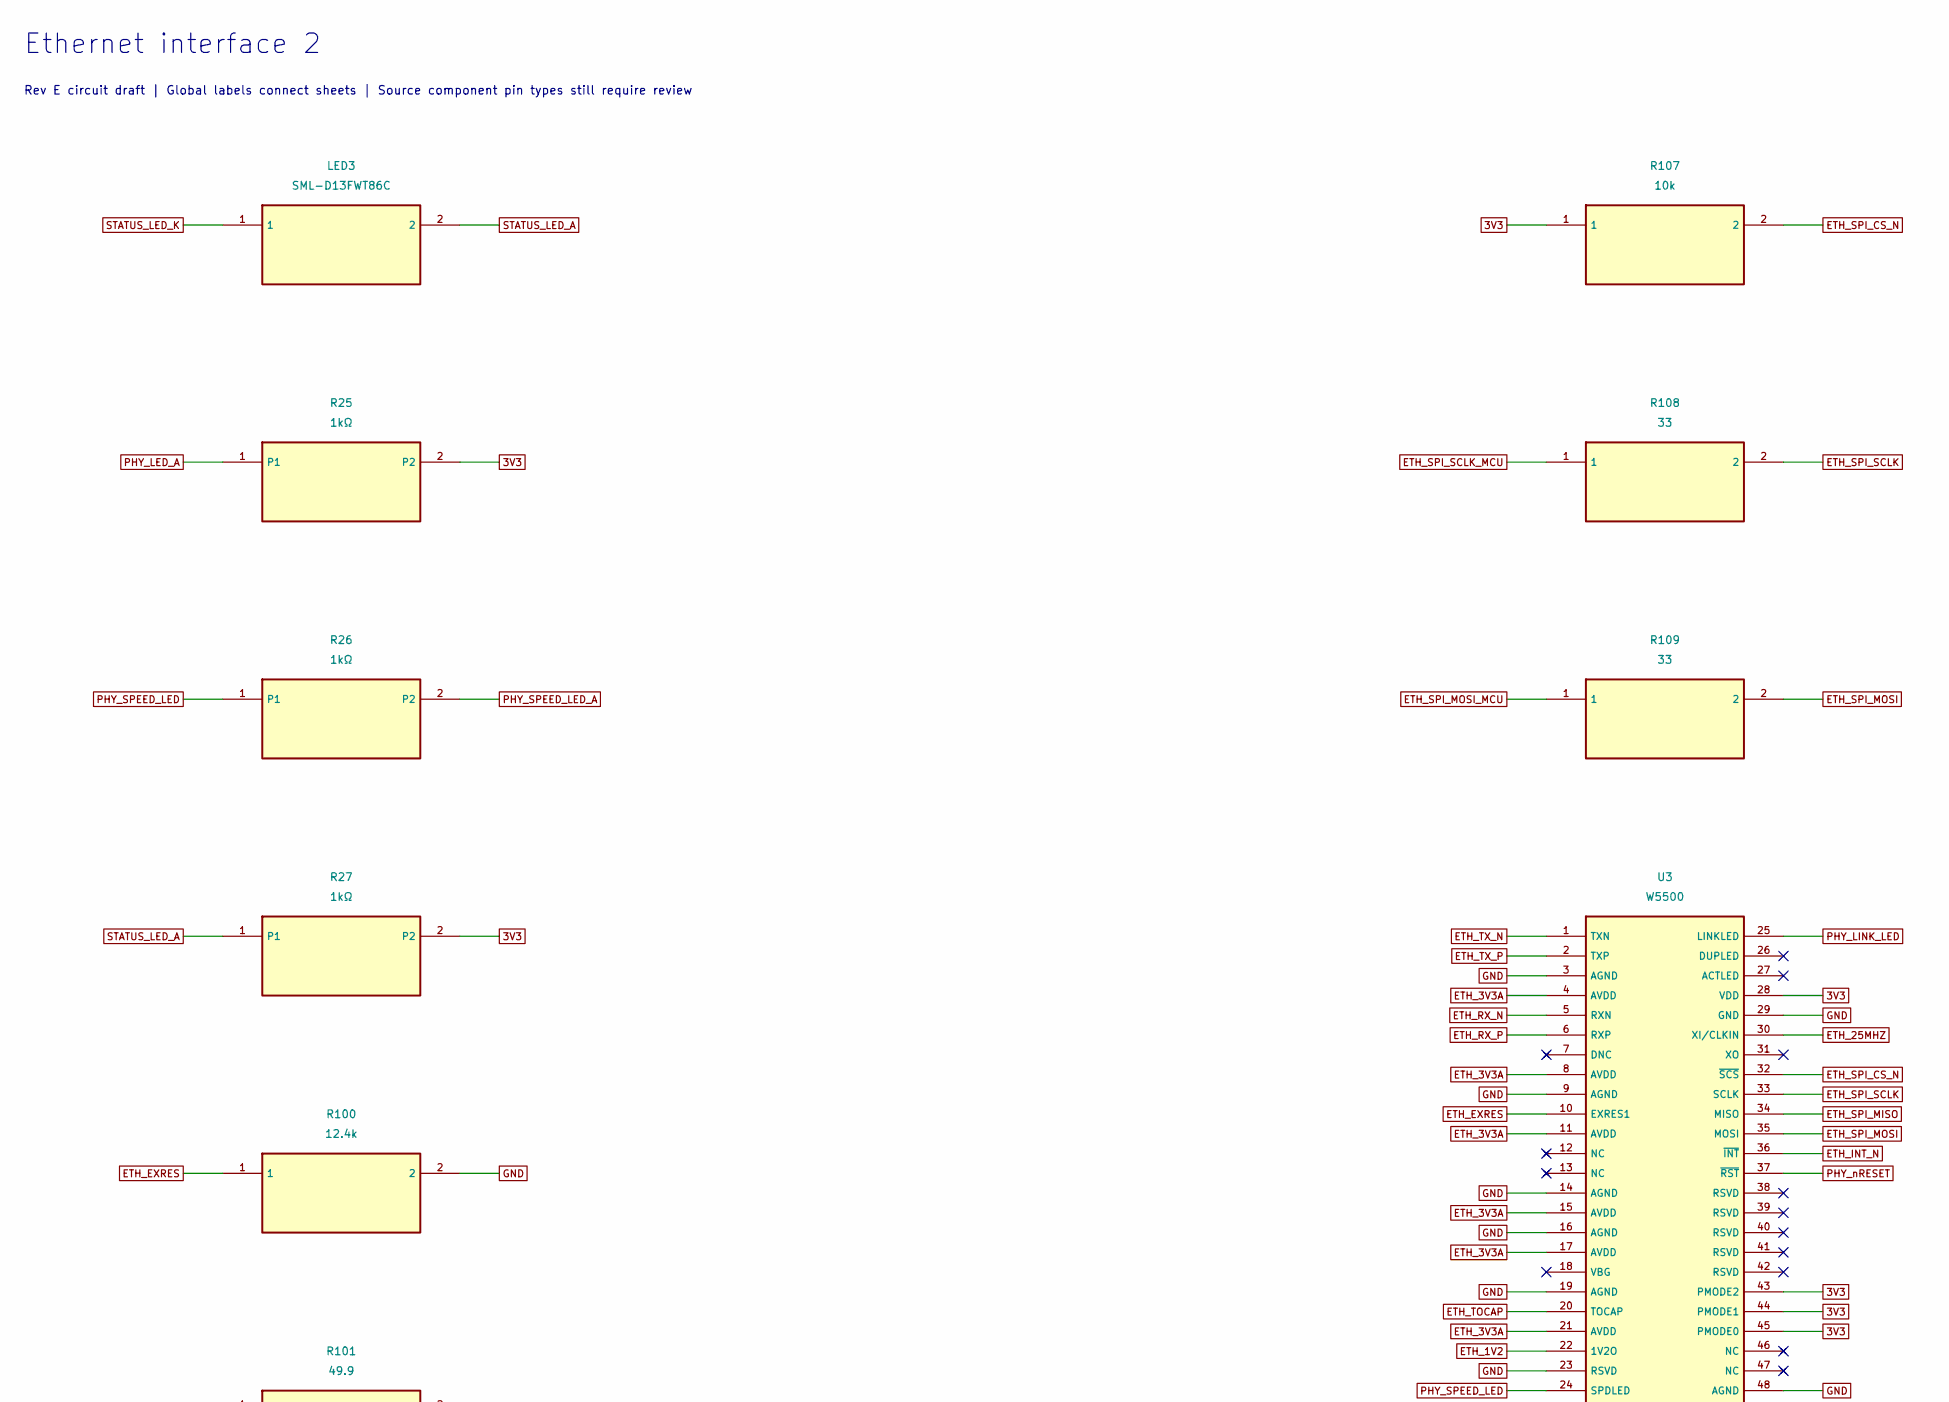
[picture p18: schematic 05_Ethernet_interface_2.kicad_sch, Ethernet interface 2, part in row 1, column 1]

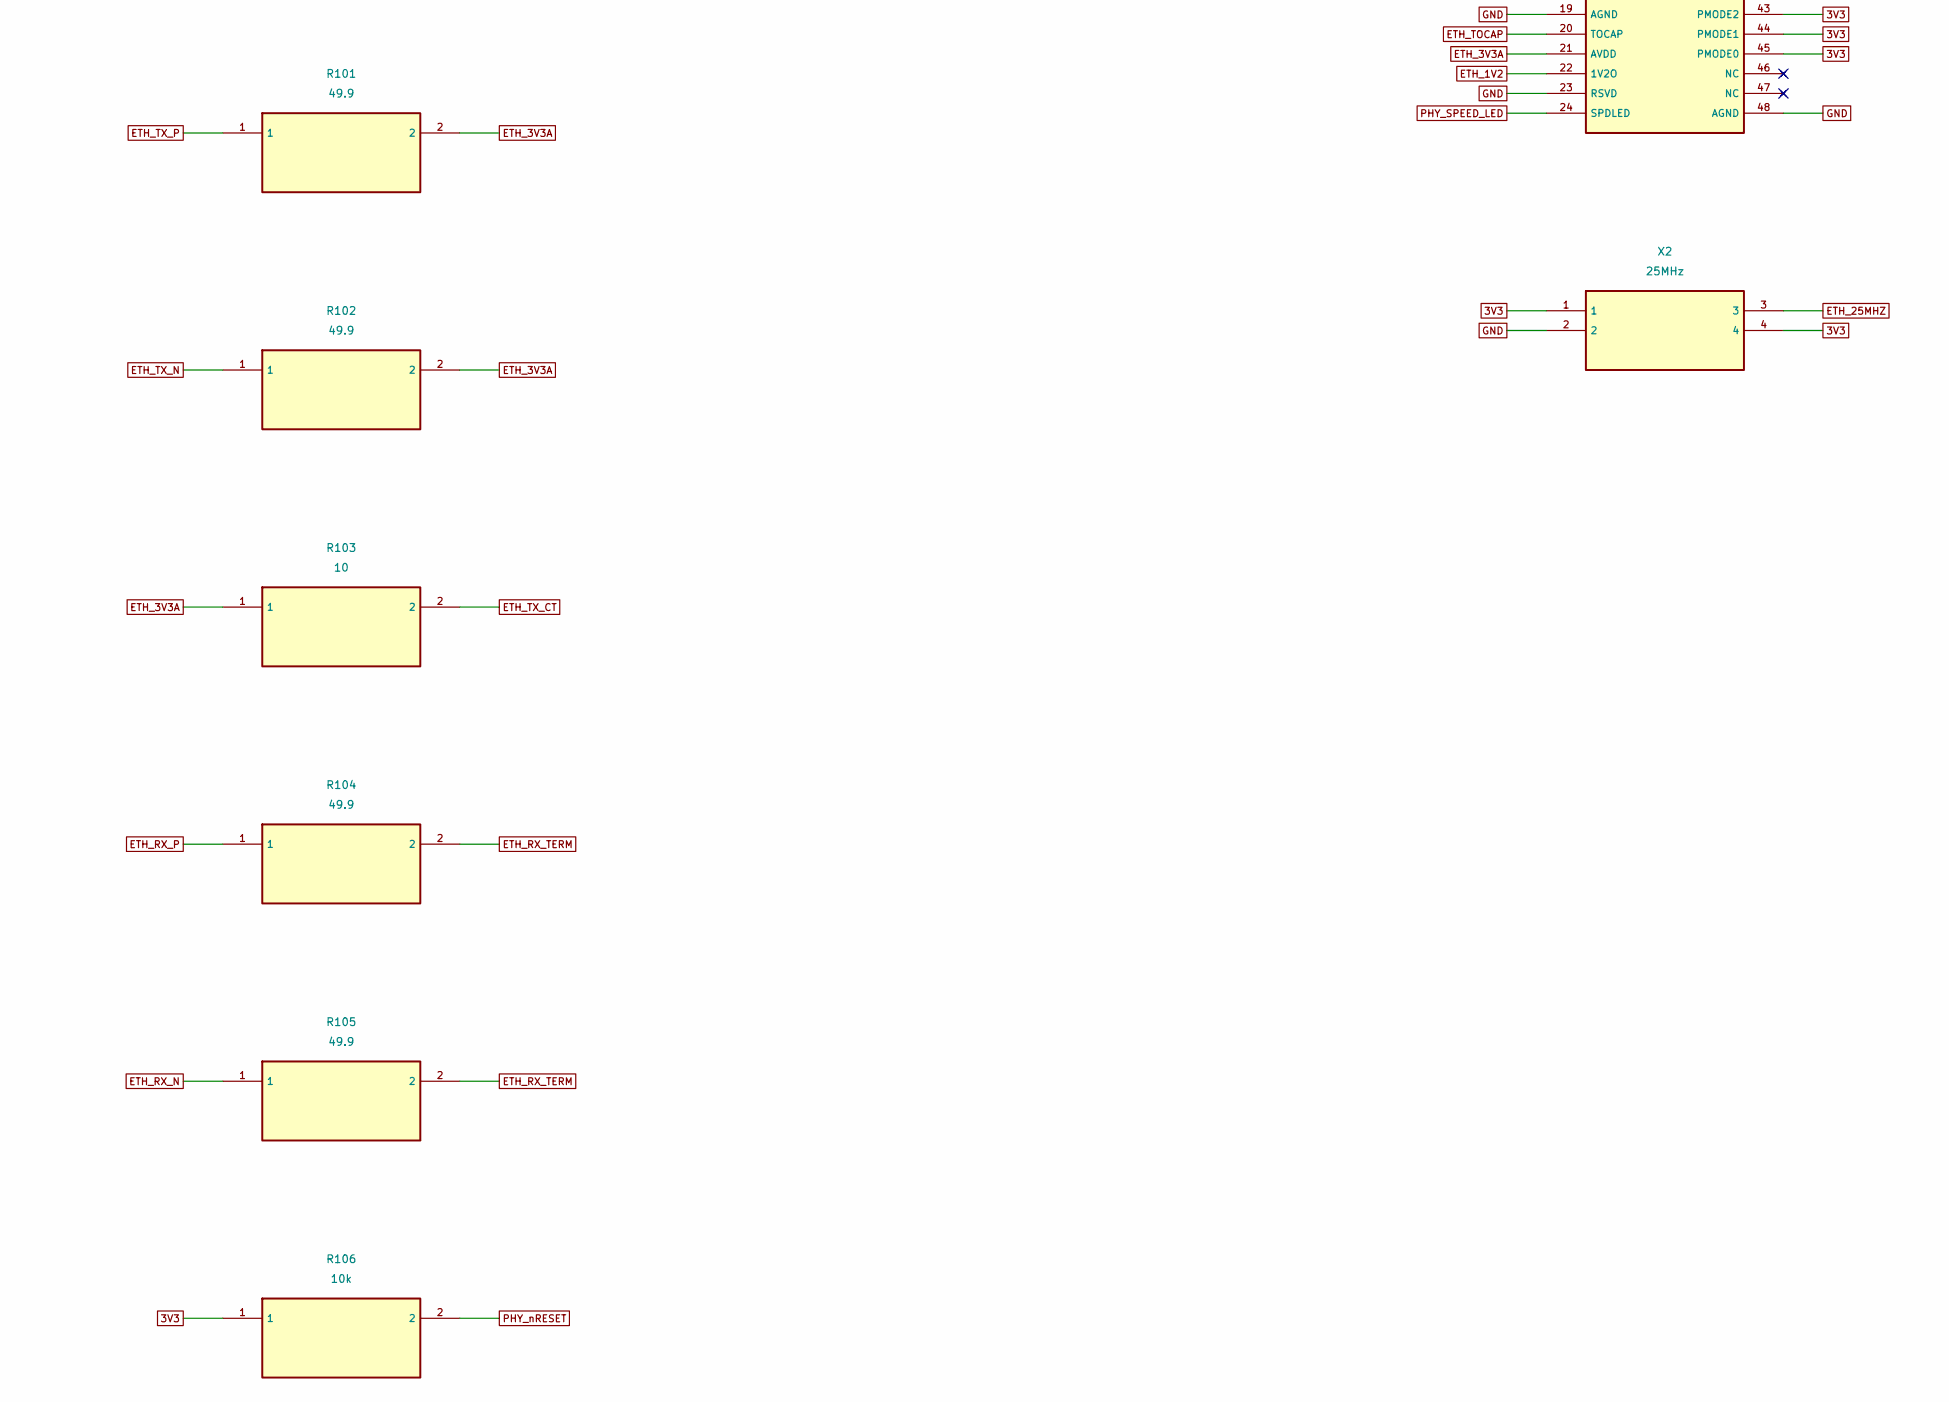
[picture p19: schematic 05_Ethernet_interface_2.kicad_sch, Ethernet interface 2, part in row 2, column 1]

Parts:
LED3: SML-D13FWT86C; LED3_RevB; Manufacturer Part Number SML-D13FWT86C
R25: 1kΩ; R25_RevB; Tolerance 1%; Power rating 0.10 W conservative; Part Type Resistor
R26: 1kΩ; R26_RevB; Tolerance 1%; Power rating 0.10 W conservative; Part Type Resistor
R27: 1kΩ; R27_RevB; Tolerance 1%; Power rating 0.10 W conservative; Part Type Resistor
R100: 12.4k; R100_RevB; Tolerance 1%; Power rating 0.10 W conservative; Manufacturer Part Number TNPW060312K4FHEA
R101: 49.9; R101_RevB; Tolerance 1%; Power rating 0.10 W conservative; Manufacturer Part Number TNPW060349R9FHEA
R102: 49.9; R102_RevB; Tolerance 1%; Power rating 0.10 W conservative; Manufacturer Part Number TNPW060349R9FHEA
R103: 10; R103_RevB; Tolerance 1%; Power rating 0.10 W conservative; Manufacturer Part Number TNPW060310R0FHEA
R104: 49.9; R104_RevB; Tolerance 1%; Power rating 0.10 W conservative; Manufacturer Part Number TNPW060349R9FHEA
R105: 49.9; R105_RevB; Tolerance 1%; Power rating 0.10 W conservative; Manufacturer Part Number TNPW060349R9FHEA
R106: 10k; R106_RevB; Tolerance 1%; Power rating 0.10 W conservative; Manufacturer Part Number TNPW060310K0FHEA
R107: 10k; R107_RevB; Tolerance 1%; Power rating 0.10 W conservative; Manufacturer Part Number TNPW060310K0FHEA
R108: 33; R108_RevB; Tolerance 1%; Power rating 0.10 W conservative; Manufacturer Part Number TNPW060333R0FHEA
R109: 33; R109_RevB; Tolerance 1%; Power rating 0.10 W conservative; Manufacturer Part Number TNPW060333R0FHEA
U3: W5500; U3_RevB; Manufacturer Part Number W5500
X2: 25MHz; X2_RevB; Manufacturer Part Number ASE-25.000MHZ-LC-T

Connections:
3V3: R25.2, R27.2, R106.1, R107.1, U3.28 (VDD), U3.43 (PMODE2), U3.44 (PMODE1), U3.45 (PMODE0), X2.1, X2.4; also elsewhere on the board
ETH_1V2: U3.22 (1V2O); also elsewhere on the board
ETH_3V3A: R101.2, R102.2, R103.1, U3.4 (AVDD), U3.8 (AVDD), U3.11 (AVDD), U3.15 (AVDD), U3.17 (AVDD), U3.21 (AVDD); also elsewhere on the board
ETH_25MHZ: U3.30 (XI/CLKIN), X2.3
ETH_EXRES: R100.1, U3.10 (EXRES1)
ETH_INT_N: U3.36 (~INT); also elsewhere on the board
ETH_RX_N: R105.1, U3.5 (RXN); also elsewhere on the board
ETH_RX_P: R104.1, U3.6 (RXP); also elsewhere on the board
ETH_RX_TERM: R104.2, R105.2; also elsewhere on the board
ETH_SPI_CS_N: R107.2, U3.32 (~SCS); also elsewhere on the board
ETH_SPI_MISO: U3.34 (MISO); also elsewhere on the board
ETH_SPI_MOSI: R109.2, U3.35 (MOSI); also elsewhere on the board
ETH_SPI_MOSI_MCU: R109.1; also elsewhere on the board
ETH_SPI_SCLK: R108.2, U3.33 (SCLK); also elsewhere on the board
ETH_SPI_SCLK_MCU: R108.1; also elsewhere on the board
ETH_TOCAP: U3.20 (TOCAP); also elsewhere on the board
ETH_TX_CT: R103.2; also elsewhere on the board
ETH_TX_N: R102.1, U3.1 (TXN); also elsewhere on the board
ETH_TX_P: R101.1, U3.2 (TXP); also elsewhere on the board
GND: R100.2, U3.3 (AGND), U3.9 (AGND), U3.14 (AGND), U3.16 (AGND), U3.19 (AGND), U3.23 (RSVD), U3.29 (GND), U3.48 (AGND), X2.2; also elsewhere on the board
PHY_LED_A: R25.1; also elsewhere on the board
PHY_LINK_LED: U3.25 (LINKLED); also elsewhere on the board
PHY_SPEED_LED: R26.1, U3.24 (SPDLED)
PHY_SPEED_LED_A: R26.2; also elsewhere on the board
PHY_nRESET: R106.2, U3.37 (~RST); also elsewhere on the board
STATUS_LED_A: LED3.2, R27.1
STATUS_LED_K: LED3.1; also elsewhere on the board

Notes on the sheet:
Ethernet interface 2
Rev E circuit draft | Global labels connect sheets | Source component pin types still require review

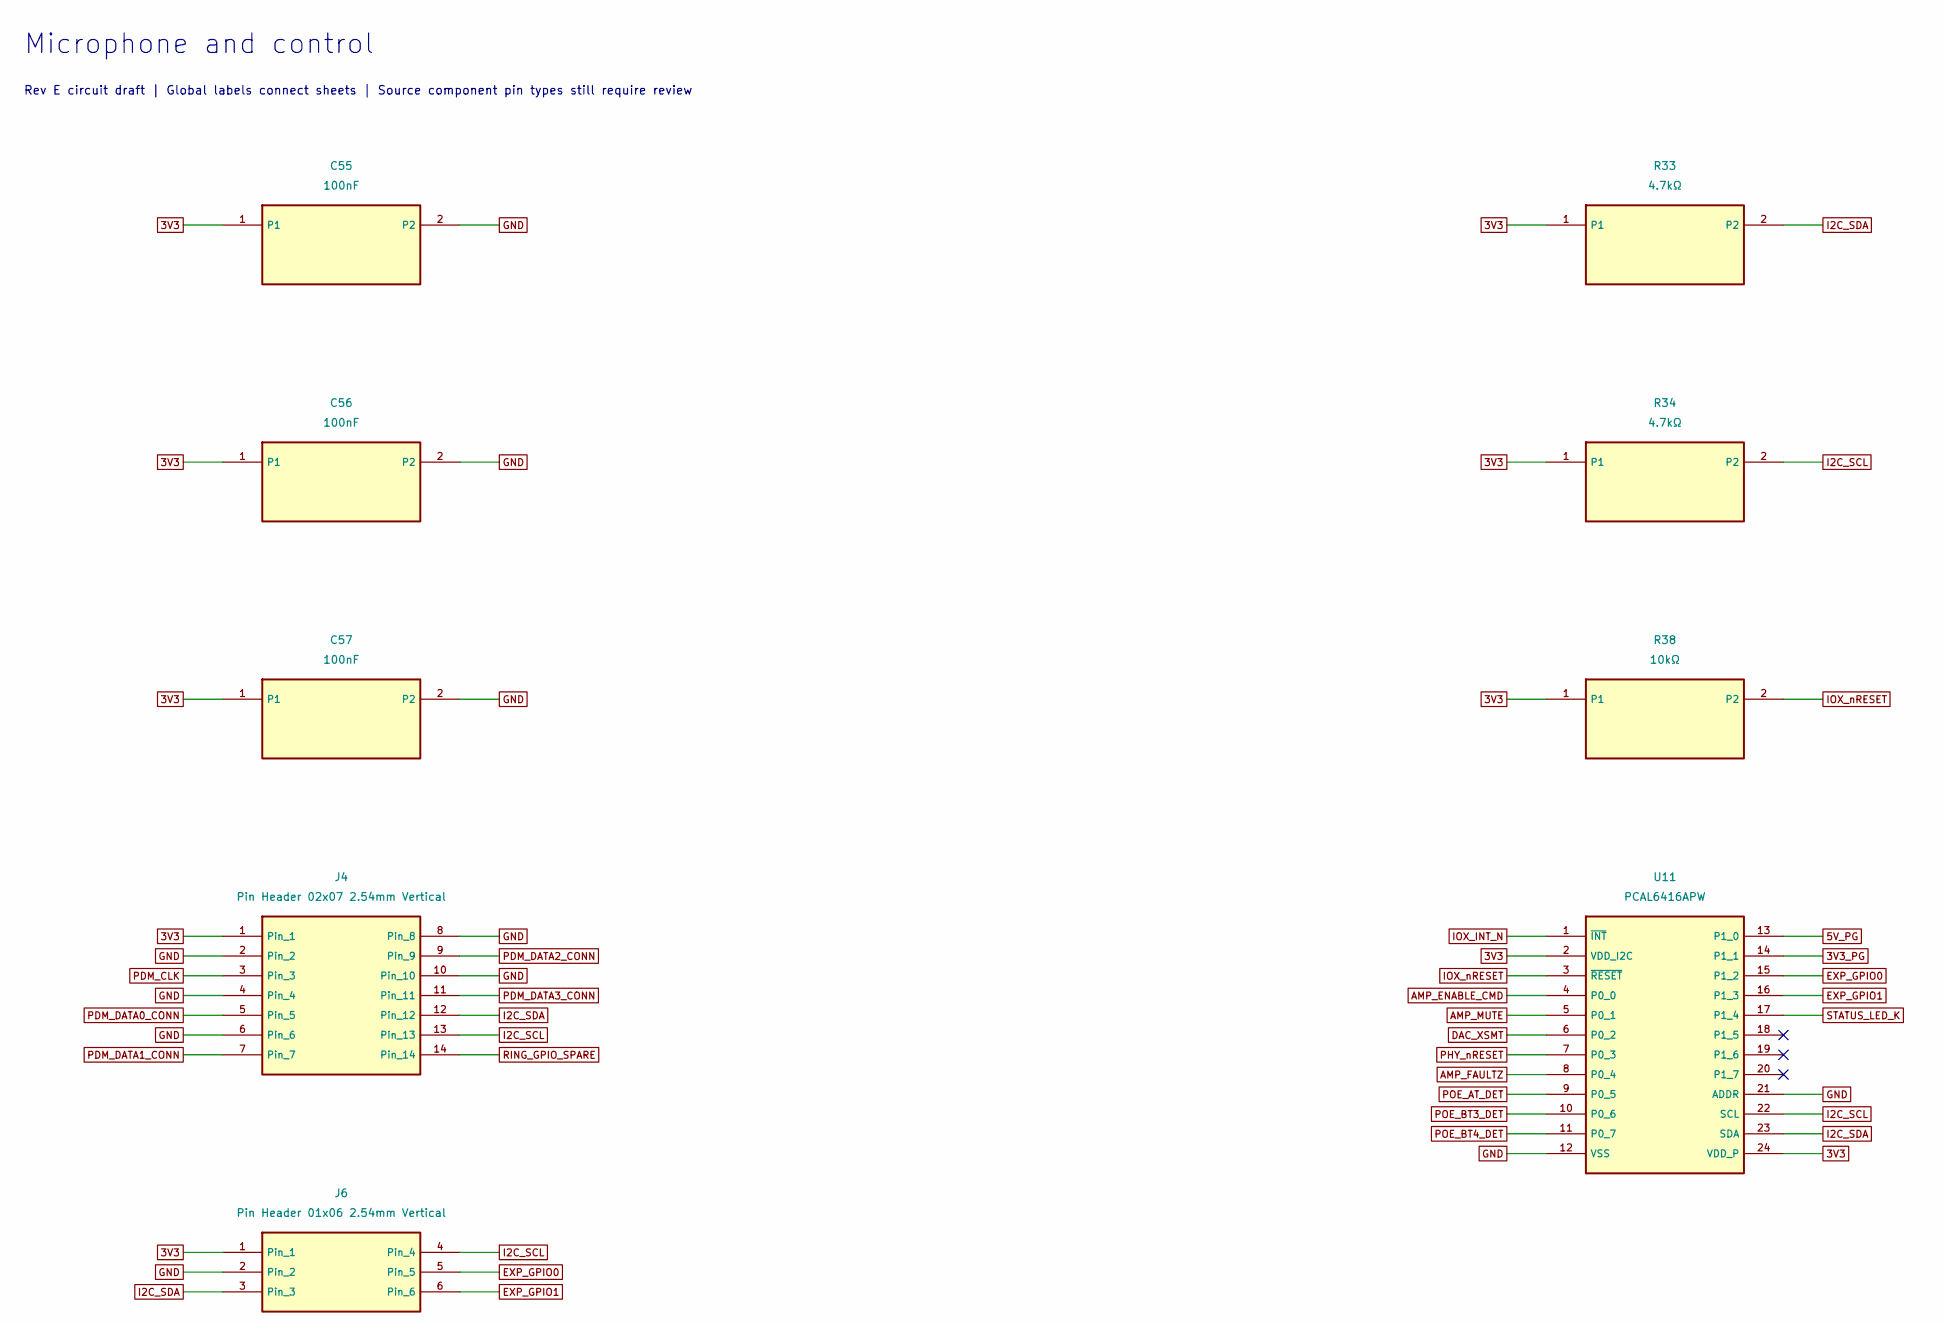
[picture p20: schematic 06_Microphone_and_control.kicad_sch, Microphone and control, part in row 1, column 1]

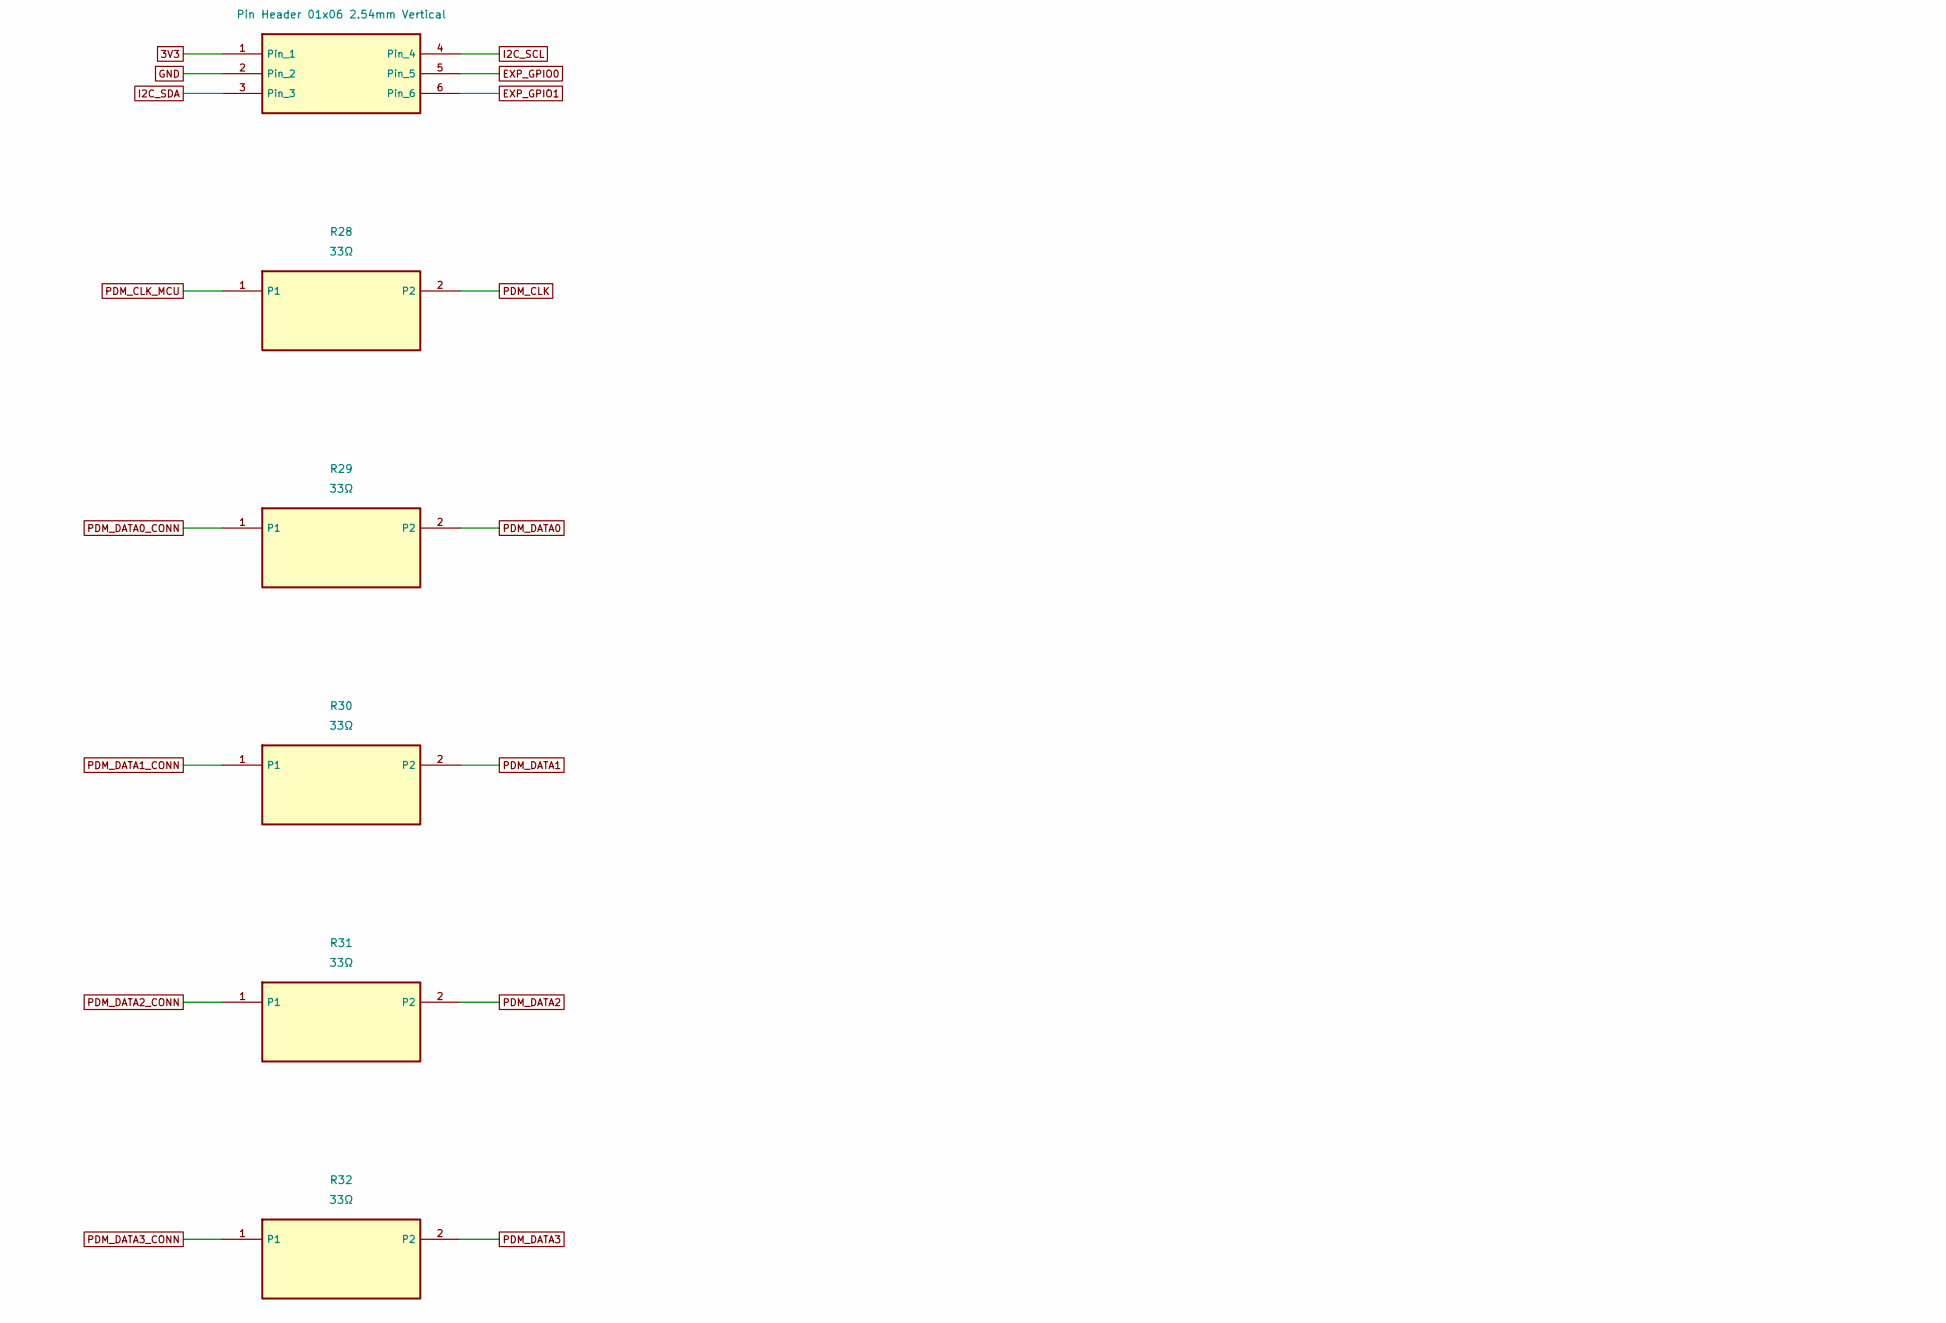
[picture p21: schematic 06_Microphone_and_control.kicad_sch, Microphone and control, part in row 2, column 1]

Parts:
C55: 100nF; C55_RevB; Voltage Rating 50 V; Tolerance 10%; Manufacturer Part Number C0603C104K5RACTU
C56: 100nF; C56_RevB; Voltage Rating 50 V; Tolerance 10%; Manufacturer Part Number C0603C104K5RACTU
C57: 100nF; C57_RevB; Voltage Rating 50 V; Tolerance 10%; Manufacturer Part Number C0603C104K5RACTU
J4: Pin Header 02x07 2.54mm Vertical; J4_RevB; Manufacturer Part Number TSW-107-07-G-D
J6: Pin Header 01x06 2.54mm Vertical; J6_RevB; Part Type Connector
R28: 33Ω; R28_RevB; Tolerance 1%; Power rating 0.10 W conservative; Part Type Resistor
R29: 33Ω; R29_RevB; Tolerance 1%; Power rating 0.10 W conservative; Part Type Resistor
R30: 33Ω; R30_RevB; Tolerance 1%; Power rating 0.10 W conservative; Part Type Resistor
R31: 33Ω; R31_RevB; Tolerance 1%; Power rating 0.10 W conservative; Part Type Resistor
R32: 33Ω; R32_RevB; Tolerance 1%; Power rating 0.10 W conservative; Part Type Resistor
R33: 4.7kΩ; R33_RevB; Tolerance 1%; Power rating 0.10 W conservative; Part Type Resistor
R34: 4.7kΩ; R34_RevB; Tolerance 1%; Power rating 0.10 W conservative; Part Type Resistor
R38: 10kΩ; R38_RevB; Tolerance 1%; Power rating 0.10 W conservative; Part Type Resistor
U11: PCAL6416APW; U11_RevB; Manufacturer Part Number PCAL6416APW

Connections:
3V3: C55.1, C56.1, C57.1, J4.1, J6.1, R33.1, R34.1, R38.1, U11.2 (VDD_I2C), U11.24 (VDD_P); also elsewhere on the board
3V3_PG: U11.14 (P1_1); also elsewhere on the board
5V_PG: U11.13 (P1_0); also elsewhere on the board
AMP_ENABLE_CMD: U11.4 (P0_0); also elsewhere on the board
AMP_FAULTZ: U11.8 (P0_4); also elsewhere on the board
AMP_MUTE: U11.5 (P0_1); also elsewhere on the board
DAC_XSMT: U11.6 (P0_2); also elsewhere on the board
EXP_GPIO0: J6.5, U11.15 (P1_2)
EXP_GPIO1: J6.6, U11.16 (P1_3)
GND: C55.2, C56.2, C57.2, J4.2, J4.4, J4.6, J4.8, J4.10, J6.2, U11.12 (VSS), U11.21 (ADDR); also elsewhere on the board
I2C_SCL: J4.13, J6.4, R34.2, U11.22 (SCL); also elsewhere on the board
I2C_SDA: J4.12, J6.3, R33.2, U11.23 (SDA); also elsewhere on the board
IOX_INT_N: U11.1 (~INT); also elsewhere on the board
IOX_nRESET: R38.2, U11.3 (~RESET); also elsewhere on the board
PDM_CLK: J4.3, R28.2; also elsewhere on the board
PDM_CLK_MCU: R28.1; also elsewhere on the board
PDM_DATA0: R29.2; also elsewhere on the board
PDM_DATA0_CONN: J4.5, R29.1
PDM_DATA1: R30.2; also elsewhere on the board
PDM_DATA1_CONN: J4.7, R30.1
PDM_DATA2: R31.2; also elsewhere on the board
PDM_DATA2_CONN: J4.9, R31.1
PDM_DATA3: R32.2; also elsewhere on the board
PDM_DATA3_CONN: J4.11, R32.1
PHY_nRESET: U11.7 (P0_3); also elsewhere on the board
POE_AT_DET: U11.9 (P0_5); also elsewhere on the board
POE_BT3_DET: U11.10 (P0_6); also elsewhere on the board
POE_BT4_DET: U11.11 (P0_7); also elsewhere on the board
RING_GPIO_SPARE: J4.14; also elsewhere on the board
STATUS_LED_K: U11.17 (P1_4); also elsewhere on the board

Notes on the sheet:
Microphone and control
Rev E circuit draft | Global labels connect sheets | Source component pin types still require review

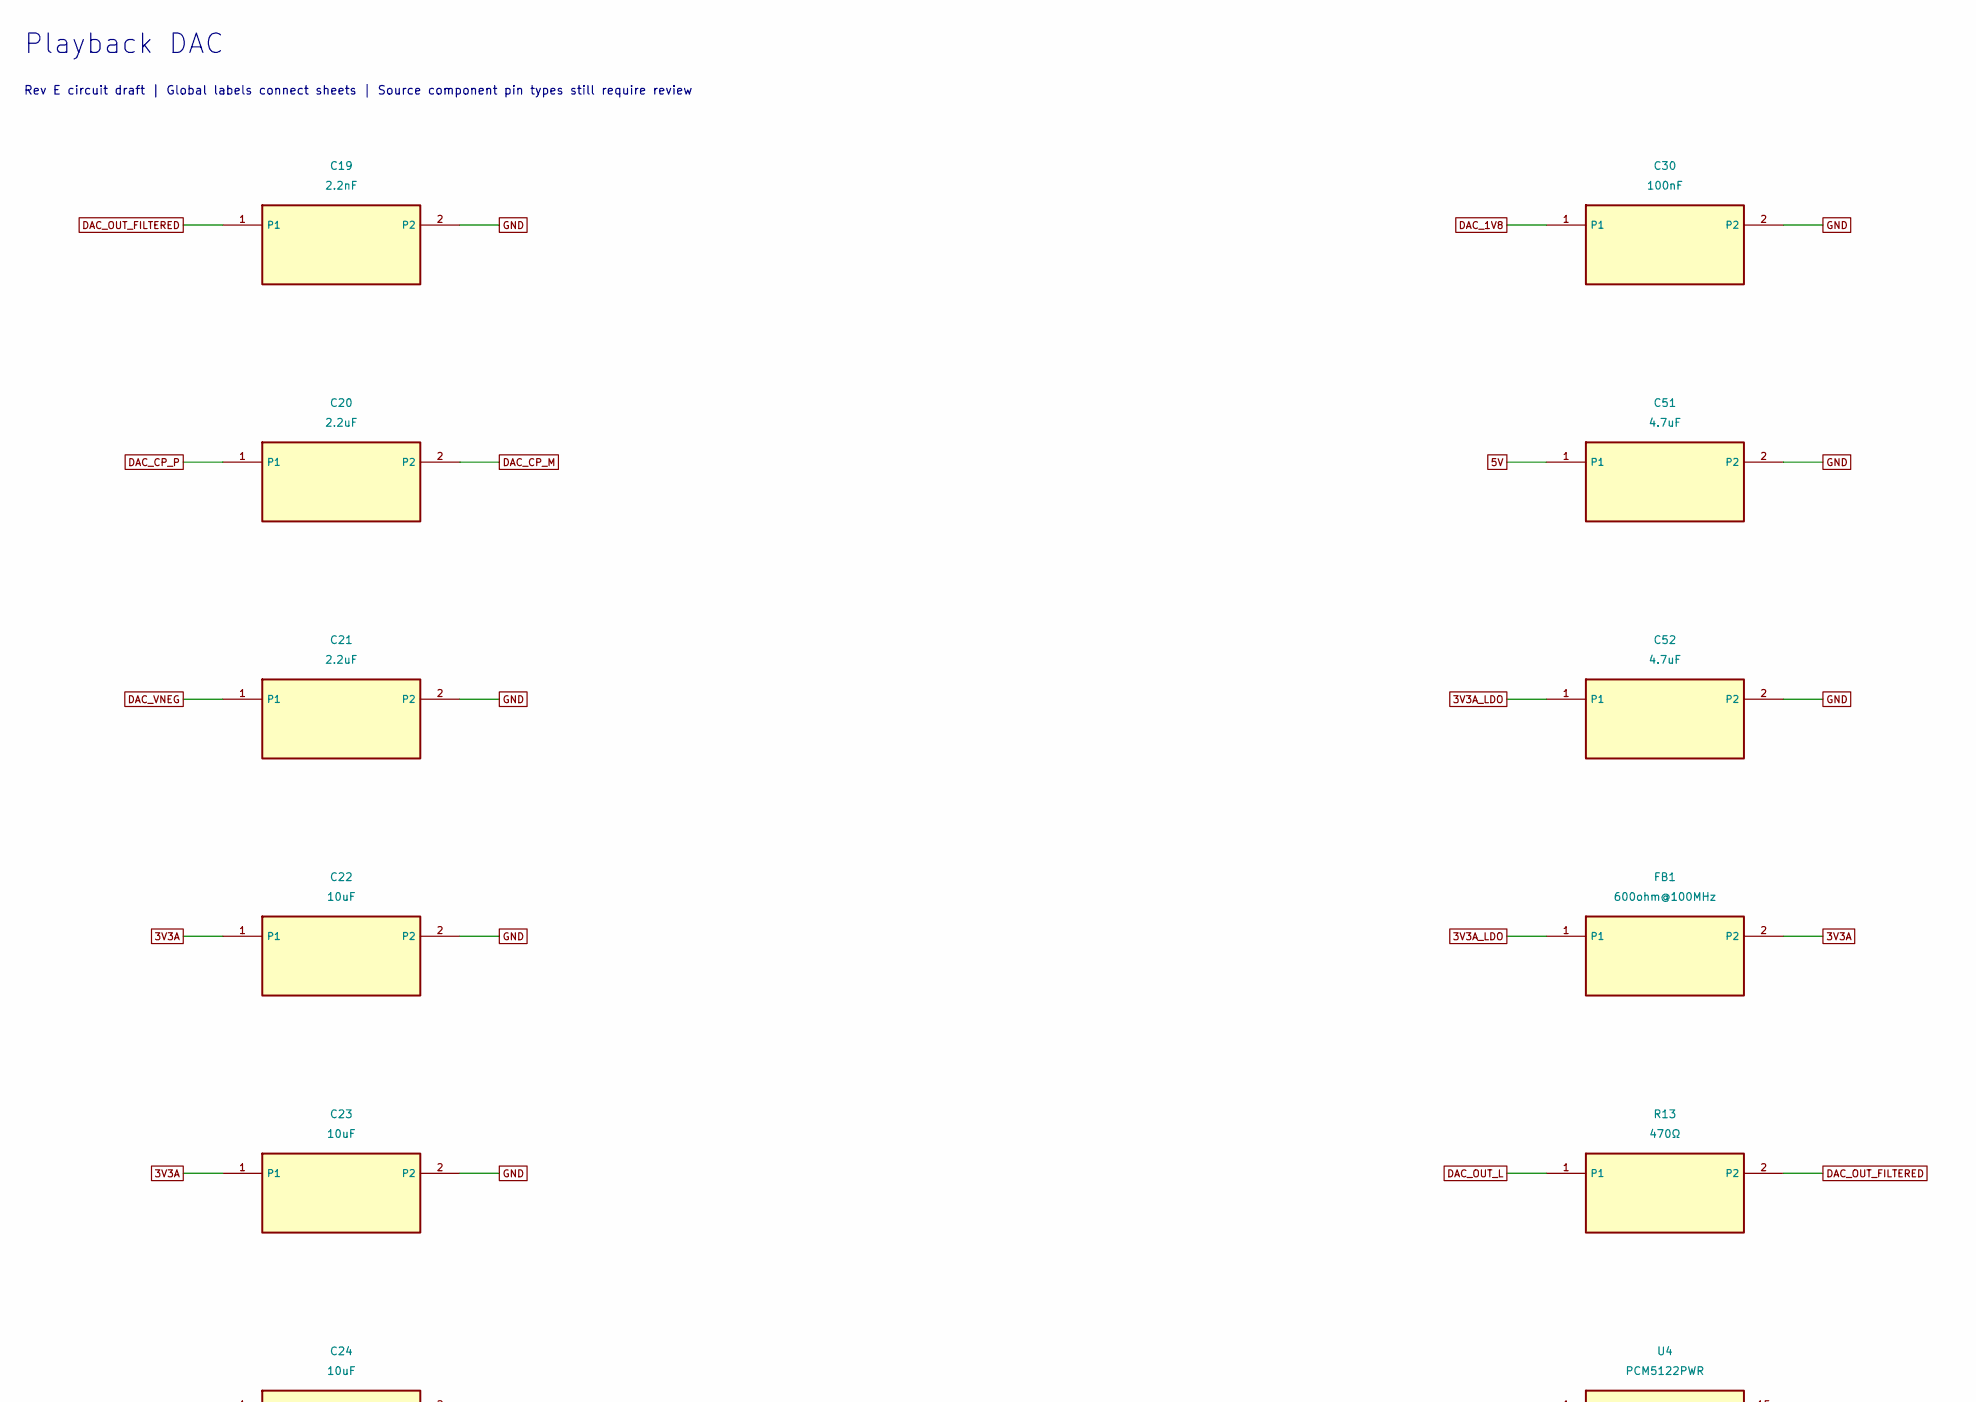
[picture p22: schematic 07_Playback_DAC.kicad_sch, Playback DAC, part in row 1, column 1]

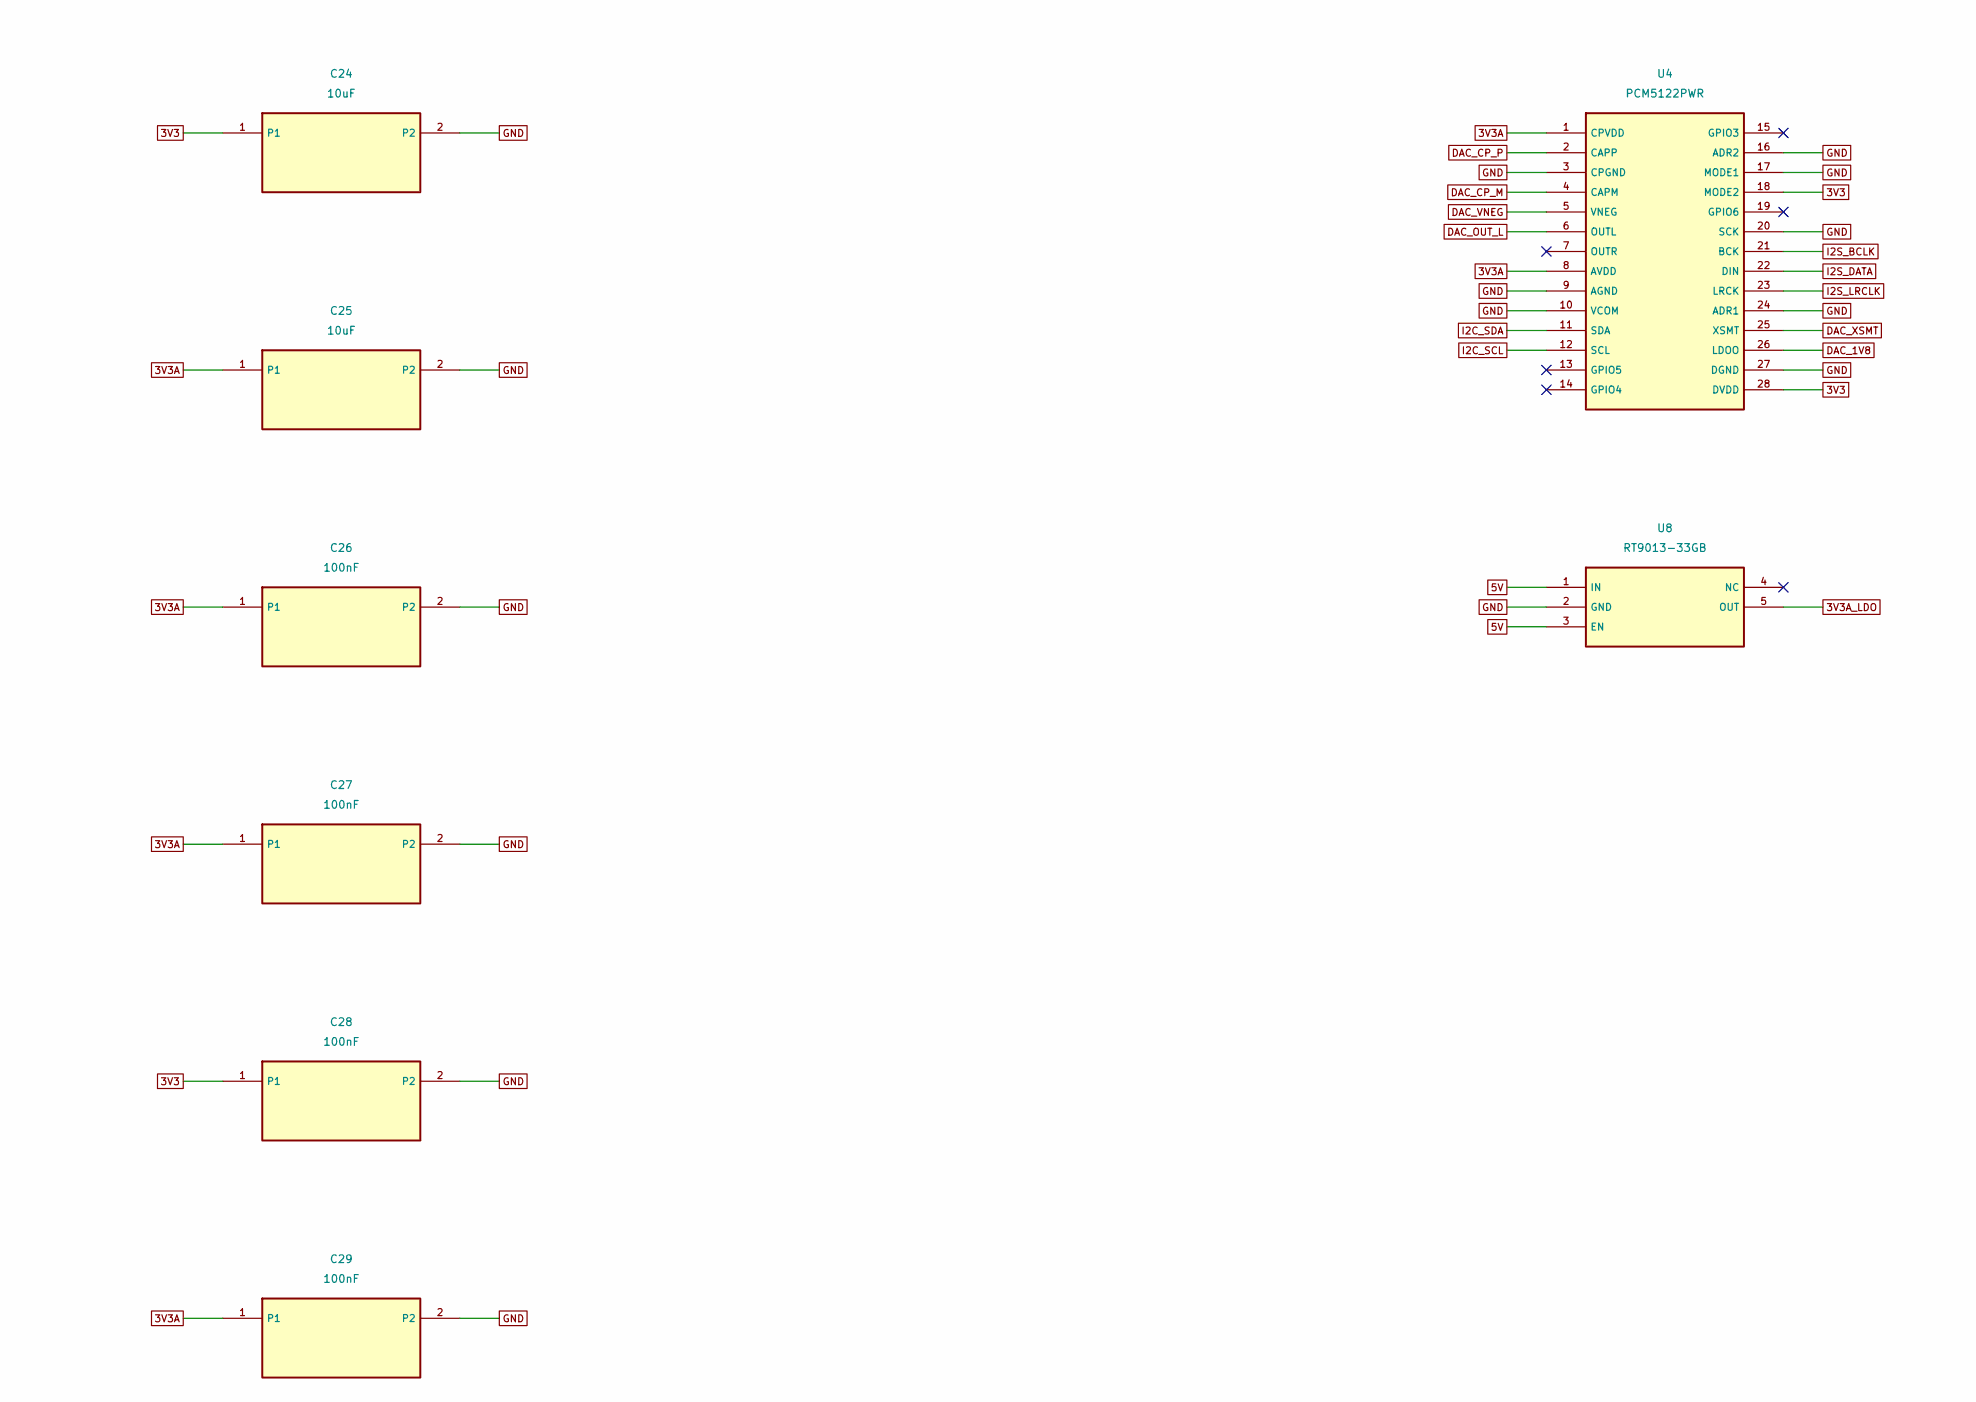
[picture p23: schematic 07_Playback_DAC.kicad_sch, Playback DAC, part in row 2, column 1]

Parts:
C19: 2.2nF; C19_RevB; Voltage Rating 50 V; Tolerance 5%; Manufacturer Part Number C0603C222J5GACTU
C20: 2.2uF; C20_RevB; Voltage Rating 25 V; Tolerance 10%; Manufacturer Part Number C0805C225K3RACTU
C21: 2.2uF; C21_RevB; Voltage Rating 25 V; Tolerance 10%; Manufacturer Part Number C0805C225K3RACTU
C22: 10uF; C22_RevB; Voltage Rating 16 V; Tolerance 10%; Manufacturer Part Number GRM21BR61C106KE15L
C23: 10uF; C23_RevB; Voltage Rating 16 V; Tolerance 10%; Manufacturer Part Number GRM21BR61C106KE15L
C24: 10uF; C24_RevB; Voltage Rating 16 V; Tolerance 10%; Manufacturer Part Number GRM21BR61C106KE15L
C25: 10uF; C25_RevB; Voltage Rating 16 V; Tolerance 10%; Manufacturer Part Number GRM21BR61C106KE15L
C26: 100nF; C26_RevB; Voltage Rating 50 V; Tolerance 10%; Manufacturer Part Number C0603C104K5RACTU
C27: 100nF; C27_RevB; Voltage Rating 50 V; Tolerance 10%; Manufacturer Part Number C0603C104K5RACTU
C28: 100nF; C28_RevB; Voltage Rating 50 V; Tolerance 10%; Manufacturer Part Number C0603C104K5RACTU
C29: 100nF; C29_RevB; Voltage Rating 50 V; Tolerance 10%; Manufacturer Part Number C0603C104K5RACTU
C30: 100nF; C30_RevB; Voltage Rating 50 V; Tolerance 10%; Manufacturer Part Number C0603C104K5RACTU
C51: 4.7uF; C51_RevB; Voltage Rating 16 V; Tolerance 10%; Manufacturer Part Number C0805C475K4RACTU
C52: 4.7uF; C52_RevB; Voltage Rating 16 V; Tolerance 10%; Manufacturer Part Number C0805C475K4RACTU
FB1: 600ohm@100MHz; FB1_RevB; Current Rating 0.5A; Current rating 500 mA; Part Type Inductor
R13: 470Ω; R13_RevB; Tolerance 1%; Power rating 0.10 W conservative; Part Type Resistor
U4: PCM5122PWR; U4_RevB; Part Type Digital To Analog Converters (DACs); JLCPCB Part Class Extended Part
U8: RT9013-33GB; U8_RevB; Manufacturer Part Number RT9013-33GB

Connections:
3V3: C24.1, C28.1, U4.18 (MODE2), U4.28 (DVDD); also elsewhere on the board
3V3A: C22.1, C23.1, C25.1, C26.1, C27.1, C29.1, FB1.2, U4.1 (CPVDD), U4.8 (AVDD); also elsewhere on the board
3V3A_LDO: C52.1, FB1.1, U8.5 (OUT)
5V: C51.1, U8.1 (IN), U8.3 (EN); also elsewhere on the board
DAC_1V8: C30.1, U4.26 (LDOO)
DAC_CP_M: C20.2, U4.4 (CAPM)
DAC_CP_P: C20.1, U4.2 (CAPP)
DAC_OUT_FILTERED: C19.1, R13.2; also elsewhere on the board
DAC_OUT_L: R13.1, U4.6 (OUTL)
DAC_VNEG: C21.1, U4.5 (VNEG)
DAC_XSMT: U4.25 (XSMT); also elsewhere on the board
GND: C19.2, C21.2, C22.2, C23.2, C24.2, C25.2, C26.2, C27.2, C28.2, C29.2, C30.2, C51.2, C52.2, U4.3 (CPGND), U4.9 (AGND), U4.10 (VCOM), U4.16 (ADR2), U4.17 (MODE1), U4.20 (SCK), U4.24 (ADR1), U4.27 (DGND), U8.2 (GND); also elsewhere on the board
I2C_SCL: U4.12 (SCL); also elsewhere on the board
I2C_SDA: U4.11 (SDA); also elsewhere on the board
I2S_BCLK: U4.21 (BCK); also elsewhere on the board
I2S_DATA: U4.22 (DIN); also elsewhere on the board
I2S_LRCLK: U4.23 (LRCK); also elsewhere on the board

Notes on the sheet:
Playback DAC
Rev E circuit draft | Global labels connect sheets | Source component pin types still require review

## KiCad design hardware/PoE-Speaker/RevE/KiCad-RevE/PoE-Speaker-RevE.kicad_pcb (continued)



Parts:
C1: 1000uF; C1_RevB; Voltage Rating 25V; Manufacturer Part Number EEUFR1E102
C2: 1000uF; C2_RevB; Voltage Rating 25V; Manufacturer Part Number EEUFR1E102
D2: SMAJ58A-TR; D2_RevB; Manufacturer Part Number SMAJ58A-TR; JLCPCB Part Class Extended Part
D3: B5100C; D3_RevB; Forward Voltage 0.85 V max at 5 A; Reverse Voltage 100; Manufacturer Part Number B5100C
D4: B5100C; D4_RevB; Forward Voltage 0.85 V max at 5 A; Reverse Voltage 100; Manufacturer Part Number B5100C
D5: B5100C; D5_RevB; Forward Voltage 0.85 V max at 5 A; Reverse Voltage 100; Manufacturer Part Number B5100C
D6: B5100C; D6_RevB; Forward Voltage 0.85 V max at 5 A; Reverse Voltage 100; Manufacturer Part Number B5100C
D7: B5100C; D7_RevB; Forward Voltage 0.85 V max at 5 A; Reverse Voltage 100; Manufacturer Part Number B5100C
D8: B5100C; D8_RevB; Forward Voltage 0.85 V max at 5 A; Reverse Voltage 100; Manufacturer Part Number B5100C
D9: B5100C; D9_RevB; Forward Voltage 0.85 V max at 5 A; Reverse Voltage 100; Manufacturer Part Number B5100C
D10: B5100C; D10_RevB; Forward Voltage 0.85 V max at 5 A; Reverse Voltage 100; Manufacturer Part Number B5100C
R3: 27kΩ; R3_RevB; Power Rating 0.25; Tolerance 1%; Part Type Resistor
R4: 27kΩ; R4_RevB; Power Rating 0.25; Tolerance 1%; Part Type Resistor
R5: 27kΩ; R5_RevB; Power Rating 0.25; Tolerance 1%; Part Type Resistor
R6: 10kΩ; R6_RevB; Tolerance 1%; Power rating 0.10 W conservative; Part Type Resistor
R7: 10kΩ; R7_RevB; Tolerance 1%; Power rating 0.10 W conservative; Part Type Resistor
R8: 10kΩ; R8_RevB; Tolerance 1%; Power rating 0.10 W conservative; Part Type Resistor
U1: Ag5800; U1_RevB; Part Type Integrated Circuits
U12: PC817X2NSZ9F; U12_RevB; Part Type Optocouplers - Phototransistor Output; LCSC Part Number C390734
U13: PC817X2NSZ9F; U13_RevB; Part Type Optocouplers - Phototransistor Output; LCSC Part Number C390734
U14: PC817X2NSZ9F; U14_RevB; Part Type Optocouplers - Phototransistor Output; LCSC Part Number C390734

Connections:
3V3: R6.2, R7.2, R8.2; also elsewhere on the board
24V_POE: C2.1, U1.9 (VOUT2_1), U1.10 (VOUT2_2); also elsewhere on the board
AT_DET_PRIMARY: U1.3 (AT-DET), U12.2 (Cathode)
AT_LED_A: R3.2, U12.1 (Anode)
BT3_DET_PRIMARY: U1.4 (TYP3-DET), U13.2 (Cathode)
BT3_LED_A: R4.2, U13.1 (Anode)
BT4_DET_PRIMARY: U1.5 (TYP4-DET), U14.2 (Cathode)
BT4_LED_A: R5.2, U14.1 (Anode)
GND: C1.2, U1.15 (0V1_1), U1.16 (0V1_2), U12.3 (Emitter), U13.3 (Emitter), U14.3 (Emitter); also elsewhere on the board
POE_12V_MID: C1.1, C2.2, U1.11 (0V2_1), U1.12 (0V2_2), U1.13 (VOUT1_1), U1.14 (VOUT1_2)
POE_AT_DET: R6.1, U12.4 (Collector); also elsewhere on the board
POE_BT3_DET: R7.1, U13.4 (Collector); also elsewhere on the board
POE_BT4_DET: R8.1, U14.4 (Collector); also elsewhere on the board
POE_MODE_A_AC1: D3.1 (A), D5.2 (K); also elsewhere on the board
POE_MODE_A_AC2: D4.1 (A), D6.2 (K); also elsewhere on the board
POE_MODE_B_AC1: D7.1 (A), D9.2 (K); also elsewhere on the board
POE_MODE_B_AC2: D8.1 (A), D10.2 (K); also elsewhere on the board
POE_RECT_NEG: D2.2 (A), D5.1 (A), D6.1 (A), D9.1 (A), D10.1 (A), U1.7 (VIN-); also elsewhere on the board
POE_RECT_POS: D2.1 (K), D3.2 (K), D4.2 (K), D7.2 (K), D8.2 (K), R3.1, R4.1, R5.1, U1.8 (VIN+); also elsewhere on the board

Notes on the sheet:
PoE input and isolation
Rev E circuit draft | Global labels connect sheets | Source component pin types still require review

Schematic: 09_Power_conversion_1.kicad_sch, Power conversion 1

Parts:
C3: 1000uF; C3_RevB; Voltage Rating 35V; Manufacturer Part Number EEUFR1V102
C4: 1000uF; C4_RevB; Voltage Rating 35V; Manufacturer Part Number EEUFR1V102
C40: 10uF; C40_RevB; Voltage Rating 50 V; Tolerance 10%; Manufacturer Part Number C1210C106K5RACTU
C41: 220nF; C41_RevB; Voltage Rating 50 V; Tolerance 10%; Manufacturer Part Number C0603C224K5RACTU
C42: 100nF; C42_RevB; Voltage Rating 50 V; Tolerance 10%; Manufacturer Part Number C0603C104K5RACTU
C43: 1uF; C43_RevB; Voltage Rating 16 V; Tolerance 10%; Manufacturer Part Number C0603C105K4RACTU
C44: 22uF; C44_RevB; Voltage Rating 25 V; Tolerance 10%; Manufacturer Part Number C1210C226K3RACTU
C45: 22uF; C45_RevB; Voltage Rating 25 V; Tolerance 10%; Manufacturer Part Number C1210C226K3RACTU
C46: 22uF; C46_RevB; Voltage Rating 25 V; Tolerance 10%; Manufacturer Part Number C1210C226K3RACTU
C47: 22uF; C47_RevB; Voltage Rating 25 V; Tolerance 10%; Manufacturer Part Number C1210C226K3RACTU
C48: 10uF; C48_RevB; Voltage Rating 16 V; Tolerance 10%; Manufacturer Part Number GRM21BR61C106KE15L
C49: 22uF; C49_RevB; Voltage Rating 16 V; Tolerance 20%; Manufacturer Part Number GRM21BR61C226ME44L
C50: 47uF; C50_RevB; Voltage Rating 16 V; Tolerance 10%; Manufacturer Part Number GRM32ER61C476KE15L
C53: 3.3nF; C53_RevB; Voltage Rating 50 V; Tolerance 5%; Manufacturer Part Number C0603C332J5GACTU
D11: SMBJ26CA; D11_RevB; Manufacturer Part Number SMBJ26CA
F1: 24T 3.15A250V; F1_RevB; Manufacturer Part Number 24T 3.15A250V; LCSC Part Number C2905508
J2: MX2EDGR-5.08-02P-GN01-Cu-A; J2_RevB; Manufacturer Part Number MX2EDGR-5.08-02P-GN01-Cu-A; LCSC Part Number C5187973
L3: 8.2uH; L3_RevB; Current Rating 4A; Part Type Inductor
L4: 2.2uH; L4_RevB; Current Rating 4A; Part Type Inductor
Q1: DMNH6012LK3-13; Q1_RevB; Manufacturer Part Number DMNH6012LK3-13
Q2: DMNH6012LK3-13; Q2_RevB; Manufacturer Part Number DMNH6012LK3-13

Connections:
3V3: C49.1, C50.1, L4.2; also elsewhere on the board
5V: C44.1, C45.1, C46.1, C47.1, C48.1, L3.2; also elsewhere on the board
24V_AMP: C3.1, C4.1, C40.1, C41.1; also elsewhere on the board
24V_BENCH_PROTECTED: Q2.3 (S); also elsewhere on the board
24V_BENCH_RAW: F1.1, J2.1; also elsewhere on the board
24V_OR: Q1.2 (D), Q2.2 (D); also elsewhere on the board
24V_POE: Q1.3 (S); also elsewhere on the board
BENCH_FUSED: D11.1 (K), F1.2; also elsewhere on the board
BENCH_OR_GATE: Q2.1 (G); also elsewhere on the board
BUCK3V3_SS: C53.1; also elsewhere on the board
BUCK3V3_SW: L4.1; also elsewhere on the board
BUCK5_BOOT: C42.1; also elsewhere on the board
BUCK5_SW: C42.2, L3.1; also elsewhere on the board
BUCK5_VCC: C43.1; also elsewhere on the board
GND: C3.2, C4.2, C40.2, C41.2, C43.2, C44.2, C45.2, C46.2, C47.2, C48.2, C49.2, C50.2, C53.2, D11.2 (A), J2.2; also elsewhere on the board
POE_OR_GATE: Q1.1 (G); also elsewhere on the board

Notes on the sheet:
Power conversion 1
Rev E circuit draft | Global labels connect sheets | Source component pin types still require review

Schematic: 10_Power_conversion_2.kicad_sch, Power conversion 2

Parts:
R23: 100kΩ; R23_RevB; Tolerance 1%; Power rating 0.10 W conservative; Part Type Resistor
R24: 24.9kΩ; R24_RevB; Tolerance 1%; Power rating 0.10 W conservative; Part Type Resistor
R35: 100kΩ; R35_RevB; Tolerance 1%; Power rating 0.10 W conservative; Part Type Resistor
R36: 100kΩ; R36_RevB; Tolerance 1%; Power rating 0.10 W conservative; Part Type Resistor
U6: LMR33630AQRNXRQ1; U6_RevB; Manufacturer Part Number LMR33630AQRNXRQ1
U7: TPS62132RGTR; U7_RevB; Part Type Integrated Circuit
U9: LM5050-2; U9_RevB; Manufacturer Part Number LM5050MK-2/NOPB
U10: LM5050-2; U10_RevB; Manufacturer Part Number LM5050MK-2/NOPB

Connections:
3V3: R36.2, U7.7 (FSW), U7.14 (VOS); also elsewhere on the board
3V3_PG: R36.1, U7.4 (PG); also elsewhere on the board
5V: R23.1, R35.2, U7.10 (AVIN), U7.11 (PVIN_1), U7.12 (PVIN_2), U7.13 (EN); also elsewhere on the board
5V_PG: R35.1, U6.8 (PG); also elsewhere on the board
24V_AMP: U6.2 (VIN), U6.9 (EN), U6.10 (VIN); also elsewhere on the board
24V_BENCH_PROTECTED: U10.4 (IN); also elsewhere on the board
24V_OR: U9.6 (OUT), U10.6 (OUT); also elsewhere on the board
24V_POE: U9.4 (IN); also elsewhere on the board
BENCH_OR_GATE: U10.5 (GATE); also elsewhere on the board
BUCK3V3_SS: U7.9 (SS/TR); also elsewhere on the board
BUCK3V3_SW: U7.1 (SW_1), U7.2 (SW_2), U7.3 (SW_3); also elsewhere on the board
BUCK5_BOOT: U6.4 (BST); also elsewhere on the board
BUCK5_FB: R23.2, R24.1, U6.7 (FB)
BUCK5_SW: U6.3 (NC), U6.12 (SW); also elsewhere on the board
BUCK5_VCC: U6.5 (VCC); also elsewhere on the board
GND: R24.2, U6.1 (PGND), U6.6 (AGND), U6.11 (PGND), U7.5 (FB), U7.6 (AGND), U7.8 (DEF), U7.15 (PGND_1), U7.16 (PGND_2), U7.17 (EP), U9.2 (GND), U9.3 (OFF), U10.2 (GND), U10.3 (OFF); also elsewhere on the board
POE_OR_GATE: U9.5 (GATE); also elsewhere on the board

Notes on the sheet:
Power conversion 2
Rev E circuit draft | Global labels connect sheets | Source component pin types still require review

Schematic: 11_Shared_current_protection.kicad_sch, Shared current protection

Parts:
C121: 100nF; C_1210_3225Metric; Voltage rating 50 V; Voltage Rating 100 V; Manufacturer Part Number C1210C104J1GACTU
C122: 1uF; C_1210_3225Metric; Voltage rating 100 V; Voltage Rating 100 V; Manufacturer Part Number C1210C105K1RACTU
C123: 1uF; C123_RevB; Voltage rating 50 V; Voltage Rating 50 V; Manufacturer Part Number C0805C105K5RACTU
R130: 6.04k; R130_RevB; Tolerance 1%; Power rating 0.125 W conservative; Manufacturer Part Number TNPW08056K04FHEA
R131: 200k; R131_RevB; Tolerance 0.1%; Power rating 0.125 W conservative; Manufacturer Part Number TNPW0805200KBYEA
R132: 10k; R132_RevB; Tolerance 0.1%; Power rating 0.125 W conservative; Manufacturer Part Number TNPW080510K0BYEA
R133: 158k; R133_RevB; Tolerance 1%; Power rating 0.125 W conservative; Manufacturer Part Number TNPW0805158KFHEA
R134: 10k; R134_RevB; Tolerance 1%; Power rating 0.125 W conservative; Manufacturer Part Number TNPW080510K0FHEA
R135: 1k; R135_RevB; Tolerance 1%; Power rating 0.125 W conservative; Manufacturer Part Number TNPW08051K00FHEA
R136: 174k; R136_RevB; Tolerance 1%; Power rating 0.125 W conservative; Manufacturer Part Number TNPW0805174KFHEA
R137: 10k; R137_RevB; Tolerance 1%; Power rating 0.125 W conservative; Manufacturer Part Number TNPW080510K0FHEA
R138: 10k; R138_RevB; Tolerance 1%; Power rating 0.125 W conservative; Manufacturer Part Number TNPW080510K0FHEA
TP26: EFUSE_SHDN; TP26_RevB; Manufacturer Part Number TBD
TP27: EFUSE_FAULT_N; TP27_RevB; Manufacturer Part Number TBD
U16: TPS26630RGER; U16_RevB; Manufacturer Part Number TPS26630RGER

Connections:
3V3: R138.2; also elsewhere on the board
24V_AMP: C123.1, R136.1, U16.17 (OUT), U16.18 (OUT); also elsewhere on the board
24V_OR: C122.1, R131.1, R133.1, U16.1 (IN), U16.2 (IN), U16.5 (IN_SYS); also elsewhere on the board
AMP_ENABLE_CMD: R135.1; also elsewhere on the board
AMP_SDZ: R135.2, U16.16 (PGOOD); also elsewhere on the board
EFUSE_DVDT: C121.1, U16.9 (dVdT)
EFUSE_FAULT_N: R138.1, TP27.1, U16.14 (~FLT)
EFUSE_ILIM: R130.1, U16.10 (ILIM)
EFUSE_OV: R131.2, R132.1, U16.7 (OVP)
EFUSE_PGTH: R136.2, R137.1, U16.15 (PGTH)
EFUSE_SHDN: TP26.1, U16.12 (~SHDN)
EFUSE_UV: R133.2, R134.1, U16.6 (UVLO)
GND: C121.2, C122.2, C123.2, R130.2, R132.2, R134.2, R137.2, U16.8 (GND), U16.25 (GND); also elsewhere on the board

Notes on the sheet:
Shared current protection
Rev E circuit draft | Global labels connect sheets | Source component pin types still require review

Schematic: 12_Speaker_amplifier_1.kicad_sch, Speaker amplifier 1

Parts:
C5: 100uF; C5_RevB; Voltage Rating 50V; Manufacturer Part Number EEUFR1H101
C6: 100uF; C6_RevB; Voltage Rating 50V; Manufacturer Part Number EEUFR1H101
C7: 220nF; C7_RevB; Voltage Rating 50 V; Tolerance 10%; Manufacturer Part Number C0603C224K5RACTU
C8: 220nF; C8_RevB; Voltage Rating 50 V; Tolerance 10%; Manufacturer Part Number C0603C224K5RACTU
C9: 220nF; C9_RevB; Voltage Rating 50 V; Tolerance 10%; Manufacturer Part Number C0603C224K5RACTU
C10: 220nF; C10_RevB; Voltage Rating 50 V; Tolerance 10%; Manufacturer Part Number C0603C224K5RACTU
C11: 1uF; C11_RevB; Voltage Rating 16 V; Tolerance 10%; Manufacturer Part Number C0603C105K4RACTU
C12: 1uF; C12_RevB; Voltage Rating 100 V; Tolerance 10%; Manufacturer Part Number C1210C105K1RACTU
C13: 1uF; C13_RevB; Voltage Rating 100 V; Tolerance 10%; Manufacturer Part Number C1210C105K1RACTU
C14: 1uF; C14_RevB; Voltage Rating 100 V; Tolerance 10%; Manufacturer Part Number C1210C105K1RACTU
C15: 1uF; C15_RevB; Voltage Rating 100 V; Tolerance 10%; Manufacturer Part Number C1210C105K1RACTU
C16: 1uF; C16_RevB; Voltage Rating 100 V; Tolerance 10%; Manufacturer Part Number C1210C105K1RACTU
C17: 2.2uF; C17_RevB; Voltage Rating 25 V; Tolerance 10%; Manufacturer Part Number C0805C225K3RACTU
C18: 2.2uF; C18_RevB; Voltage Rating 25 V; Tolerance 10%; Manufacturer Part Number C0805C225K3RACTU
C58: 1uF; C58_RevB; Voltage Rating 16 V; Tolerance 10%; Manufacturer Part Number C0603C105K4RACTU
J3: MX2EDGR-5.08-02P-GN01-Cu-A; J3_RevB; Manufacturer Part Number MX2EDGR-5.08-02P-GN01-Cu-A; LCSC Part Number C5187973
L1: 10uH; L1_RevB; Current Rating 5A; Part Type Inductor
L2: 10uH; L2_RevB; Current Rating 5A; Part Type Inductor
R14: 5.6kΩ; R14_RevB; Tolerance 1%; Power rating 0.10 W conservative; Part Type Resistor
R15: 82kΩ; R15_RevB; Power Rating 0.1; Tolerance 1%; Part Type Resistor
R16: 51kΩ; R16_RevB; Power Rating 0.1; Tolerance 1%; Part Type Resistor

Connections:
24V_AMP: C5.1, C6.1, C12.1, C13.1, C14.1, C15.1; also elsewhere on the board
AMP_BSNL: C7.1; also elsewhere on the board
AMP_BSNR: C9.1; also elsewhere on the board
AMP_BSPL: C8.1; also elsewhere on the board
AMP_BSPR: C10.1; also elsewhere on the board
AMP_GAIN: R14.1; also elsewhere on the board
AMP_GVDD: C11.1, R15.1; also elsewhere on the board
AMP_IN_N: C18.2; also elsewhere on the board
AMP_IN_P: C17.2; also elsewhere on the board
AMP_PLIMIT: C58.1, R15.2, R16.1; also elsewhere on the board
AMP_SW_NEG: C7.2, C8.2, L2.1; also elsewhere on the board
AMP_SW_POS: C9.2, C10.2, L1.1; also elsewhere on the board
DAC_OUT_FILTERED: C17.1; also elsewhere on the board
GND: C5.2, C6.2, C11.2, C12.2, C13.2, C14.2, C15.2, C18.1, C58.2, R14.2, R16.2; also elsewhere on the board
SPK_NEG: C16.2, J3.2, L2.2
SPK_POS: C16.1, J3.1, L1.2

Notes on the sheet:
Speaker amplifier 1
Rev E circuit draft | Global labels connect sheets | Source component pin types still require review

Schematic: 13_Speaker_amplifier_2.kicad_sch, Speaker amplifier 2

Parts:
R17: 10kΩ; R17_RevB; Tolerance 1%; Power rating 0.10 W conservative; Part Type Resistor
U5: TPA3116D2; U5_RevB; Part Type Integrated Circuit

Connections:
3V3: R17.1; also elsewhere on the board
24V_AMP: U5.17 (AVCC), U5.18 (PVCC), U5.19 (PVCC), U5.31 (PVCC), U5.32 (PVCC); also elsewhere on the board
AMP_BSNL: U5.20 (BSNL); also elsewhere on the board
AMP_BSNR: U5.26 (BSNR); also elsewhere on the board
AMP_BSPL: U5.24 (BSPL); also elsewhere on the board
AMP_BSPR: U5.30 (BSPR); also elsewhere on the board
AMP_FAULTZ: R17.2, U5.3 (FAULTZ); also elsewhere on the board
AMP_GAIN: U5.8 (GAIN/SLV); also elsewhere on the board
AMP_GVDD: U5.7 (GVDD); also elsewhere on the board
AMP_IN_N: U5.5 (RINN); also elsewhere on the board
AMP_IN_P: U5.4 (RINP); also elsewhere on the board
AMP_MUTE: U5.12 (MUTE); also elsewhere on the board
AMP_PLIMIT: U5.6 (PLIMIT); also elsewhere on the board
AMP_SDZ: U5.2 (SDZ); also elsewhere on the board
AMP_SW_NEG: U5.21 (OUTNL), U5.23 (OUTPL); also elsewhere on the board
AMP_SW_POS: U5.27 (OUTNR), U5.29 (OUTPR); also elsewhere on the board
GND: U5.1 (MODSEL), U5.9 (GND), U5.10 (LINP), U5.11 (LINN), U5.13 (AM2), U5.14 (AM1), U5.15 (AM0), U5.22 (GND), U5.25 (GND), U5.28 (GND); also elsewhere on the board

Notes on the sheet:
Speaker amplifier 2
Rev E circuit draft | Global labels connect sheets | Source component pin types still require review

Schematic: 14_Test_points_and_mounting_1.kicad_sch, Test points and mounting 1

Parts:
H1: MountingHole; H1_RevB; Manufacturer Part Number MountingHole
H2: MountingHole; H2_RevB; Manufacturer Part Number MountingHole
H3: MountingHole; H3_RevB; Manufacturer Part Number MountingHole
H4: MountingHole; H4_RevB; Manufacturer Part Number MountingHole
TP1: Generic Testpoint; TP1_RevB; Part Type Test Point
TP2: Generic Testpoint; TP2_RevB; Part Type Test Point
TP3: Generic Testpoint; TP3_RevB; Part Type Test Point
TP4: Generic Testpoint; TP4_RevB; Part Type Test Point
TP5: Generic Testpoint; TP5_RevB; Part Type Test Point
TP6: Generic Testpoint; TP6_RevB; Part Type Test Point
TP7: Generic Testpoint; TP7_RevB; Part Type Test Point
TP8: Generic Testpoint; TP8_RevB; Part Type Test Point
TP9: Generic Testpoint; TP9_RevB; Part Type Test Point
TP10: Generic Testpoint; TP10_RevB; Part Type Test Point
TP11: Generic Testpoint; TP11_RevB; Part Type Test Point
TP12: Generic Testpoint; TP12_RevB; Part Type Test Point
TP13: Generic Testpoint; TP13_RevB; Part Type Test Point
TP14: Generic Testpoint; TP14_RevB; Part Type Test Point
TP15: Generic Testpoint; TP15_RevB; Part Type Test Point
TP16: Generic Testpoint; TP16_RevB; Part Type Test Point
TP17: Generic Testpoint; TP17_RevB; Part Type Test Point

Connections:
3V3: TP5.1; also elsewhere on the board
5V: TP4.1; also elsewhere on the board
24V_AMP: TP3.1; also elsewhere on the board
AMP_FAULTZ: TP14.1; also elsewhere on the board
AMP_SDZ: TP13.1; also elsewhere on the board
ETH_SPI_MOSI: TP11.1; also elsewhere on the board
ETH_SPI_SCLK: TP10.1; also elsewhere on the board
GND: TP6.1; also elsewhere on the board
I2S_BCLK: TP7.1; also elsewhere on the board
I2S_DATA: TP9.1; also elsewhere on the board
I2S_LRCLK: TP8.1; also elsewhere on the board
PDM_CLK: TP15.1; also elsewhere on the board
PDM_DATA0: TP16.1; also elsewhere on the board
PDM_DATA1: TP17.1; also elsewhere on the board
PHY_nRESET: TP12.1; also elsewhere on the board
POE_RECT_NEG: TP2.1; also elsewhere on the board
POE_RECT_POS: TP1.1; also elsewhere on the board

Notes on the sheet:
Test points and mounting 1
Rev E circuit draft | Global labels connect sheets | Source component pin types still require review

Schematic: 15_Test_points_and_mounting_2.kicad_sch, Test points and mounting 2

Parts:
TP18: Generic Testpoint; TP18_RevB; Part Type Test Point
TP19: Generic Testpoint; TP19_RevB; Part Type Test Point
TP20: Generic Testpoint; TP20_RevB; Part Type Test Point
TP21: Generic Testpoint; TP21_RevB; Part Type Test Point
TP22: Generic Testpoint; TP22_RevB; Part Type Test Point
TP23: Generic Testpoint; TP23_RevB; Part Type Test Point

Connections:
3V3A: TP20.1; also elsewhere on the board
24V_BENCH_PROTECTED: TP22.1; also elsewhere on the board
24V_BENCH_RAW: TP21.1; also elsewhere on the board
24V_POE: TP23.1; also elsewhere on the board
PDM_DATA2: TP18.1; also elsewhere on the board
PDM_DATA3: TP19.1; also elsewhere on the board

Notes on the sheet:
Test points and mounting 2
Rev E circuit draft | Global labels connect sheets | Source component pin types still require review



Board: 4 copper layers, 210.0 x 100.0 mm, 209 parts (7 on the bottom side), 127 nets.

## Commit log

2026-09-15 Add validated Rev E source packages and engineering review guide
    Upload the saved KiCad prototype checkpoint, board preview and review priorities. Preserve the existing MIT license. This design is not approved for fabrication or power-up; clean saved checks do not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
2026-09-15 Add first prototype validation plan
2026-09-15 Add extracted KiCad source and project structure
    [02_Bench_protection.kicad_sch, 02_Controller_and_programming.kicad_sch, 03_Controller_and_programming.kicad_sch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]
2026-09-15 Add microphone ring development track
2026-09-15 Document 8-inch reference speaker for first microphone ring prototype
2026-09-15 Document microphone ring status LED plan
2026-09-15 Add KiCad and editor ignore rules
2026-09-15 Refresh project README for current repository structure
2026-09-15 Remove KiCad local session state
2026-09-15 Revise project disclaimer for clarity and detail
    Updated project disclaimer to clarify the author's background and the project's current status as an engineering prototype.
2026-09-15 Add historical board render
2026-09-15 Document earlier board render
2026-09-16 updated board image with png image
2026-09-16 Replace board render with PNG
2026-09-16 Verify Ethernet PHY and MagJack pin mapping for #1
2026-09-16 Shorten RX positive branch routing for #1
    [PoE-Speaker-RevE.kicad_pcb]
2026-09-16 Move TX positive ESD branch to front copper for #1
    [PoE-Speaker-RevE.kicad_pcb]
2026-09-17 Route shared front-layer TX trunk and relocate termination for #1
    [PoE-Speaker-RevE.kicad_pcb]
2026-09-17 Increase central TX/RX pair separation for #1
    [PoE-Speaker-RevE.kicad_pcb]
2026-09-17 Extend RX separation through PHY approach for #1
    [PoE-Speaker-RevE.kicad_pcb]
2026-09-28 release: RevF manufacturing handoff
    Merged finalized RevF manufacturing handoff and front-page board preview.
    [2250506-1.stp, ESP32-S3-WROOM-1U-N16R8--3DModel-STEP-56544.STEP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]

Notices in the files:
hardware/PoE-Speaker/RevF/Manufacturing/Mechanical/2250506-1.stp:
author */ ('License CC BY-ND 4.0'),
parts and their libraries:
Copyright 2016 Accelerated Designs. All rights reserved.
